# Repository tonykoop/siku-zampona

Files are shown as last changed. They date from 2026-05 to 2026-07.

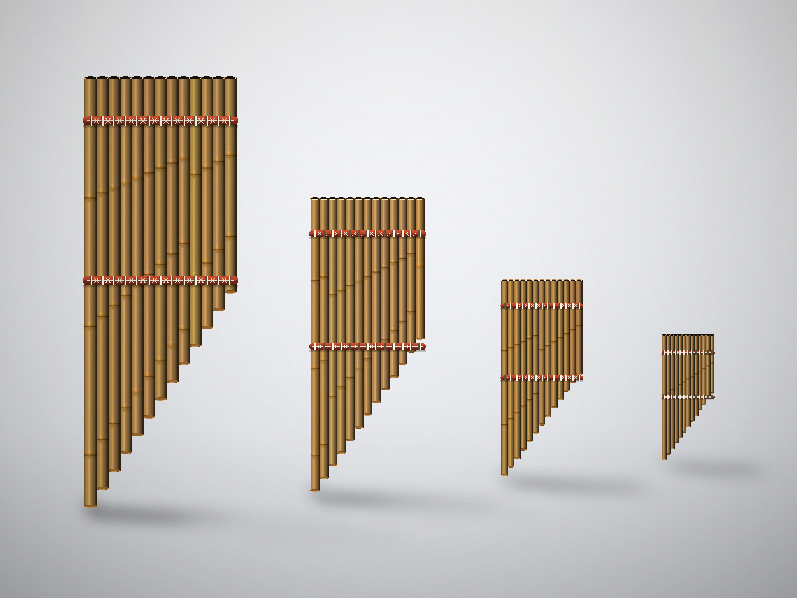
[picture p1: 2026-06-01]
images/family-group.png

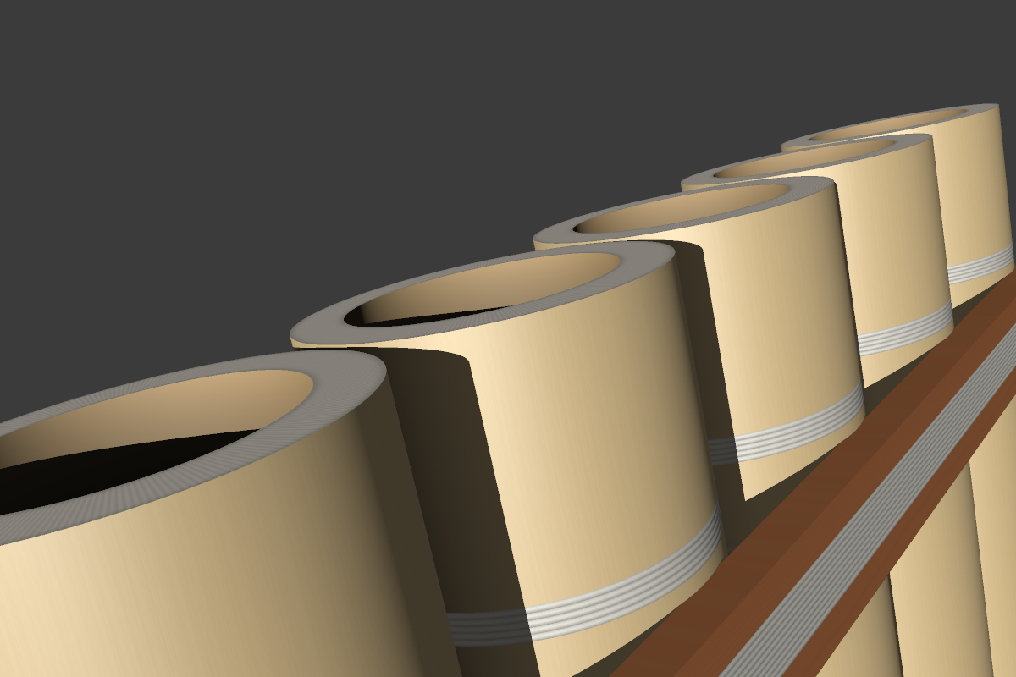
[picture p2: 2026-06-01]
images/macro/blow-edge-tube-mouths.png

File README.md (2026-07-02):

# Siku (Zampoña)

**Status:** L2 V5 build-packet candidate · Heifer Zephyr · instrument-maker-v4 · packet v4.3 · 2026-05-08

Engineering documentation for the *siku* (Aymara: *siku'*, Spanish: *zampoña*) — the Andean panpipe, built as a four-member family in a complete v4.3 root-mode packet.

The siku is played in interlocking arka/ira pairs. Neither rank alone contains the full scale — two players weave a melody together, embodying *yanantin*, the Aymara philosophy of complementary pairing.

---

## Family Overview

| Member | Key | Bore ID | OD | Tubes | Longest | Shortest | Frame Width |
|---|---|---|---|---|---|---|---|
| Toyo (bass) | G3 | 0.750" | 1.000" | 13 | 22.646" | 7.064" | 13.750" |
| **Zanka (tenor)** | **C4** | **0.625"** | **0.821"** | **13** | **16.961"** | **4.814"** | **11.423"** |
| Malta (alto) | G4 | 0.500" | 0.658" | 13 | 11.315" | 3.261" | 9.304" |
| Chili (soprano) | A4 | 0.375" | 0.493" | 13 | 7.565" | 1.982"⚠ | 7.159" |

**Primary build target: Zanka.** The Zanka is the main melodic voice in traditional Andean ensembles and the best starting point for a first build.

⚠ Chili Arka-7 (F#6, 1.982" / 50mm) is at the practical playability limit — see `risks.md` AC-04. Consider building the Chili as an 11-tube instrument.

---

## Arka / Ira Split (Zanka example)

| Rank | Tubes | Notes | Semitone offsets |
|---|---|---|---|
| Arka (leader ♀) | 7 | G3 B3 D4 F4 A4 C5 E5 | 0 4 7 10 14 17 21 |
| Ira (follower ♂) | 6 | A3 C4 E4 G4 B4 D5 | 2 5 9 12 16 19 |

Combined: G Mixolydian scale (G A B C D E F♮ G A B C D E)

---

## Tube Length Formula

```
L_calc  = 13552 / (4 × f_hz) − 0.82 × bore_ID
L_cut   = L_calc + 3/16"    (trim allowance)
```

- Speed of sound: 13,552 in/s at 68°F
- End correction: 0.82 × bore_ID (empirical; bundles embouchure effects)
- Stopped pipe: odd harmonics only (1f, 3f, 5f …)
- Tuning: A4 = 440 Hz, equal temperament

Sanity check: `L_calc(A4, bore=0.625") = 13552/(4×440) − 0.82×0.625 = 7.188"`

---

## Packet Contents

| File | Description |
|---|---|
| `design.md` | Governing model, provenance, tube length tables, arka/ira split |
| `family-spec.csv` | All 4 members with bore, wall, tube lengths, Hz values |
| `bom.csv` | Full bill of materials |
| `sourcing.csv` | Suppliers with substitute risk ratings |
| `cut-list.csv` | 52 tube cuts + 4 frame rail cuts |
| `validation.csv` | Per-tube validation targets (Hz, cents tolerance) |
| `assembly-manual.md` | 8-phase build manual |
| `risks.md` | 11 structured risks with verification tests |
| `jig-decision.md` | Fixture selection for each manufacturing operation |
| `cnc/setup-sheet.md` | Machine datums, tooling, release checks for all operations |
| `cnc/operations.csv` | Machine-readable operation list |
| `wolfram/instrument-model.wl` | Interactive tube-length explorer (Wolfram Mathematica) |
| `drawings/` | 10 dimensioned SVG drawings |
| `site/index.html` | Build-log site — open in browser |
| `resources.md` | Acoustic and ethnomusicological references |
| `photo-shotlist.md` | 36-shot photo list |
| `supplier-rfq.md` | RFQ templates for materials |
| `siku-zampona-design-table.xlsx` | Master design table (all 4 members) |
| `cad/siku-zampona.scad` | Parametric OpenSCAD master — two-rank closed-tube envelope (`pending_measurement`) |
| `evolution/` | Evolution-pipeline Stage 0 intake (manifest, design-intent, revision register) |

---

## Build in Brief

1. **Verify stock** — measure bore ID and OD of all incoming bamboo or PVC; record in `validation.csv`
2. **Cut tubes** — story stick method (bamboo) or digital stop (PVC); 52 tubes total across 4 members
3. **Seal ends** — pour beeswax plug to 3/8" depth; stand in plywood sealing fixture while curing
4. **First-pass tuning** — measure all tubes with chromatic tuner; record deviation in cents
5. **Mill frame rails** — CNC-route 13 tube pockets in cherry/walnut rail; pocket width = OD − 0.005"
6. **Bind** — seat tubes in rail pockets; wrap with waxed cord; square-knot at ends
7. **Trim-tune** — file/saw open ends to ±5 cents; update `validation.csv`
8. **Finish** — Danish oil on rails; tung oil wipe on bamboo; photograph

---

## Related Repos

- [tonykoop/instrument-maker](https://github.com/tonykoop/instrument-maker) — parent catalog and skill
- [tonykoop/transverse-flute](https://github.com/tonykoop/transverse-flute) — stopped-pipe family baseline
- [tonykoop/gemshorn](https://github.com/tonykoop/gemshorn) — vessel-flute family; reference for `family-spec.csv` format

---

## Cultural Provenance

The siku is a living cultural artifact of the Aymara and Quechua peoples of Bolivia and Peru, with a documented history extending to at least 1500 BCE (Tiwanaku, Nazca archaeological sites).

This repository documents a **contemporary workshop interpretation** built using modern CNC and PVC/bamboo materials. It makes no claim of cultural authenticity.

Before writing public-facing documentation, captions, or README text for forks, please read:
- Thomas Turino — *Moving Away from Silence* (Chicago, 1993): essential ethnography of siku in Aymara culture
- `resources.md §Provenance` — five-point guidance checklist in this packet
- Describe the instrument as "Andean Aymara/Quechua in origin" (not "Incan" or generically "South American")
- Acknowledge *yanantin* — the interlocking duet design is not decorative; it embodies a cultural philosophy

---

## License

[CC BY 4.0](LICENSE) — engineering documentation only. Attribution: Tony Koop / Heifer Zephyr.  
This license covers the build packet. It is not a claim of ownership over the siku tradition.

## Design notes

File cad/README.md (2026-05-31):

# Siku (Zampoña) — CAD

**Refs:** https://github.com/tonykoop/siku-zampona/issues/1
Generated: 2026-05-19

This folder is a placeholder. No native CAD model lives here yet.

## Current Dimensional Authority

Until reviewed native CAD lands in this folder, the authoritative dimensional
sources for the siku family — in priority order — are:

1. **`siku-zampona-design-table.xlsx`** — the parametric design table
   extracted from the master Musical Instruments workbook. Source of every
   tube length, bore, frame width, and family-member row.
2. **`wolfram/instrument-model.wl`** + **`wolfram-starter.wl`** — Manipulate
   model implementing the stopped-pipe formula
   `L_calc = 13552 / (4·f) − 0.82·bore_ID`. Source of truth for sensitivity
   sweeps and end-correction reasoning.
3. **`drawings/siku-{toyo,zanka,malta,chili}-{elevation,frame}.svg`,
   `siku-family-overview.svg`, `siku-tube-section.svg`** — dimensioned SVG
   drawings for each family member, plus the cross-section and the
   family-overview comparison sheet.
4. **`cut-list.csv`** — concrete numeric envelope per tube, derived from
   items 1–3.

## What Belongs Here Later

This folder is reserved for native CAD that an outside builder can open
and re-mesh:

- A SolidWorks design-table workbook driven from the canonical template
  documented at the instrument-maker-v4 SolidWorks reference for siku
  (`assets/solidworks/family-templates/siku-zampona-design-table.csv`).
- STEP exports of each family member's frame and tube layout.
- Optionally, F3D or Fusion 360 native, OnShape JSON exports, or
  parametric OpenSCAD source if a CAD pivot away from SolidWorks happens.

Any binary CAD file landed here must be paired with a sibling text export
(STEP, IGES, STL, or OpenSCAD source) so that the geometry is reviewable
without the proprietary tool.

## Honesty Rules

The following rules bind every future PR that adds files to this folder:

- A `.glb`, render, or screenshot is **not** CAD; it belongs in
  `images/`.
- A DXF marked "review scaffold" is not L3 CAD; mark it explicitly and
  note the residual in `build-packet-status.md`.
- A "SolidWorks model" claim requires the actual `.sldprt`/`.sldasm` file
  *and* a STEP or IGES sibling. Otherwise the row in
  `build-packet-status.md` stays `partial` or `open`.
- A generated visual (Wolfram render, AI image, or marketing illustration)
  must not be filed here. It belongs in `images/` with concept-only
  framing per `visual-bom-brief.md`.

## Cross-References

- `build-packet-status.md` — overall packet readiness; CAD row tracked
  there.
- `drawing-brief.md` — the Strat-quality drawing requirements that any
  future CAD must satisfy.
- `visual-bom-brief.md` — separates fabrication geometry from concept
  visuals.

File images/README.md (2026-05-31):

# Siku (Zampoña) — Images

**Refs:** https://github.com/tonykoop/siku-zampona/issues/1
Generated: 2026-05-19

This folder is a placeholder. No hero photo, concept render, or build photo
lives here yet.

## Photo Plan

The authoritative shot list — what to shoot, in what order, with which
neutral background and which scale reference — lives in
**`photo-shotlist.md`** at the repo root. Read that file before adding any
file to this folder.

`photo-shotlist.md` defines groups RAW, CUT, ASM, FIN, PLAY, and HERO with
explicit shot IDs (RAW-01, CUT-03, etc.). When a real image lands here, it
should be filed under the shot ID, e.g. `images/RAW-01-bamboo-culm.jpg`.

## What Belongs Here

- **Build photos** taken during a real Zanka or family-member build,
  matching shot IDs from `photo-shotlist.md`.
- **Hero photo** of a finished instrument, owned by the photographer with
  licence recorded.
- **Concept renders** clearly framed as concept-only per
  `visual-bom-brief.md`. File these alongside a sibling
  `<filename>.provenance.md` that records the generator (Wolfram, AI tool,
  hand-illustration), the prompt or notebook cell, and the licence
  posture.

## What Does Not Belong Here

- **Native CAD files** — those belong in `cad/`.
- **Dimensioned drawings** — those belong in `drawings/`.
- **Anonymous AI-generated images with no provenance record** — see
  `visual-bom-brief.md` and the v4.3 provenance convention; an image
  without a sibling provenance note must not land here.
- **Photos of historical or museum instruments** without documented
  permission or a clear public-domain trace.

## Honesty Rules

- Until a real photo lands here, `README.md` must not show a hero image
  claiming to depict a built siku from this repo.
- A render of a CAD model is a render, not a photo. Caption accordingly.
- Photos taken during another maker's build must record consent and the
  maker's name.

## Cross-References

- `photo-shotlist.md` — canonical shot list and shot IDs.
- `visual-bom-brief.md` — image-per-row BOM layout requirements.
- `build-packet-status.md` — overall packet readiness; image row tracked
  there.

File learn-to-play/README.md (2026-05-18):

# learn-to-play / Siku/Zampona (G)

Starter songbook for the G siku/zampona panpipe from the build packet. Generated by the sheet-music skill.

The siku splits notes across pipe rows and often across two players. These studies keep the hocket pattern visible and beginner-friendly.

Range: **G4 - B5 core range, with optional upper-row extensions.**

## Folder map
| Folder | Contents |
|---|---|
| `00-warmup-scales/` | Row-to-row range walk, thirds hocket, breath-reset drill |
| `01-easy/` | Three beginner melodies arranged for alternating pipe rows |
| `02-intermediate/` | Two hocket studies for paired ira/arca practice |
| `03-original/` | *Reed Rows Round* - Heifer Zephyr original |
| `fingering-charts.svg` | Pipe-row map and G pentatonic fingering chart |

## Repertoire

### 01-easy
| Tune | Tradition |
|---|---|
| Call and Answer | Original beginner exercise |
| Twinkle Twinkle Little Star | Mozart K.265 theme (1781) |
| Wayfaring Stranger | American folk hymn, public domain |

### 02-intermediate
| Tune | Tradition |
|---|---|
| Two-Row Huayno | Original Andean-style hocket study |
| Pipe Row Canon | Original paired-player study |

### 03-original
**Reed Rows Round** - 32-bar original hocket study, G pentatonic, quarter=96.

## Notes on notation
ABC files use concert pitch. Notes tagged in comments as ira/arca should be split between paired players where possible.

## L2 readiness and known gaps
This starter songbook is ready for L2 review as a playable packet draft: ABC melodies, per-tune notes, static fingering summaries, warmups, and a top-level chart are present. Known gaps: generated audio, MusicXML, LilyPond, MIDI, and printable songsheets are skipped until the shared render dependencies are available; fingering charts need builder review against the final hole layout.

## License
Arrangements MIT-licensed by Tony Koop / Heifer Zephyr. Public-domain tune provenance is listed in each `notes.md`. Original studies are MIT-licensed for performance, recording, arrangement, and adaptation.

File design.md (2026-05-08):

# Siku (Zampoña) — Design Document

**Instrument:** Siku / Zampoña (Andean Panpipe)  
**Family:** 4-member (Toyo bass · Zanka tenor · Malta alto · Chili soprano)  
**Play style:** 2-rank interlocking duet (arka ♀ + ira ♂) or single-player alternating  
**Packet version:** v4.3 root-mode  
**Date:** 2026-05-08  
**Workbook:** `siku-zampona-design-table.xlsx`

---

## 1. Cultural Provenance

The siku (Aymara: *siku'*; Spanish: *zampoña*) is the pre-Columbian panpipe of the Andean altiplano, with archaeological examples dating to at least 1500 BCE from Tiwanaku-culture sites in present-day Bolivia and Peru. The instrument is central to the Aymara philosophical concept of **yanantin** — complementarity or paired wholeness — expressed musically through the interlocking duet technique in which two players each hold one rank and together produce a continuous melody.

Traditional materials: *cañahueca* bamboo (giant Andean cane, *Guadua chacoensis*) or *suri* bamboo. Tubes sealed at the lower end with a natural node or with beeswax. Rows bound with cord (traditionally alpaca or llama fiber) and sometimes framed between two parallel wooden rails.

Contemporary builders use PVC, hardwood, or aluminium tubing where bamboo is not available. This packet covers all three substrate options, with bamboo as the default.

### Traditions and ensemble contexts

| Tradition | Region | Tuning | Notes |
|---|---|---|---|
| Siku de Pares | Bolivian altiplano | Diatonic major, slight sharp tendency | Paired arka+ira, played outdoors |
| Siku de la Costa | Peruvian coast | Pentatonic variants | Smaller size, indoor context |
| Sikuri conjunto | Bolivia, Peru | 4–6 instrument sizes | Full ensemble from Toyo to Chili |
| Contemporary workshop | Global | Equal temperament | CNC/lathe bore, reproducible |

---

## 2. Governing Physics Model

### 2.1 Stopped Pipe

Each siku tube is a **cylindrical closed pipe** — closed at one end (bottom node or wax plug), open at the other (blow end). The fundamental frequency:

```
f = c / (4 × L_eff)
```

where `L_eff` is the **effective acoustic length** = physical tube length + open-end correction:

```
L_eff = L_physical + ΔL_end
ΔL_end ≈ 0.82 × bore_diameter   (Tony's empirical convention, ≈ 0.41 × r open-end correction)
```

Solving for the physical tube length to cut:

```
L_physical = c / (4 × f) - 0.82 × bore_ID
```

**Speed of sound:** `c = 13,552 in/s` at 68°F / 20°C (Tony's shop standard).  
Temperature sensitivity: ±5°F shifts pitch by approximately ±0.9 cents. Validate in the shop at build temperature.

**Overtone series:** Stopped pipe produces only **odd harmonics** (1f, 3f, 5f, 7f…), giving the characteristic hollow, breathy tone color. This is the acoustic signature of the siku vs. open-pipe flutes that produce all harmonics.

### 2.2 Tuning Trim Allowance

All physical tube lengths in this packet include a **+3/16" (0.1875") trim allowance**. Final tuning is achieved by trimming from the open (blow) end. Tubes should never be lengthened after cutting — seal first, measure against a chromatic tuner, then trim in ≤1/32" increments.

### 2.3 Arka / Ira Split

The 13 tubes of a standard siku are divided into two ranks:

| Rank | Role | Tubes | Semitone offsets from root |
|---|---|---|---|
| **Arka** | leader (♀) | 7 tubes | 0, 4, 7, 10, 14, 17, 21 |
| **Ira** | follower (♂) | 6 tubes | 2, 5, 9, 12, 16, 19 |

Combined and sorted: `0, 2, 4, 5, 7, 9, 10, 12, 14, 16, 17, 19, 21`  
This gives **Mixolydian mode** (major scale with ♭7), spanning nearly 2 octaves. The "siku key" convention: the key letter names the **5th semitone above the root** (the 4th tube of the combined scale, which is the perfect fourth).

> Example: Root = D3 → siku key = G3 (D3 + 5 semitones).

### 2.4 Siku Key Naming Convention

```
siku_key_midi = root_midi + 5
```

| Size Class | Root Note | MIDI | Siku Key |
|---|---|---|---|
| Toyo (bass) | D3 | 38 | G3 |
| Zanka (tenor) | G3 | 43 | C4 |
| Malta (alto) | D4 | 50 | G4 |
| Chili (soprano) | A4 | 57 | D5 |

---

## 3. Family Specification

Four size classes cover the full Andean sikuri ensemble range. See `family-spec.csv` for complete per-member data.

### 3.1 Physical Dimensions

| Member | Size Class | Bore ID (in) | Wall (in) | OD (in) | Root Note | Siku Key |
|---|---|---|---|---|---|---|
| Toyo | Bass | 0.750 | 0.125 | 1.000 | D3 | G3 |
| Zanka | Tenor | 0.625 | 0.098 | 0.821 | G3 | C4 |
| Malta | Alto | 0.500 | 0.079 | 0.658 | D4 | G4 |
| Chili | Soprano | 0.375 | 0.059 | 0.493 | A4 | D5 |

### 3.2 Tube Length Tables

All lengths in inches. `L_calc` = formula result. `L_cut` = L_calc + 3/16" trim allowance.

#### Toyo (Bass) — Root D3 / Siku Key G3 / Bore 0.750"

| Tube | Note | Freq (Hz) | L_calc (in) | L_cut (in) |
|---|---|---|---|---|
| Arka 1 | D3 | 146.83 | 22.459 | 22.646 |
| Arka 2 | F#3 | 185.00 | 17.699 | 17.886 |
| Arka 3 | A3 | 220.00 | 14.785 | 14.973 |
| Arka 4 | C4 | 261.63 | 12.335 | 12.522 |
| Arka 5 | E4 | 329.63 | 9.663 | 9.851 |
| Arka 6 | G4 | 392.00 | 8.028 | 8.215 |
| Arka 7 | B4 | 493.88 | 6.245 | 6.432 |
| Ira 1 | E3 | 164.81 | 19.942 | 20.129 |
| Ira 2 | G3 | 196.00 | 16.671 | 16.858 |
| Ira 3 | B3 | 246.94 | 13.105 | 13.292 |
| Ira 4 | D4 | 293.66 | 10.922 | 11.109 |
| Ira 5 | F#4 | 369.99 | 8.542 | 8.729 |
| Ira 6 | A4 | 440.00 | 7.085 | 7.272 |

**Longest:** 22.459" (Arka 1) · **Shortest:** 6.245" (Arka 7) · **Frame width:** 13.750"

#### Zanka (Tenor) — Root G3 / Siku Key C4 / Bore 0.625"

| Tube | Note | Freq (Hz) | L_calc (in) | L_cut (in) |
|---|---|---|---|---|
| Arka 1 | G3 | 196.00 | 16.773 | 16.961 |
| Arka 2 | B3 | 246.94 | 13.207 | 13.395 |
| Arka 3 | D4 | 293.66 | 11.024 | 11.212 |
| Arka 4 | F4 | 349.23 | 9.189 | 9.376 |
| Arka 5 | A4 | 440.00 | 7.188 | 7.375 |
| Arka 6 | C5 | 523.25 | 5.962 | 6.150 |
| Arka 7 | E5 | 659.26 | 4.627 | 4.814 |
| Ira 1 | A3 | 220.00 | 14.888 | 15.075 |
| Ira 2 | C4 | 261.63 | 12.437 | 12.625 |
| Ira 3 | E4 | 329.63 | 9.766 | 9.953 |
| Ira 4 | G4 | 392.00 | 8.130 | 8.318 |
| Ira 5 | B4 | 493.88 | 6.347 | 6.535 |
| Ira 6 | D5 | 587.33 | 5.256 | 5.443 |

**Longest:** 16.773" (Arka 1) · **Shortest:** 4.627" (Arka 7) · **Frame width:** 11.423"

#### Malta (Alto) — Root D4 / Siku Key G4 / Bore 0.500"

| Tube | Note | Freq (Hz) | L_calc (in) | L_cut (in) |
|---|---|---|---|---|
| Arka 1 | D4 | 293.66 | 11.127 | 11.314 |
| Arka 2 | F#4 | 369.99 | 8.747 | 8.934 |
| Arka 3 | A4 | 440.00 | 7.290 | 7.478 |
| Arka 4 | C5 | 523.25 | 6.065 | 6.252 |
| Arka 5 | E5 | 659.26 | 4.729 | 4.917 |
| Arka 6 | G5 | 783.99 | 3.911 | 4.099 |
| Arka 7 | B5 | 987.77 | 3.020 | 3.207 |
| Ira 1 | E4 | 329.63 | 9.868 | 10.056 |
| Ira 2 | G4 | 392.00 | 8.233 | 8.420 |
| Ira 3 | B4 | 493.88 | 6.450 | 6.637 |
| Ira 4 | D5 | 587.33 | 5.358 | 5.546 |
| Ira 5 | F#5 | 739.99 | 4.168 | 4.356 |
| Ira 6 | A5 | 880.00 | 3.440 | 3.627 |

**Longest:** 11.127" (Arka 1) · **Shortest:** 3.020" (Arka 7) · **Frame width:** 9.304"

#### Chili (Soprano) — Root A4 / Siku Key D5 / Bore 0.375"

| Tube | Note | Freq (Hz) | L_calc (in) | L_cut (in) |
|---|---|---|---|---|
| Arka 1 | A4 | 440.00 | 7.393 | 7.580 |
| Arka 2 | C#5 | 554.37 | 5.804 | 5.991 |
| Arka 3 | E5 | 659.26 | 4.832 | 5.019 |
| Arka 4 | G5 | 783.99 | 4.014 | 4.201 |
| Arka 5 | B5 | 987.77 | 3.122 | 3.310 |
| Arka 6 | D6 | 1174.66 | 2.577 | 2.764 |
| Arka 7 | F#6 | 1479.98 | 1.982 | 2.169 |
| Ira 1 | B4 | 493.88 | 6.552 | 6.740 |
| Ira 2 | D5 | 587.33 | 5.461 | 5.648 |
| Ira 3 | F#5 | 739.99 | 4.271 | 4.458 |
| Ira 4 | A5 | 880.00 | 3.542 | 3.730 |
| Ira 5 | C#6 | 1108.73 | 2.748 | 2.936 |
| Ira 6 | E6 | 1318.51 | 2.262 | 2.450 |

**Longest:** 7.393" (Arka 1) · **Shortest:** 1.982" (Arka 7) · **Frame width:** 7.159"

> ⚠️ **Chili Arka 7 (F#6 = 1.982"):** This 50 mm tube is at the practical lower limit for panpipe embouchure control. Traditional ensembles often omit the highest 1–2 tubes of the Chili. Confirm playability before including in a build. See `risks.md` #AC-04.

---

## 4. Binding and Frame Layout

### 4.1 Tube Array Geometry

Tubes are arranged in descending-length order, longest at left (bass), shortest at right (treble). The two ranks (arka and ira) are bound as separate instruments; in duet play, the players hold one rank each side by side.

**Standard tube spacing:** OD + 1/16" (0.0625") gap between tube centerlines.  
Tubes align flush at the blow end (top). A stepped profile descends to the right.

**Frame cross-section:**

```
[Top rail] ────────────────────────────────────
  ○  ○  ○  ○  ○  ○  ○  ○  ○  ○  ○  ○  ○    ← 13 tubes (arka 7 + ira 6)
[Bottom rail] — stepped or cut to tube profile
```

### 4.2 Binding Methods

| Method | Description | Traditional? | Durability |
|---|---|---|---|
| Cord wrap | Waxed cotton or alpaca cord, 2–4 bands | Yes | Good |
| Frame lash | Tubes between two thin wooden rails, cord lashed | Semi-traditional | Better |
| CNC frame notch | Rails with individual tube pockets routed in | Contemporary | Best alignment |
| Epoxy + frame | Rails glued to tubes | Workshop/contemporary | Best (non-reversible) |

**Recommended for CNC build:** CNC-notched frame. Route tube pockets ≈ 1/3 OD depth into the face of each rail. Rail thickness: 3/8" to 1/2". Rail width: 1" to 1.5". Species: cherry, walnut, or maple.

### 4.3 Frame Dimensions Summary

| Member | # Tubes | OD (in) | Gap (in) | Frame Width (in) | Rail Length (in) |
|---|---|---|---|---|---|
| Toyo | 13 | 1.000 | 0.063 | 13.750 | 13.750 + 0.5 overhang each end |
| Zanka | 13 | 0.821 | 0.063 | 11.423 | 11.423 + 0.5 overhang |
| Malta | 13 | 0.658 | 0.063 | 9.304 | 9.304 + 0.5 overhang |
| Chili | 13 | 0.493 | 0.063 | 7.159 | 7.159 + 0.5 overhang |

### 4.4 Tube Sealing

Closed end (bottom): options in order of traditionality and performance:

1. **Natural bamboo node** — bamboo blank cut so a node falls at the correct closed-end position. Best tone, traditional. Requires careful blank selection.
2. **Beeswax plug** — melt beeswax into tube bottom, let harden. Used for tuning adjustment. Also used to close PVC or bamboo without a node.
3. **Wood dowel plug** — turned to press fit, glued. Good for hardwood or PVC tubes.
4. **Cork plug** — easy, reversible. Slight tone dampening at the closed end (adds small effective length → slight pitch-flat tendency). Correct by trimming 1/16" from open end if using cork.

**Wax plug acoustic note:** Beeswax has high acoustic impedance at this scale; the reflection at the wax-air boundary is nearly ideal for a stopped pipe. Cork is slightly less reflective. Cork-plugged tubes may run ~5–10 cents flat vs. wax/node — account for this in final trim.

---

## 5. CNC and Lathe Notes

See `cnc/setup-sheet.md` for the full operation plan.

### 5.1 Bamboo Blanks

- Select blanks with consistent internal bore (cañahueca splits most predictably with 3–4 mm wall thickness in the Andean species).
- Bore diameter should match the design table. Natural bamboo bore varies ±1–2 mm; oversized bore raises pitch (shorter effective length correction), undersized lowers it.
- Use headstock-driven deep-bore drilling (see `references/techniques/headstock-driven-deep-bore-drilling.md`) when boring hardwood or PVC blanks to the target bore ID from solid stock.

### 5.2 Hardwood or PVC Tubes

For a CNC-shop build without cane:

- **PVC Schedule 40 pipe:** widely available; bore IDs match close enough for Zanka (3/4" nominal ≈ 0.824" ID, use for Toyo; 1/2" nominal ≈ 0.622" ID for Zanka). Verify actual ID with calipers before computing cut lengths.
- **Hardwood bore:** bore blanks on the lathe or with headstock-driven drill; cherry, walnut, or maple all work. Seal with shellac or wax inside bore before final assembly.

### 5.3 Frame CNC Operations

1. Mill tube-pocket profile in each rail blank (1 op per rail, router table or CNC).
2. Sand pocket bottoms flat for consistent tube seating depth.
3. Pre-drill cord holes through rail ends.
4. Finish rail: 3 coats shellac or danish oil.

---

## 6. Tuning Validation

See `validation.csv` for per-tube rows.

### 6.1 Prediction Accuracy

The stopped-pipe formula is accurate to within 5–10 cents for bamboo at nominal bore diameter. Known sources of variation:

- **Bore taper:** Natural bamboo tapers slightly. A narrowing bore raises pitch slightly.
- **Temperature:** ±5°F ≈ ±0.9 cents.
- **Closed-end plug type:** Cork +5–10 cents flat vs. wax/node.
- **Embouchure gap:** Air-column effective length depends on blow angle and lip position. A trained player adjusts to ±10 cents. This is not a manufacturing defect.

### 6.2 Trim Protocol

1. Cut all tubes to L_cut (formula + 3/16" trim allowance).
2. Seal closed ends with wax or fit plugs.
3. Measure with chromatic tuner (Korg CA-1 or equivalent) at 68°F, 40–50% RH.
4. Record measured frequency and cents error in `validation.csv`.
5. Trim open end in ≤1/32" increments. Re-measure. Repeat until ≤±5 cents.

---

## 7. Open Items and Assumptions

| # | Item | Status |
|---|---|---|
| DES-01 | Bore tolerances for bamboo: actual vs. nominal | TBD — measure blanks |
| DES-02 | Cork plug acoustic correction factor | TBD — empirical, add ±1/16" to open-end trim |
| DES-03 | Rail species and thickness (CNC frame) | Assumed cherry 3/8" — confirm available stock |
| DES-04 | Arka 7 Chili (F#6, 1.98") playability | TBD — prototype test |
| DES-05 | Toyo Arka1 length 22.6" — exceeds typical hand reach | TBD — confirm acceptable for bass register |
| DES-06 | Measured K2 corrections for bamboo bore | None available; marked first-order estimates |
| DES-07 | Speed of sound at shop temperature during build | Measure shop temp; correction = c×√(T_K/293.15) |

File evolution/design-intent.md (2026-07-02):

# Design Intent — siku-zampona rev A

- Master CAD: `cad/siku-zampona.scad` (sha256: 2a5465974eeee7d500f8a04d56a068248ebea6229cdf85e638d22fdd83c4d857), driven by `siku-zampona-design-table.xlsx` (sha256: abeaa760751735b362ce462226c74f201f4b278d29879b2581cf043e53429e08) and `family-spec.csv`.
- Function: The *siku* (Aymara: *siku'*, Spanish: *zampoña*) is an Andean panpipe — a set of closed/stopped cylindrical tubes, each open at the blow end and sealed at the bottom (beeswax, bamboo node, or plug), sounding its fundamental as air is directed across the open rim. The 13-tube scale is split across two interlocking ranks — **arka** (leader, 7 tubes) and **ira** (follower, 6 tubes) — that together produce a Mixolydian scale spanning nearly two octaves; no single rank alone carries the full melody. Two players (or one player alternating) weave the tune together, embodying *yanantin*, the Aymara philosophy of complementary pairing — a "Heifer Zephyr" branding identity retained from the packet's cultural-provenance framing. Built as a 4-member family (Toyo bass, Zanka tenor — primary build target, Malta alto, Chili soprano).
- Environment: hand-held/breath-driven acoustic instrument; outdoor/altiplano use historically, indoor/workshop use for this packet. Bamboo bore and length are temperature/humidity sensitive (risks.md AC-02).
- Target qty: 1 (prototype — Zanka). Deadline: TBD. Budget/unit ceiling: TBD.

## Critical dimensions (carry tolerances)

| Feature | Nominal (Zanka) | Tolerance | Why critical | Source |
| --- | --- | --- | --- | --- |
| Bore ID | 0.625 in | measure actual bore before cutting | sets end correction, hence pitch | family-spec.csv bore_id_in; risks.md AC-01 |
| OD | 0.821 in | — | frame-pocket fit | family-spec.csv od_in (= bore + 2×wall) |
| Arka 1 (root, G3) tube length | 16.961 in (L_cut) | trim in <=1/32" increments to +/-5 cents | lowest arka pitch, sets rank scale anchor | family-spec.csv arka1_L_cut; design.md sec 2.1-2.2 |
| Arka 7 (E5) tube length | 4.814 in (L_cut) | same trim protocol | highest arka pitch | family-spec.csv arka7_L_cut |
| Ira 1 (A3) tube length | 15.075 in (L_cut) | same trim protocol | lowest ira pitch | family-spec.csv ira1_L_cut |
| Ira 6 (D5) tube length | 5.443 in (L_cut) | same trim protocol | highest ira pitch | family-spec.csv ira6_L_cut |
| Combined 13-tube frame width | 11.423 in | — | rail/pocket layout if bound as one frame | family-spec.csv frame_width_in; cad/siku-zampona.scad computed cross-check (exact match) |
| End-correction coefficient | 0.82 x bore_ID | measurement_required — see AC-05 | governs every tube length in the family | design.md sec 2.1; risks.md AC-05 (unvalidated empirical convention, ~2x physics unflanged value) |

## Incidental (free for DFM)

- Tube array visual spacing between the arka/ira rows in the CAD envelope (this master uses a 1.5 in visualization gap; not a lashing spec).
- Frame rail species/finish choice within bom.csv options (cherry/walnut, Danish oil vs. shellac).
- Binding cord color/material within bom.csv Buy options.

## Must-nots (DFM may never violate)

- Tube lengths stay equation-driven (`L = c/(4f) - 0.82*bore_ID`, design.md sec 2.1); never hand-placed or scaled from a lossy mesh export.
- Do not omit the +3/16" trim allowance — final tuning is only ever removed from the open end, never added back (design.md sec 2.2; tubes "should never be lengthened after cutting").
- Do not substitute a different end-correction coefficient without re-validating against a built/measured prototype and logging the delta (risks.md AC-05).
- Do not commit to a full Chili (soprano) build without first prototyping Arka 7 (F#6, 1.982" calc length) in isolation — it is at the practical embouchure-length limit (risks.md AC-04).
- Do not assume bamboo bore matches the nominal design-table value; measure actual bore at the blow end of each tube before finalizing cut length (risks.md AC-01).

## Material intent

- Preferred: bamboo cañahueca (traditional) per member — Toyo 1-in nominal, Zanka 3/4-in nominal, Malta 1/2-in nominal, Chili 3/8-in — per bom.csv part rows (SKZ-*-01/02).
- Acceptable subs: PVC Schedule 40 (bore+bore drilled) or hardwood bored on lathe, per design.md sec 5.2 and bom.csv make/buy notes.
- Frame rails: cherry or walnut S4S, per bom.csv (SKZ-*-04/05).
- Bottom seal: beeswax pour plug (food-grade/filtered) per bom.csv (SKZ-*-03); bamboo node preferred where available, especially for Chili.
- Forbidden: none recorded.

## Stage status

Stage 0 intake complete 2026-07-01. Gate A (Alpha shop compile) NOT yet run — no concessions logged, nothing presented as shippable.

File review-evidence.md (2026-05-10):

# Review Evidence

Refs #1.

## Round 3 Scope

- Re-validated the existing root-mode packet as part of the wind build-packet
  sweep.
- Existing packet already includes pipe-array tuning, arka/ira split, bamboo or
  PVC material path, Andean breath/interlocking technique notes, resources,
  jig decisions, CNC setup sheet, and Wolfram model source.
- This packet does not claim measured L3/build-ready status.

## Gates Before Close

- Build at least the Zanka member.
- Record every tube frequency, trim amount, plug depth, breath response, and
  final cents error in `validation.csv`.
- Confirm cultural/provenance language during human release review.

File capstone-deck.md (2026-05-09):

# Siku (Zampoña) — Capstone Deck

**Heifer Zephyr · instrument-maker-v4 · packet v4.3 · 2026-05-08**

---

# Project Intent

The siku is the Andean panpipe — one of the oldest continuously played instruments in the world, with archaeological specimens from Tiwanaku and Nazca dating to at least 1500 BCE. It is played in interlocking arka/ira pairs, embodying *yanantin*, the Aymara philosophy of complementary pairing: neither rank alone contains the full scale; two players weave a single melody together.

This project documents a contemporary workshop interpretation of the siku as a four-member family (Toyo bass / Zanka tenor / Malta alto / Chili soprano), built using parametric acoustic design, CNC-routed cherry frame rails, and bamboo or PVC tubes. The primary build target is the Zanka (key of C, tenor voice), the traditional melodic lead in Andean ensembles.

**Goal:** A fully-documented, reproducible build packet for the complete siku family, publishable as a GitHub portfolio instrument and buildable from this packet alone.

---

# Instrument Overview

The siku is a stopped cylindrical pipe instrument. Each tube is open at the top (blow end) and closed at the bottom (beeswax plug or natural bamboo node). Stopped pipes produce only odd harmonics — 1f, 3f, 5f — giving the siku its characteristic hollow, fundamental-rich timbre.

The instrument is played by blowing across the open end of each tube. Pitch is fixed at manufacture; the only playing variable is embouchure angle. A complete instrument consists of two bound ranks (arka and ira) played by two performers or by a single player alternating between ranks.

Family overview

---

# Family Specification

| Member | Key | Bore | OD | Longest Tube | Frame Width | Primary Use |
|---|---|---|---|---|---|---|
| Toyo | G3 | 0.750" | 1.000" | 22.646" | 13.750" | Bass ensemble voice |
| **Zanka** | **C4** | **0.625"** | **0.821"** | **16.961"** | **11.423"** | **Primary melodic voice** |
| Malta | G4 | 0.500" | 0.658" | 11.315" | 9.304" | Alto ensemble voice |
| Chili | A4 | 0.375" | 0.493" | 7.565" | 7.159" | Soprano ensemble voice |

All four members are acoustically designed from the same formula; only bore diameter and root pitch change.

---

# Acoustic Design

The core formula for all 52 tubes across the four-member family:

```
L_calc = 13552 / (4 × f_hz) − 0.82 × bore_ID
L_cut  = L_calc + 3/16"  (tuning trim allowance)
```

- **Speed of sound:** 13,552 in/s (68°F shop standard)
- **End correction:** 0.82 × bore_ID (empirical; bundles embouchure effects)
- **Stopped pipe:** odd harmonics only (1f, 3f, 5f…)
- **Tuning:** A4 = 440 Hz, equal temperament

Sanity check: `L_calc(A4=440Hz, bore=0.625") = 13552/(4×440) − 0.82×0.625 = 7.188"` ✓

The 0.82 end-correction coefficient is an empirical convention (vs. the theoretical 0.3×d) that bundles embouchure geometry effects and produces well-tuned tubes without per-player adjustment. Risk AC-05 in `risks.md` documents the accuracy envelope.

---

# Arka / Ira Split

The interlocking split is the defining acoustic and cultural feature of the siku:

| Rank | Role | Notes (Zanka) | Semitone offsets from root |
|---|---|---|---|
| Arka (leader ♀) | 7 tubes | G3 B3 D4 F4 A4 C5 E5 | 0 4 7 10 14 17 21 |
| Ira (follower ♂) | 6 tubes | A3 C4 E4 G4 B4 D5 | 2 5 9 12 16 19 |

Combined: G Mixolydian scale (G A B C D E F♮ G A B C D E). Neither rank alone is playable as a melody; they are designed to be played together.

This split is not an engineering choice — it is *yanantin* made physical.

---

# Tube Layout — Zanka

Zanka elevation drawing

The 13 Zanka tubes span G3 (196 Hz, 17.15") to E5 (659 Hz, 4.81") across a frame width of 11.423". Arka tubes are positioned at semitone offsets {0,4,7,10,14,17,21}; Ira at {2,5,9,12,16,19}.

---

# Cross-Section Detail

Tube cross-sections

All four family members share the same stopped-pipe acoustics. The difference is bore diameter, which scales the tube lengths by a constant factor (plus a small end-correction offset). Wall thickness is sized to maintain structural integrity at the tube spacing used in each rank.

---

# Frame and Binding

Each rank consists of 13 tubes held in two cherry or walnut frame rails. Rails are CNC-routed with pocket width = tube OD − 0.005" (light interference before glue), pocket depth = OD/3, and pitch = OD + 1/16" (one tube gap between centers).

Binding cord (waxed linen or nylon) wraps the tube array in 3+ passes per tube and is knotted at the rail ends. No hardware is used — the instrument is entirely wood, bamboo/PVC, beeswax, and cord.

---

# Build Sequence

1. **Stock verification** — measure bore ID and OD; record in `validation.csv`
2. **Tube cutting** — story stick (bamboo) or digital stop (PVC); 52 tubes across 4 members
3. **Closed-end sealing** — beeswax pour in plywood sealing fixtures; 30 min cure
4. **First-pass tuning** — measure all tubes; record cents deviation
5. **Frame rail fabrication** — CNC-route 13 pockets; dry-fit before glue
6. **Assembly and binding** — seat tubes; wrap with waxed cord; square-knot finish
7. **Trim-tuning** — file/saw to ±5 cents; update `validation.csv`
8. **Finishing** — Danish oil on rails; tung oil wipe on bamboo tubes

Full protocol: `assembly-manual.md` · CNC parameters: `cnc/setup-sheet.md`

---

# Manufacturing Notes

**Key jig decisions:**
- Toyo long tubes (22.6"): headstock-driven deep bore on lathe (prevents drill wander)
- Zanka tubes (to 17"): conventional tailstock drill on lathe
- Malta/Chili tubes (to 11"): drill press + V-block
- Frame rail pockets: CNC router preferred; router table + index stops acceptable
- Sealing stand: drilled plywood, one per family member (4 total)

See `jig-decision.md` for full rationale and `cnc/setup-sheet.md` for machine datums and tooling.

---

# Bill of Materials Summary

| Member | Tubes | Frame Rails | Cord + Plugs | Est. Total |
|---|---|---|---|---|
| Toyo | $6.50 | $12.00 | $1.55 | ~$20 |
| Zanka | $5.20 | $10.00 | $1.24 | ~$17 |
| Malta | $4.55 | $8.00 | $0.93 | ~$14 |
| Chili | $3.90 | $7.00 | $0.75 | ~$12 |
| Shared tools | — | — | $28.00 | $28 |

Material cost for a single Zanka arka+ira build: ~$17 (plus $28 shared tools, once). Full four-member family: ~$91 before finish and consumables.

Full BOM: `bom.csv` · Sourcing: `sourcing.csv`

---

# Key Risks and Mitigations

| Risk ID | Description | Severity | Mitigation |
|---|---|---|---|
| AC-04 | Chili Arka-7 (F#6, 1.982") borderline playable | H | Build as 11-tube Chili; omit top 2 tubes |
| AC-01 | Bamboo bore variance (±0.015" typical) | M | Measure all tubes before cutting; adjust L_calc per measured bore |
| AC-02 | Temperature drift (±10°F → ±0.9%) | M | Tune and play at same temperature; note shop temp in validation.csv |
| ST-01 | Rail pocket undersize causing tube cracking | M | First pocket is always a test pocket; verify fit before batch routing |
| ER-01 | Yanantin not explained in public documentation | H | See `resources.md §Provenance`; required before any public publish |

Full risk register: `risks.md` (11 risks total).

---

# Open Items / Next Actions

- [ ] **Photos:** All 36 shots in `photo-shotlist.md` pending. HERO-03 (Zanka arka beauty shot) is the README hero image.
- [ ] **Chili Arka-7 prototype:** Build and test the 1.982" F#6 tube before committing full Chili production. Empirical test resolves risk AC-04.
- [ ] **Wolfram recordings:** Record AudioGenerator output for arka and ira ranks; embed in build-log site.
- [ ] **OpenSCAD model:** `cad/siku-openscad-starter.scad` is TBD per `drawing-brief.md`.
- [ ] **Sourcing confirmation:** Verify current bamboo cañahueca availability; lead time 2–4 weeks for import suppliers.
- [ ] **Validate measured tube lengths:** Once first Zanka prototype is built, fill in `validation.csv` measured_hz column and confirm ±5 cent tolerance across all 13 tubes.

---

# Cultural Provenance

The siku is a living cultural artifact, not simply a historical instrument. Aymara and Quechua communities in Bolivia and Peru continue to build and play siku today.

**Before publishing this build:**
1. Describe as "Andean Aymara/Quechua in origin" — not "Incan" or "South American"
2. Do not claim cultural authenticity — this is a contemporary workshop interpretation
3. Explain *yanantin* — the interlocking duet is not decorative; it is cultural philosophy
4. Do not use "traditional" or "authentic" in marketing or product descriptions
5. The CC BY 4.0 license covers the engineering documentation, not the cultural tradition

Primary reference: Thomas Turino, *Moving Away from Silence* (Chicago, 1993).

---

# Packet Summary

**Repo:** `tonykoop/siku-zampona` · **License:** CC BY 4.0 · **Packet:** v4.3 root-mode

| Deliverable | Status |
|---|---|
| design.md | ✅ Complete |
| family-spec.csv (4 members, 13 tubes each) | ✅ Complete |
| bom.csv / sourcing.csv / cut-list.csv | ✅ Complete |
| validation.csv (per-tube targets) | ✅ Complete |
| assembly-manual.md (8 phases) | ✅ Complete |
| risks.md (11 risks) | ✅ Complete |
| jig-decision.md (5 decisions) | ✅ Complete |
| cnc/setup-sheet.md + operations.csv | ✅ Complete |
| wolfram/instrument-model.wl | ✅ Complete |
| drawings/ (10 SVGs) | ✅ Complete |
| site/index.html | ✅ Complete |
| resources.md + photo-shotlist.md | ✅ Complete |
| Photos | ⏳ Pending build |
| OpenSCAD model | ⏳ TBD |
| Wolfram audio recordings | ⏳ TBD |

Part of the [Heifer Zephyr](https://github.com/tonykoop/instrument-maker) instrument-maker catalog.

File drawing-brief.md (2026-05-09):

# Siku (Zampoña) — Drawing Brief

**Purpose:** Spec for technical drawings in `drawings/` — one SVG per family member per view.  
**Quality bar:** Fender Stratocaster blueprint standard (title block, datums, all critical dimensions, section views).

---

## Drawing List

| File | Member | View | Priority |
|---|---|---|---|
| `drawings/siku-toyo-elevation.svg` | Toyo (Bass) | Front elevation — full tube array, stepped profile | P1 |
| `drawings/siku-toyo-frame.svg` | Toyo (Bass) | Frame rail plan — tube pocket layout, rail dimensions | P1 |
| `drawings/siku-zanka-elevation.svg` | Zanka (Tenor) | Front elevation | P1 |
| `drawings/siku-zanka-frame.svg` | Zanka (Tenor) | Frame rail plan | P1 |
| `drawings/siku-malta-elevation.svg` | Malta (Alto) | Front elevation | P1 |
| `drawings/siku-malta-frame.svg` | Malta (Alto) | Frame rail plan | P2 |
| `drawings/siku-chili-elevation.svg` | Chili (Soprano) | Front elevation | P2 |
| `drawings/siku-tube-section.svg` | All | Tube cross-section detail | P1 |
| `drawings/siku-family-overview.svg` | All 4 | Side-by-side family comparison | P2 |

---

## Per-Drawing Content Requirements

### Front Elevation (per member)

- Full-scale (or 1:2 for Toyo) front view of the complete rank
- Tubes drawn as vertical rectangles, left=longest, right=shortest
- Each tube labeled with: note name, semitone offset from root, and L_cut length
- Overall frame width dimension
- Longest and shortest tube heights dimensioned
- Blow-end datum line (top, flush with rail)
- Title block: instrument + member name + siku key + bore ID + date + revision

### Frame Rail Plan (per member)

- Top view of one rail
- All 13 tube pockets shown with centerline spacing (OD + 1/16" gap)
- Pocket depth noted
- Rail overall dimensions
- 2× cord-lash hole positions near rail ends
- Title block

### Tube Cross-Section Detail

- Single tube cross-section: bore ID, wall thickness, OD
- Beeswax plug depth shown (3/8" for Toyo, 1/4" for small sizes)
- End correction ΔL annotation: "ΔL = 0.82 × bore ID"
- Label: "Closed end (bottom) · Open end (top)"

### Family Overview

- 4 ranks shown side by side at true relative scale
- Labels: Toyo / Zanka / Malta / Chili
- Toyo Arka 1 (22.6") and Chili Arka 7 (2.2") highlighted as range extremes
- Frame width dimension for each

---

## Title Block Template

```
+─────────────────────────────────────────────────────────────+
│ SIKU (ZAMPOÑA)  ·  [MEMBER NAME]  ·  KEY [SIKU KEY]        │
│ Part: [view name]    Scale: [1:1 or 1:2]   Units: inches   │
│ Date: 2026-05-08     Rev: A      Workbook: siku-zampona-    │
│                                   design-table.xlsx          │
│ tonykoop/siku-zampona  ·  CC BY 4.0                         │
+─────────────────────────────────────────────────────────────+
```

---

## Datum Convention

- **Y=0:** Top (blow) end of longest tube = primary datum
- **X=0:** Centerline of longest tube (Arka 1)
- Tube positions numbered left to right: Arka 1 through Arka 7, then Ira 1 through Ira 6

---

## Tolerance Callout Guide

| Feature | Tolerance | Note |
|---|---|---|
| Tube cut length | ±1/32" (0.031") | Trim to pitch; this is pre-trim tolerance |
| Bore ID | ±0.030" for bamboo | Verify with caliper; recalculate if outside tolerance |
| Pocket depth | ±0.010" | Pocket too shallow → tube proud; too deep → tube sunk |
| Pocket spacing | ±0.005" | CNC accuracy; feeds frame width |
| Rail thickness | ±0.005" | Planer accuracy |
| Cord hole dia | 1/8" ± 0.010" | Clearance for lashing needle |

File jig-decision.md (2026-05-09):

# Siku (Zampoña) — Jig Decision Matrix

**Purpose:** Choose the right fixture approach for each siku manufacturing operation before committing to tooling.  
**Packet:** v4.3 · Date: 2026-05-08

---

## Decision 1 — Tube Boring Method (Hardwood or PVC from solid stock)

**Context:** If not using pre-bored bamboo or nominal-bore PVC, you must bore the tube blank to the target bore ID. Three options:

| Option | Method | Pros | Cons | Verdict |
|---|---|---|---|---|
| **A — Drill Press + V-Block** | Mount blank in a V-block on the drill press table. Drill with a brad-point or Forstner bit. | Simple; no lathe needed | Bore wander likely on tubes > 6"; not suitable for Toyo/Zanka long tubes | ✅ Use for Malta and Chili (tubes ≤ 11") |
| **B — Lathe + Jacobs Chuck** | Chuck blank in 4-jaw chuck; bore with twist drill held in tailstock | Good concentricity; standard lathe workflow | Limits blank length to ~2× lathe capacity; requires 4-jaw setup | ✅ Use for Zanka (tubes to 17") |
| **C — Headstock-Driven Deep-Bore** | Spin drill in headstock Jacobs chuck; advance stationary blank with guided tailstock carrier | Correct technique for deep bores; minimal wander | Requires tailstock vise/carrier jig; more setup time | ✅ Use for Toyo (22.6" longest tube) |

**Decision:**
- Toyo → Option C (headstock-driven deep bore)
- Zanka → Option B (lathe) or Option C if lathe travel is insufficient
- Malta → Option A (drill press + V-block)
- Chili → Option A (drill press + V-block)

**Reference:** `references/techniques/headstock-driven-deep-bore-drilling.md`

---

## Decision 2 — Tube Length Marking Jig

**Context:** 52 tubes across 4 size classes, each with a unique length. Risk of mislabeling or incorrect cut length is high without a systematic marking fixture.

| Option | Method | Verdict |
|---|---|---|
| **A — Story Stick** | Cut a master story stick per family member with all 13 tube lengths marked. Transfer marks to each tube. | ✅ Recommended for bamboo builds — fast, tactile, no electronics needed |
| **B — Digital Stop on Miter Saw** | Set digital stop to each length, cut in sequence. | ✅ Recommended for PVC — repeatable for cylindrical stock |
| **C — Mark with Tape Measure Per Tube** | Measure each tube individually against the cut list. | ❌ Error-prone; too slow for 52 tubes |

**Decision:** Use Option A (story stick) for bamboo, Option B (digital stop) for PVC. Always double-check with a caliper after marking, before cutting.

**Story stick spec:**
- Material: 1/4" plywood or MDF, 25" long
- Mark all 13 Toyo lengths; 13 Zanka lengths (separate stick per family member)
- Label each mark with the tube ID (e.g., "T-A1 22.646") and note name
- Store with the packet

---

## Decision 3 — Frame Rail Pocket Routing Fixture

**Context:** 13 evenly-spaced tube pockets per rail; pocket spacing = OD + 1/16" gap. Options:

| Option | Method | Verdict |
|---|---|---|
| **A — CNC Router with G-code** | Generate pocket toolpath in Vectric or Fusion 360 from the frame-width and OD parameters | ✅ Best accuracy; recommended if CNC is available |
| **B — Router Table + Fence + Index Stops** | Set fence to pocket centerline. Use index pins or stop-block sequence to space pockets. | ✅ Acceptable for single builds; more setup time |
| **C — Drill Press + Forstner Bit** | Use Forstner bit equal to OD for circular pockets (vs. rectangular). | ⚠️ Circular pockets are fine for round tubes; need to verify tube OD matches bit diameter exactly |

**Decision:** Use Option A (CNC) with pocket width set to measured tube OD − 0.005". If CNC is unavailable, Option B with a test pocket first.

**CNC parameters (Zanka example):**
- Pocket width = 0.821" (Zanka OD) − 0.005" = 0.816"
- Pocket depth = 0.274" (1/3 of 0.821" OD)
- Pocket length = 1.5" (rail width)
- Spacing: 0.821" + 0.0625" = 0.884" center-to-center
- Total 13 pockets; first center at OD/2 = 0.411" from rail end

---

## Decision 4 — Closed-End Sealing Fixture

**Context:** Tubes must be held vertically and level while beeswax cures. 52 tubes across 4 sessions.

| Option | Method | Verdict |
|---|---|---|
| **A — Drilled Plywood Stand** | Drill 13 holes per stand in a scrap plywood panel matching tube ODs; stand tubes upright while wax pours. | ✅ Recommended; takes 20 minutes to build |
| **B — Sand/Rice Tray** | Stand tubes in a box of sand or rice. | ✅ Works; less repeatable; tubes may lean |
| **C — Individual Clamps** | Hold each tube in a machinist V-block or hand clamp. | ❌ Too slow for 13+ tubes |

**Decision:** Option A (drilled plywood stand). Build one per family member (4 stands, 4 hole diameters). Label each stand with the member ID.

**Stand spec:**
- 3/4" plywood, 6" × 14" (Toyo) down to 4" × 8" (Chili)
- Holes drilled at OD + 0.010" clearance, spaced at pocket-spacing interval
- Clamp stand to bench during wax pour

---

## Decision 5 — Tuning Trim Jig

**Context:** Final pitch adjustment by trimming open end. Need to hold tube perpendicular to saw blade and remove very small increments (≤1/32").

| Option | Method | Verdict |
|---|---|---|
| **A — Miter Saw with Fine-Tooth Blade** | Mark increment with tape; light scoring passes | ✅ Fastest; needs 80T blade for clean cuts |
| **B — Fine File + Sanding Block** | File end square; verify with engineer's square | ✅ Safest (no over-cut risk); slowest |
| **C — Lathe Parting Tool** | Chuck tube; face off with parting tool or facing pass | ✅ Best surface quality; requires lathe setup per tube |

**Decision:** Option A for rough adjustment (>1/16" removal), Option B for final micro-trim (<1/32"). Always sand end flat after each cut.

---

## Jig Build Priority

| Priority | Jig | When needed |
|---|---|---|
| P1 | Story stick × 4 (one per member) | Before any cutting |
| P1 | Sealing stand × 4 (one per member) | Before Phase 3 sealing |
| P2 | CNC pocket toolpath | Before Phase 5 frame fabrication |
| P3 | Tailstock carrier for deep bore (Toyo only) | Before boring hardwood Toyo blanks |

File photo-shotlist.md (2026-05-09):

# Siku (Zampoña) — Photo Shot List

**Packet:** v4.3 · Date: 2026-05-08  
**Use:** Build-log site (`site/index.html`), capstone deck, visual BOM, README hero image  
**Reference pipeline:** `instrument-maker/docs/photo-pipeline.md`

All photos should be shot on a neutral background (grey or linen). Include a ruler or known reference object in at least one shot per group for scale.

---

## Group 1 — Raw Materials (before cutting)

| Shot ID | Subject | Notes | Status |
|---|---|---|---|
| RAW-01 | Full bamboo culm or bundle | Show the natural material; include ruler for scale | ☐ |
| RAW-02 | Bamboo cross-section | Cut end showing bore ID, wall thickness, node | ☐ |
| RAW-03 | PVC pipe alternatives | Lay out all 4 nominal sizes side by side on grey background | ☐ |
| RAW-04 | Cherry/walnut frame rail blanks | S4S boards before milling; show straight grain | ☐ |
| RAW-05 | Beeswax block and cord | Materials lay-flat: beeswax, waxed cord, caliper, tuner | ☐ |

---

## Group 2 — Tube Cutting and Preparation

| Shot ID | Subject | Notes | Status |
|---|---|---|---|
| CUT-01 | Story stick alongside tubes | Story stick with all 13 lengths marked; Zanka tubes laid against it | ☐ |
| CUT-02 | Miter saw cut — bamboo | Fine-tooth blade; close-up of cut end quality | ☐ |
| CUT-03 | 13 Zanka tubes labeled and sorted | All tubes laid out in order (Arka 1 → Ira 6) with note labels visible | ☐ |
| CUT-04 | Bore verification with caliper | Caliper measuring bore ID; digital readout visible | ☐ |
| CUT-05 | Tube end sanding | Sandpaper flat on surface; tube end being squared | ☐ |

---

## Group 3 — Sealing (Closed-End Plug)

| Shot ID | Subject | Notes | Status |
|---|---|---|---|
| SEAL-01 | Sealing stand with tubes | Plywood stand with 13 tubes standing upright, ready for wax pour | ☐ |
| SEAL-02 | Beeswax double boiler setup | Melting beeswax to temperature; thermometer visible | ☐ |
| SEAL-03 | Wax pour into tube | Action shot — wax flowing into upright tube | ☐ |
| SEAL-04 | Completed sealed tube cross-section | Cured wax plug visible from cut-away view (optional) or top-lit | ☐ |
| SEAL-05 | Natural bamboo node comparison | Place wax-sealed PVC tube alongside bamboo-node tube for comparison | ☐ |

---

## Group 4 — Tuning

| Shot ID | Subject | Notes | Status |
|---|---|---|---|
| TUNE-01 | Tuner display and tube | Chromatic tuner showing a note; tube held in playing position near it | ☐ |
| TUNE-02 | Pre-trim measurement — flat lay | All 13 Zanka tubes laid flat beside validation.csv print-out; check marks visible | ☐ |
| TUNE-03 | Trim increment at miter saw | Close-up of 1/32" tape mark; tape measure visible | ☐ |
| TUNE-04 | Final tuned row | All 13 Zanka tubes arranged in play order, validated (±5 cents) | ☐ |

---

## Group 5 — Frame Fabrication

| Shot ID | Subject | Notes | Status |
|---|---|---|---|
| FRAME-01 | CNC routing tube pockets | Action shot: bit in cherry rail, pockets routing | ☐ |
| FRAME-02 | Completed rail — close-up | 13 pockets visible in the rail face; calliper against pocket width | ☐ |
| FRAME-03 | Dry-fit assembly | All 13 Zanka tubes seated in rail pockets — no glue yet | ☐ |
| FRAME-04 | Glue-up with clamps | Rails clamped to tubes; squeeze-out visible at pockets | ☐ |
| FRAME-05 | Finished rail — danish oil | Oiled cherry rail, grain visible, before tube insertion | ☐ |

---

## Group 6 — Binding / Cord Wrap

| Shot ID | Subject | Notes | Status |
|---|---|---|---|
| BIND-01 | Cord wrapping detail | Close-up of waxed cord being wrapped around tube array; needle visible | ☐ |
| BIND-02 | Finished cord lash — knot detail | Close-up of square knot at rail end; wax sheen on cord | ☐ |
| BIND-03 | Arka rank — completed | Full Zanka arka rank (7 tubes, bound, stepped profile) — beauty shot | ☐ |
| BIND-04 | Arka + Ira side by side | Both ranks assembled, displayed together on grey background | ☐ |

---

## Group 7 — Hero and Portfolio Shots

| Shot ID | Subject | Notes | Status |
|---|---|---|---|
| HERO-01 | All 4 family members — full family | Toyo/Zanka/Malta/Chili arranged by size, overhead flat-lay | ☐ |
| HERO-02 | All 4 family members — side view | Standing upright; stepped profiles visible; scale comparison obvious | ☐ |
| HERO-03 | Zanka arka — 3/4 beauty shot | Best-lit shot of the primary instrument; portfolio-grade | ☐ |
| HERO-04 | Close-up of tube ends (blow end) | 13 tube openings arranged in a circle or arc; aperture/bore visible | ☐ |
| HERO-05 | Player shot — arka in playing position | Hands holding arka at playing angle; embouchure demonstrated | ☐ |
| HERO-06 | Duet shot — two ranks in pairs | Two players (or two hand positions) holding arka + ira; interlocking gesture | ☐ |
| HERO-07 | Design table alongside instrument | Laptop showing `siku-zampona-design-table.xlsx` open next to completed Zanka arka | ☐ |

---

## Group 8 — Documentation / Workflow (for capstone deck)

| Shot ID | Subject | Notes | Status |
|---|---|---|---|
| DOC-01 | family-spec.csv open in Excel | Show the 4-row family table with tube lengths visible | ☐ |
| DOC-02 | validation.csv with data filled in | Post-build validation sheet with measured Hz and cents error filled | ☐ |
| DOC-03 | SVG drawing on screen | `drawings/siku-zanka-elevation.svg` open in browser or Illustrator | ☐ |
| DOC-04 | Wolfram notebook running | `wolfram/instrument-model.wl` Manipulate panel open with tube-length sliders | ☐ |

---

## Photography Notes

- Natural light preferred; north-facing window or overcast outdoor is ideal for the grey background shots.
- Avoid flash that washes out the bamboo grain texture.
- For the hero shots (HERO-01 through HERO-07), shoot at f/8 for depth of field; instruments should be in full focus.
- Include `.raw` or `.dng` format files in `images/raw/` if possible; JPEG exports in `images/` for the build-log site.
- All photos must be original — no stock images. See `resources.md` note on cultural sensitivity before captioning player shots.

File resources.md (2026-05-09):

# Siku (Zampoña) — Resources

**Packet:** v4.3 · Date: 2026-05-08

---

## Acoustic and Physics References

- **Fletcher & Rossing — *The Physics of Musical Instruments* (2nd ed., Springer, 1998):** Chapter 16 covers flute-family acoustics; Chapter 8 covers cylindrical-bore stopped pipes. The definitive reference for end-correction derivations and excitation threshold modeling.
- **Nederveen — *Acoustical Aspects of Woodwind Instruments* (1998):** Detailed tone-hole and bore-correction theory. Useful for understanding why the 0.82 × bore_diameter convention differs from the pure physics 0.3 × d value.
- **Benade — *Fundamentals of Musical Acoustics* (Oxford, 1976):** Chapter 22 discusses panpipes. Accessible treatment of stopped-pipe resonance.
- **Acústica de flautas de pan (Spanish, various authors):** Search "acústica zampoña cálculo longitud" for South American papers that present empirical tuning data for traditional cañahueca instruments. These provide useful cross-checks against the formula approach used in this packet.

---

## Ethnomusicological and Cultural Sources

- **Arnaud Gérard — "Acoustic research on pre-Columbian flutes" (various, 2010s):** Documents Nazca and Tiwanaku panpipes with measured bore and length data. Primary archaeological reference for siku instrument history.
- **Ellen Hickmann — *Musik des Altertums in Südamerika* (Laaber Verlag, 1990):** Covers archaeological finds from Peru/Bolivia including panpipes with dating evidence from 1500 BCE.
- **Thomas Turino — *Moving Away from Silence: Music of the Peruvian Altiplano and the Experience of Urban Migration* (University of Chicago Press, 1993):** Essential ethnography of siku playing in Aymara culture; explains yanantin (complementarity) and the interlocking duet tradition in cultural context. Read before writing any provenance copy for public build-log or README.
- **Max Peter Baumann — "Music in the Andean Highlands" (The World of Music, Vol. 21, 1979):** Overview of siku traditions, instrument families, and ensemble formats across Aymara/Quechua communities.
- **Wikipedia — Siku (instrument):** https://en.wikipedia.org/wiki/Siku — reasonable entry point; check primary references in footnotes before citing.

---

## Bamboo and Materials References

- **Londoño, X. et al. — Guadua chacoensis monograph (FAO, 2002):** Species description, distribution, and physical properties of cañahueca bamboo — the traditional siku tube material.
- **Janssen, J.J.A. — *Bamboo in Building Structures* (Eindhoven, 1981):** Wall thickness, culm taper, node spacing data across bamboo species. Useful for calculating bore variance expectations.
- **Archery supply catalogs (Easton, Gold Tip):** Arrow shaft diameter tables cover bamboo and carbon tubes in the 3/8"–5/8" OD range; a practical cross-reference for Malta and Chili size sourcing.

---

## Maker and Build References

- **tonykoop/transverse-flute** — https://github.com/tonykoop/transverse-flute — stopped-pipe family baseline; slip-cast bore workflow; reference for family-aware drawings.
- **tonykoop/gemshorn** — https://github.com/tonykoop/gemshorn — vessel-flute family; demonstrates `family-spec.csv` format and multi-member packet structure.
- **tonykoop/instrument-maker** — https://github.com/tonykoop/instrument-maker — parent skill and catalog.
- **panflutejedi.com:** English-language panflute-maker community with build logs and empirical bore correction data. Particularly useful thread: "Pan flute tube length calculations — what end correction factor actually works?"
- **Quena-Makers Forum (Spanish):** Similar community for South American flute makers. Empirical bore correction discussions often reference cañahueca bamboo specifically.

---

## CAD / CNC Tools

- **SolidWorks + design table workflow:** `references/solidworks-integration.md` (instrument-maker-v4 skill). Applicable for generating parametric siku tube array models.
- **OpenSCAD siku starter:** `cad/siku-openscad-starter.scad` (TBD — see `drawing-brief.md` for specifications). OpenSCAD is appropriate for a fully parametric tube-array model where root_midi, bore_id, and member_id drive all dimensions.
- **Wolfram siku model:** `wolfram/instrument-model.wl` — interactive tube length explorer, arka/ira split visualization, odd-harmonic spectrum.

---

## Provenance and Cultural Sensitivity Notes

The siku is a living cultural artifact, not simply a historical instrument. The Aymara and Quechua peoples of Bolivia and Peru continue to build and play siku in community contexts today. When documenting, publishing, or displaying this build:

1. **Attribute the tradition accurately.** Describe the instrument as "Andean Aymara/Quechua in origin" rather than generically "South American" or "Incan."
2. **Use the Aymara name *siku* (or *siku'*) as primary, with *zampoña* (Spanish) as a secondary common name.** The Aymara name is more specific and preferred in ethnomusicological writing.
3. **Do not claim cultural authenticity.** A CNC-built PVC or cherry siku is a contemporary workshop interpretation. State this clearly in the README and any public-facing documentation.
4. **Acknowledge yanantin.** The split arka/ira design is not arbitrary — it embodies a cultural philosophy of paired complementarity. Any write-up that explains the instrument without explaining yanantin is missing the point.
5. **Do not sell as "traditional" or "authentic."** The CC BY 4.0 license covers the engineering documentation, not a claim of cultural ownership.

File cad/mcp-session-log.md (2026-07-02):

# CAD / MCP Session Log — siku-zampona

No external MCP or creative-tool sessions have produced artifacts in this packet as of 2026-05-29.
All SVGs in `drawings/` were generated from the design-table by prior sprint agents without an
interactive OpenSCAD MCP, Blender MCP, Illustrator MCP, or image-gen session.

When an OpenSCAD MCP, Blender MCP, or image-gen session produces or modifies a repo artifact,
add a row to the table below before committing that artifact.

| session_id | tool | input_authority | outputs | role | authority_result | review_status | notes |
|---|---|---|---|---|---|---|---|
| fable-v5-refresh-2026-07-01 | claude-code (Fable 5) | siku-zampona-design-table.xlsx, family-spec.csv | family-spec.csv, bom.csv, sourcing.csv, cut-list.csv, validation.csv | packet_refresh | fabrication | self_checked | V5 refresh pass; tabular packet data reviewed against design table; no dimension changes made. Provenance rows added to satisfy V5 fabrication-artifact logging. |
| fable-v5-refresh-2026-07-01 | claude-code (Fable 5) + OpenSCAD CLI | family-spec.csv, design.md §2, siku-zampona-design-table.xlsx | cad/siku-zampona.scad | cad_authoring | pending_measurement | self_checked | New parametric master: two-rank (arka 7 + ira 6) closed-pipe tube-length envelope, equation-driven (L = c/(4f) - 0.82*bore_ID per design.md §2.1). Tube lengths and combined 13-tube frame width cross-checked at render time against family-spec.csv for all 4 variants (Toyo/Zanka/Malta/Chili) — exact match. Voicing/mouth-edge geometry and frame-rail pockets out of scope. OpenSCAD render check: pass (openscad -o STL, exit 0). |

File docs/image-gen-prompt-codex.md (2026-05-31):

# Image Generation Prompt

Concept image only; not fabrication authority. Do not include cut-ready dimensions, hole locations, or toolpaths.

## Hero Prompt

Photorealistic 3/4 studio product photograph of a contemporary workshop interpretation of the Andean Aymara/Quechua siku or zampona family, focused on the Zanka tenor build target: two complementary arka and ira ranks of bamboo tubes with closed lower ends, longest tubes at the left and shortest at the right, bound with waxed cord into clean cherry or walnut frame rails. Show the stepped tube profile, natural bamboo color, careful beeswax sealing at the bottoms, respectful simple finish, clean neutral background, soft directional studio lighting, high detail, 50mm lens look.

## In-Context Prompt

Photorealistic scene of two players holding complementary arka and ira siku ranks in a warm workshop or small rehearsal space, the instruments clearly separate but visually paired, with natural light, spare wooden benches, tuning notebook, and extra bamboo stock nearby. The image should communicate interlocking duet use and contemporary workshop respect without theatrical costume or cultural caricature.

## Detail / Macro Prompt

Macro photorealistic close-up of the siku construction: bamboo tube mouths aligned flush at the blow end, waxed cord binding over a cherry or walnut rail, a stepped row of closed tubes descending in length, and subtle beeswax plugs visible at the lower ends of adjacent tubes. Use shallow depth of field, natural bamboo fiber texture, and no printed note labels.

## Negative / Avoid

No text, no watermarks, no brand logos, no extra limbs, anatomically plausible hands if shown, no cultural costume stereotypes, no random tube counts, no dimensions, no tuning chart, no toolpaths.

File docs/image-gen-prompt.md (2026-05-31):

# Image-Gen Prompts

Concept image only; not fabrication authority. Do not include cut-ready dimensions, hole locations, or toolpaths.

## Hero Prompt

A single completed Andean siku (zampoña) panpipe — the Zanka tenor rank — photographed as a real physical object on a clean neutral light-grey studio sweep. The instrument is a flat raft of thirteen vertical cylindrical tubes bound side by side, descending in a stepped staircase from the longest tube at the left to the shortest at the right; all tube tops are flush along a single straight blow-edge while the lower closed ends fall away in a smooth diagonal step profile, the silhouette that makes a siku instantly recognizable. The tubes read as warm honey-toned bamboo cane with faint natural nodes and a soft satin tung-oil sheen, roughly thumb-width in diameter. They are sandwiched between two slender hardwood frame rails of oiled cherry running horizontally across the array, and lashed with bands of waxed linen cord wrapped in neat parallel turns near each rail. Realistic hand-held scale — the raft is about as wide as two spread hands. Soft directional studio light from upper left, gentle falloff, 3/4 product-photography angle, ~50mm lens, shallow but controlled depth of field, high detail, photorealistic, no text labels.

## In-Context Prompt

The same Zanka siku resting on a workshop bench beside a coil of waxed linen cord, a small block of beeswax, and a digital caliper, lit by soft north-facing window light. Honey bamboo tubes and oiled cherry rails catch a warm daylight glow; pale wood shavings and a story stick lie blurred in the background. Environmental maker-bench storytelling, natural light, shallow depth of field, the stepped tube array in crisp focus. Concept visualization only.

## Detail Prompt

Macro close-up raking across the blow-edge of the siku: the top openings of several bamboo tubes seen in a row, each a clean dark circular bore mouth rimmed by the pale cane wall, flush along one straight edge. Hard low side-light skims the surface to reveal cane grain, the faint ring of a natural node, the satin oil finish, and the tightly wrapped waxed-cord lashing binding the tubes to the cherry rail just below. Extreme texture and depth, high detail, no measurements.

## Negative / Avoid

No text, logos, watermarks, or fake maker marks; no dimension lines or measurement callouts; no curved/conical/recorder-style bodies or finger holes (siku tubes are straight cylinders with no side holes); no impossible mechanisms; anatomically plausible hands if a player is shown.

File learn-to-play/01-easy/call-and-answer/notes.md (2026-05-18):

# Call and Answer

**Tradition/source:** Original beginner exercise
**Public domain:** Yes - pre-1929 US or original MIT
**Arrangement:** Starter L2 arrangement for `siku-zampona`.

## Range check
G4-D5: within the beginner starter range for this packet.

## Practice tip
One player can take the first bar and the second player answers the next bar.

## Known gaps
Audio, MusicXML, LilyPond, and printable songsheet stages are intentionally skipped until the shared render toolchain is installed. Fingering SVGs are static L2 review artifacts and should be checked against the final drilled hole layout before public release.

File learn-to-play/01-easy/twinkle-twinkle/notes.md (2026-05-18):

# Twinkle Twinkle Little Star

**Tradition/source:** Mozart K.265 theme (1781)
**Public domain:** Yes - pre-1929 US or original MIT
**Arrangement:** Starter L2 arrangement for `siku-zampona`.

## Range check
G4-E5: within the beginner starter range for this packet.

## Practice tip
A steady hocket works better than trying to imitate a single flute line.

## Known gaps
Audio, MusicXML, LilyPond, and printable songsheet stages are intentionally skipped until the shared render toolchain is installed. Fingering SVGs are static L2 review artifacts and should be checked against the final drilled hole layout before public release.

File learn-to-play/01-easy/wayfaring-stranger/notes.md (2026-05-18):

# Wayfaring Stranger

**Tradition/source:** American folk hymn, public domain
**Public domain:** Yes - pre-1929 US or original MIT
**Arrangement:** Starter L2 arrangement for `siku-zampona`.

## Range check
G4-D5: within the beginner starter range for this packet.

## Practice tip
Let each pipe speak fully before the next player enters.

## Known gaps
Audio, MusicXML, LilyPond, and printable songsheet stages are intentionally skipped until the shared render toolchain is installed. Fingering SVGs are static L2 review artifacts and should be checked against the final drilled hole layout before public release.

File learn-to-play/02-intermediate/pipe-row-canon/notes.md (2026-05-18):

# Pipe Row Canon

**Tradition/source:** Original paired-player study
**Public domain:** Yes - pre-1929 US or original MIT
**Arrangement:** Starter L2 arrangement for `siku-zampona`.

## Range check
G4-A5: within the beginner starter range for this packet.

## Practice tip
Player two enters one bar later; solo players can read it as a straight melody.

## Known gaps
Audio, MusicXML, LilyPond, and printable songsheet stages are intentionally skipped until the shared render toolchain is installed. Fingering SVGs are static L2 review artifacts and should be checked against the final drilled hole layout before public release.

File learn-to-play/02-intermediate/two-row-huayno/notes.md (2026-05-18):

# Two-Row Huayno

**Tradition/source:** Original Andean-style hocket study
**Public domain:** Yes - pre-1929 US or original MIT
**Arrangement:** Starter L2 arrangement for `siku-zampona`.

## Range check
G4-G5: within the beginner starter range for this packet.

## Practice tip
Keep the row change relaxed; a late clean note is better than an early cracked one.

## Known gaps
Audio, MusicXML, LilyPond, and printable songsheet stages are intentionally skipped until the shared render toolchain is installed. Fingering SVGs are static L2 review artifacts and should be checked against the final drilled hole layout before public release.

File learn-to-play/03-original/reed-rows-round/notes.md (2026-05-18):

# Reed Rows Round

**Tradition/source:** Tony Koop / Heifer Zephyr (2026)
**Public domain:** Yes - pre-1929 US or original MIT
**Arrangement:** Starter L2 arrangement for `siku-zampona`.

## Range check
G4-G5: within the beginner starter range for this packet.

## Practice tip
Play in two-bar loops first, then chain the loops into the full round.

## Known gaps
Audio, MusicXML, LilyPond, and printable songsheet stages are intentionally skipped until the shared render toolchain is installed. Fingering SVGs are static L2 review artifacts and should be checked against the final drilled hole layout before public release.

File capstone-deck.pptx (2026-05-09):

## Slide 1

HEIFER ZEPHYR

Siku (Zampoña)

Andean Panpipe — Four-Member Family

instrument-maker-v4 · packet v4.3 · 2026-05-08

HEIFER ZEPHYR

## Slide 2

Project Intent

The siku is the Andean panpipe — one of the oldest continuously played instruments in the world, with archaeological specimens from Tiwanaku and Nazca dated to at least 1500 BCE.

The Instrument

Played in interlocking arka/ira pairs. Neither rank alone contains the full scale — two players weave a melody together, embodying yanantin: the Aymara philosophy of complementary pairing.

This Build

A four-member family (Toyo/Zanka/Malta/Chili) using parametric acoustic design, CNC-routed cherry frame rails, and bamboo or PVC tubes. Primary target: Zanka (key of C, tenor voice).

Goal: A fully-documented, reproducible build packet for the complete siku family, publishable as a GitHub portfolio instrument and buildable from this packet alone.

HEIFER ZEPHYR

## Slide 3

Yanantin

The Aymara Philosophy of Complementary Pairing

ARKA ♀ Leader

7 tubes · semitones 0 4 7 10 14 17 21

Carries the lead phrase

IRA ♂ Follower

6 tubes · semitones 2 5 9 12 16 19

Answers the lead phrase

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
Neither rank alone contains the full scale. Together: G Mixolydian.

HEIFER ZEPHYR

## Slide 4

Instrument Family

Toyo

Bass · G3

bore 0.750"

OD 1.000"

longest 22.6"

frame 13.75"

HEIFER ZEPHYR

PRIMARY BUILD

Zanka

Tenor · C4

bore 0.625"

OD 0.821"

longest 16.96"

frame 11.42"

Malta

Alto · G4

bore 0.500"

OD 0.658"

longest 11.3"

frame 9.30"

Chili

Soprano · A4

bore 0.375"

OD 0.493"

longest 7.6"

frame 7.16"

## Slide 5

Acoustic Design

L_calc = 13552 / (4 × f_hz) − 0.82 × bore_ID

L_cut = L_calc + 3/16" (tuning trim allowance)

Parameter | Value | Notes
Speed of sound | 13,552 in/s | At 68°F shop standard
End correction | 0.82 × bore_ID | Empirical — bundles embouchure effects
Pipe type | Stopped cylindrical | Odd harmonics only: 1f, 3f, 5f…
Tuning | A4 = 440 Hz | Equal temperament
Trim allowance | 3/16" (0.1875") | All L_cut values include this margin

Sanity check — Zanka A4: L_calc(440 Hz, bore=0.625") = 13552/(4×440) − 0.82×0.625 = 7.188" ✓

HEIFER ZEPHYR

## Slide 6

Zanka Tube Layout — G3 to E5

G3

A1

Arka (7 tubes, leader ♀)

A3

I1

Ira (6 tubes, follower ♂)

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
HEIFER ZEPHYR

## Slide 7

Tube Cross-Sections — All Four Members

Toyo

G3 Bass

Zanka

C4 Tenor

Malta

G4 Alto

Chili

A4 Soprano

bore 0.625"

bore 0.5"

bore 0.375"

OD 0.493" wall 0.059"

bore 0.75"

OD 1" wall 0.125"

OD 0.821" wall 0.098"

OD 0.658" wall 0.079"

End correction (open end only): ΔL = 0.82 × bore_ID | Stopped pipe: odd harmonics only (1f, 3f, 5f…)

HEIFER ZEPHYR

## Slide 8

Frame Rail & Binding

TOP RAIL

Parameter | Value
Material | Cherry or walnut S4S 3/4" × 1.5"
Pocket width | OD − 0.005" (light interference fit)
Pocket depth | OD / 3
Pocket pitch | OD + 1/16" center-to-center
Binding cord | Waxed linen or nylon, 1 mm
Wraps per tube | 3 minimum; square-knot at ends
Glue | Thin film in pockets (optional)

No hardware — only wood, bamboo/PVC, beeswax, and cord.

BOTTOM RAIL

HEIFER ZEPHYR

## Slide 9

Build Sequence — 8 Phases

Stock Verification

Measure bore ID + OD of all incoming stock; record in validation.csv

1

Tube Cutting

Story stick (bamboo) or digital stop (PVC); 52 tubes; label immediately

2

Closed-End Sealing

Beeswax pour in plywood fixture; 3/8" depth; 30 min cure

3

First Tuning Pass

Measure all tubes; record cents deviation in validation.csv

4

Frame Rail Fabrication

CNC-route 13 pockets; pocket width = OD − 0.005"; dry-fit before glue

5

Assembly & Binding

Seat tubes; waxed cord wrap; 3+ passes per tube; square-knot finish

6

Trim-Tuning

File/saw open ends to ±5 cents; update validation.csv same session

7

Finishing

Danish oil on rails; tung oil wipe on bamboo; photograph

8

HEIFER ZEPHYR

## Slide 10

Manufacturing Notes

Tube Boring Method by Member

Member | Method | Max Tube Length | Key Constraint
Toyo | Headstock-driven deep bore | 22.6" | Prevents drill wander at depth
Zanka | Lathe tailstock drill | 17.0" | 4-jaw chuck; steady rest >12"
Malta | Drill press + V-block | 11.3" | Forstner or brad-point bit
Chili | Drill press + V-block | 7.6" | Single clamp sufficient

Jig Build Priority

Priority | Jig | When Needed
P1 | Story stick × 4 (one per member) | Before any cutting
P1 | Sealing stand × 4 (one per member) | Before Phase 3 sealing
P2 | CNC pocket toolpath | Before Phase 5 frame fabrication
P3 | Tailstock carrier for deep bore (Toyo only) | Before boring hardwood Toyo blanks

HEIFER ZEPHYR

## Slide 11

Materials Summary

Member | Tubes | Frame Rails | Plugs | Cord | Est. Total
Toyo (Bass) | $6.50 | $12.00 | $1.30 | $0.25 | ~$20
Zanka (Tenor) | $5.20 | $10.00 | $1.04 | $0.20 | ~$17
Malta (Alto) | $4.55 | $8.00 | $0.78 | $0.15 | ~$14
Chili (Soprano) | $3.90 | $7.00 | $0.65 | $0.10 | ~$12

Shared Tools (once)

Chromatic tuner: $15

Beeswax block: $3

Abrasive paper: $2

Danish oil: $8

Total shared: ~$28

Single Zanka Build

~$17 materials + $28 shared tools

= ~$45 for first build

Full four-member family: ~$91
(excludes finish and consumables)

HEIFER ZEPHYR

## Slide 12

Key Risks

H

AC-04

Chili Arka-7 (F#6, 1.982") borderline playable

Build as 11-tube Chili; omit top 2 tubes

M

AC-01

Bamboo bore variance (±0.015" typical)

Measure all tubes before cutting; adjust L_calc per measured bore

M

AC-02

Temperature drift (±10°F → ±0.9% pitch)

Tune and play at same temperature; note shop temp in validation.csv

M

ST-01

Rail pocket undersize causing tube cracking

First pocket is always a test pocket; verify fit before batch routing

H

ER-01

See resources.md §Provenance; required before any public publish

Yanantin not explained in public documentation

HEIFER ZEPHYR

Full risk register: 11 risks in risks.md

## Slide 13

Packet Contents

Design doc, tube length tables, arka/ira split

design.md

4 members, 13 tubes each, all parameters

family-spec.csv

Full bill of materials (29 rows)

bom.csv

52 tube cuts + 4 rail cuts

cut-list.csv

Per-tube targets: Hz, cents tolerance

validation.csv

8-phase build manual with tool list

assembly-manual.md

11 structured risks with verification tests

risks.md

Machine datums, tooling, release checks

cnc/setup-sheet.md

Interactive tube-length explorer

wolfram/instrument-model.wl

Dimensioned drawings: elevation, cross-section, details

drawings/ (10 SVGs)

Build-log site with live tube visualiser

site/index.html

5-page printable shop reference

print-packet.pdf

HEIFER ZEPHYR

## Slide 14

Open Items

Photos: all 36 shots in photo-shotlist.md pending actual build. HERO-03 (Zanka arka beauty shot) is the README hero image.

OI-01 · H

Chili Arka-7 prototype: build and test the 1.982" F#6 tube before committing full Chili production (resolves risk AC-04).

OI-02 · M

Wolfram audio recordings: capture AudioGenerator output for arka + ira ranks; embed in build-log site.

OI-03 · M

OpenSCAD model: cad/siku-openscad-starter.scad is TBD per drawing-brief.md.

OI-04 · L

Sourcing confirmation: verify current bamboo cañahueca availability; lead time 2–4 weeks for import suppliers.

OI-05 · L

Validation.csv: fill in measured_hz column after first Zanka prototype build and confirm ±5 cent tolerance.

OI-06 · L

HEIFER ZEPHYR

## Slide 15

Cultural Provenance

Attribute accurately

Describe as "Andean Aymara/Quechua in origin" — not "Incan" or "South American"

Don't claim authenticity

This is a contemporary workshop interpretation — state this clearly in README and public docs

Explain yanantin

The interlocking duet is not decorative; it embodies a cultural philosophy of complementary pairing

Don't sell as traditional

The CC BY 4.0 license covers the engineering documentation, not the cultural tradition

Primary reference

Thomas Turino — Moving Away from Silence (Chicago, 1993)

tonykoop/siku-zampona · CC BY 4.0 · Heifer Zephyr · packet v4.3

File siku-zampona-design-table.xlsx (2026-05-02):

Siku (Zampoña) — Pan Flute CNC Design Table
Arka (7 tubes, female) + Ira (6 tubes, male) · Splittable for Duet
Root Note (lowest) |  | D 3 | Eb 3 | E 3 | F 3 | Gb 3 | G 3 | Ab 3 | A 3 | Bb 3 | B 3 | C 4 | Db 4 | D 4 | Eb 4 | E 4 | F 4 | Gb 4 | G 4 | Ab 4 | A 4
Piano Key |  | 30 | 31 | 32 | 33 | 34 | 35 | 36 | 37 | 38 | 39 | 40 | 41 | 42 | 43 | 44 | 45 | 46 | 47 | 48 | 49
Siku Key Name |  | G3 | Ab3 | A3 | Bb3 | B3 | C4 | Db4 | D4 | Eb4 | E4 | F4 | Gb4 | G4 | Ab4 | A4 | Bb4 | B4 | C5 | Db5 | D5
Size Class |  | Toyo (bass) | Toyo (bass) | Toyo (bass) | Toyo (bass) | Zanka (tenor) | Zanka (tenor) | Zanka (tenor) | Zanka (tenor) | Zanka (tenor) | Zanka (tenor) | Zanka (tenor) | Malta (alto) | Malta (alto) | Malta (alto) | Malta (alto) | Malta (alto) | Malta (alto) | Malta (alto) | Chili (soprano) | Chili (soprano)
Bore ID (in) |  | 0.750 | 0.750 | 0.750 | 0.750 | 0.625 | 0.625 | 0.625 | 0.625 | 0.625 | 0.625 | 0.625 | 0.500 | 0.500 | 0.500 | 0.500 | 0.500 | 0.500 | 0.500 | 0.375 | 0.375
Wall Thickness |  | 0.125 | 0.125 | 0.125 | 0.125 | 0.098 | 0.098 | 0.098 | 0.098 | 0.098 | 0.098 | 0.098 | 0.079 | 0.079 | 0.079 | 0.079 | 0.079 | 0.079 | 0.079 | 0.059 | 0.059
Outer Diameter
ARKA ROW — 7 Tubes (♀ Female)
Arka 1 | Note | D 3 | D# 3 | E 3 | F 3 | F# 3 | G 3 | G# 3 | A 3 | A# 3 | B 3 | C 4 | C# 4 | D 4 | D# 4 | E 4 | F 4 | F# 4 | G 4 | G# 4 | A 4
 | Tube Length (in)
Arka 2 | Note | F# 3 | G 3 | G# 3 | A 3 | A# 3 | B 3 | C 4 | C# 4 | D 4 | D# 4 | E 4 | F 4 | F# 4 | G 4 | G# 4 | A 4 | A# 4 | B 4 | C 5 | C# 5
 | Tube Length (in)
Arka 3 | Note | A 3 | A# 3 | B 3 | C 4 | C# 4 | D 4 | D# 4 | E 4 | F 4 | F# 4 | G 4 | G# 4 | A 4 | A# 4 | B 4 | C 5 | C# 5 | D 5 | D# 5 | E 5
 | Tube Length (in)
Arka 4 | Note | C 4 | C# 4 | D 4 | D# 4 | E 4 | F 4 | F# 4 | G 4 | G# 4 | A 4 | A# 4 | B 4 | C 5 | C# 5 | D 5 | D# 5 | E 5 | F 5 | F# 5 | G 5
 | Tube Length (in)
Arka 5 | Note | E 4 | F 4 | F# 4 | G 4 | G# 4 | A 4 | A# 4 | B 4 | C 5 | C# 5 | D 5 | D# 5 | E 5 | F 5 | F# 5 | G 5 | G# 5 | A 5 | A# 5 | B 5
 | Tube Length (in)
Arka 6 | Note | G 4 | G# 4 | A 4 | A# 4 | B 4 | C 5 | C# 5 | D 5 | D# 5 | E 5 | F 5 | F# 5 | G 5 | G# 5 | A 5 | A# 5 | B 5 | C 6 | C# 6 | D 6
 | Tube Length (in)
Arka 7 | Note | B 4 | C 5 | C# 5 | D 5 | D# 5 | E 5 | F 5 | F# 5 | G 5 | G# 5 | A 5 | A# 5 | B 5 | C 6 | C# 6 | D 6 | D# 6 | E 6 | F 6 | F# 6
 | Tube Length (in)
IRA ROW — 6 Tubes (♂ Male)
Ira 1 | Note | E 3 | F 3 | F# 3 | G 3 | G# 3 | A 3 | A# 3 | B 3 | C 4 | C# 4 | D 4 | D# 4 | E 4 | F 4 | F# 4 | G 4 | G# 4 | A 4 | A# 4 | B 4
 | Tube Length (in)
Ira 2 | Note | G 3 | G# 3 | A 3 | A# 3 | B 3 | C 4 | C# 4 | D 4 | D# 4 | E 4 | F 4 | F# 4 | G 4 | G# 4 | A 4 | A# 4 | B 4 | C 5 | C# 5 | D 5
 | Tube Length (in)
Ira 3 | Note | B 3 | C 4 | C# 4 | D 4 | D# 4 | E 4 | F 4 | F# 4 | G 4 | G# 4 | A 4 | A# 4 | B 4 | C 5 | C# 5 | D 5 | D# 5 | E 5 | F 5 | F# 5
 | Tube Length (in)
Ira 4 | Note | D 4 | D# 4 | E 4 | F 4 | F# 4 | G 4 | G# 4 | A 4 | A# 4 | B 4 | C 5 | C# 5 | D 5 | D# 5 | E 5 | F 5 | F# 5 | G 5 | G# 5 | A 5
 | Tube Length (in)
Ira 5 | Note | F# 4 | G 4 | G# 4 | A 4 | A# 4 | B 4 | C 5 | C# 5 | D 5 | D# 5 | E 5 | F 5 | F# 5 | G 5 | G# 5 | A 5 | A# 5 | B 5 | C 6 | C# 6
 | Tube Length (in)
Ira 6 | Note | A 4 | A# 4 | B 4 | C 5 | C# 5 | D 5 | D# 5 | E 5 | F 5 | F# 5 | G 5 | G# 5 | A 5 | A# 5 | B 5 | C 6 | C# 6 | D 6 | D# 6 | E 6
 | Tube Length (in)
CNC ASSEMBLY SPECS
Longest Tube (in)
Shortest Tube (in)
Tube Spacing
Total Frame Width
Duet Split? |  | Arka ♀ + Ira ♂ | Arka ♀ + Ira ♂ | Arka ♀ + Ira ♂ | Arka ♀ + Ira ♂ | Arka ♀ + Ira ♂ | Arka ♀ + Ira ♂ | Arka ♀ + Ira ♂ | Arka ♀ + Ira ♂ | Arka ♀ + Ira ♂ | Arka ♀ + Ira ♂ | Arka ♀ + Ira ♂ | Arka ♀ + Ira ♂ | Arka ♀ + Ira ♂ | Arka ♀ + Ira ♂ | Arka ♀ + Ira ♂ | Arka ♀ + Ira ♂ | Arka ♀ + Ira ♂ | Arka ♀ + Ira ♂ | Arka ♀ + Ira ♂ | Arka ♀ + Ira ♂
WOLFRAM CLOUD NOTEBOOK SPEC — SIKU / ZAMPOÑA
Andean panpipes — 13 closed-tube pipes split into 2 ranks (arka 7 + ira 6), played by 2 players or one alternating.
§1 — Origin & Etymology
Origin: pre-Columbian Andes (Aymara, Quechua, Tiwanaku culture). Ancient examples 1500+ BCE.
Siku' Aymara, 'Zampoña' Spanish. Two interlocking ranks force two musicians to play in dialogue (paired playing) — central to Aymara musical philosophy of complementarity (yanantin).
Wolfram items: GeoGraphics Aymara region; TimelinePlot[{−1500, Tiwanaku, Inca, present}].
§2 — Physics
Closed-pipe (closed at bottom): f = c/(4 L_eff). Each pipe = single note.
End correction: ΔL ≈ 0.82·bore (closed pipe end correction at the open end only).
13 pipes split: arka (leader) has 7 pipes (notes 0,4,7,10,14,17,21 semitones from root); ira (follower) has 6 pipes (2,5,9,12,16,19) — interleave gives complete diatonic.
Wolfram functions: NDSolve closed-pipe array; Periodogram on recorded interlocking duet.
§3 — Geometry & Materials
Pipes: bamboo cane, sealed at one end with natural node or wax plug. Tied in a row with cord.
Length per pipe: L = c/(4 f) − 0.82·bore. Use sheet's design table for actual lengths.
Wolfram items: Manipulate root key + bore → recompute all 13 pipe lengths; ParametricPlot3D pipe array.
§4 — Animations
Standing-wave Animate per pipe: pressure anti-node at top, node at bottom (closed end). Show odd-harmonic-only spectrum.
Two-rank duet visualization: highlight which player blows which pipe in turn — animate over a melody.
§5 — Executable Cells
lSiku[f_,bore_]:=343/(4 f) - 0.82 bore
arkaSemis = {0,4,7,10,14,17,21}
iraSemis = {2,5,9,12,16,19}
tuneAll[rootFreq_, semis_]:= rootFreq 2^(semis/12)
§6 — Wolfram Functions
Manipulate, NDSolve, Periodogram, GeoGraphics, TimelinePlot, CloudDeploy, FormFunction, APIFunction, Export.
WOLFRAM EXPLORATIONS — SIKU / ZAMPOÑA
Curated from the wolfram-notebooks-roadmap brainstorm — pick a row, file an issue, build the notebook.
Roadmap-inspired notebook ideas tailored to this sheet:
• Arka+Ira Interlocking Synth — Two-player hocketing pattern; AudioGenerator simulating 2 players splitting the diatonic across pipes.
• Closed-Pipe Length Optimizer — L = c/(4f) − 0.82·d; sweep bore Ø to find sweet-spot for breath response across the 13 pipes.
• Cultural Atlas: Pan-Andean Siku Traditions — GeoGraphics Bolivia/Peru altiplano; TimelinePlot from pre-Columbian to modern conjunto.
• Cane Selection (Cañahueca) — Density vs internal-node spacing; predict yield from a given cane harvest.

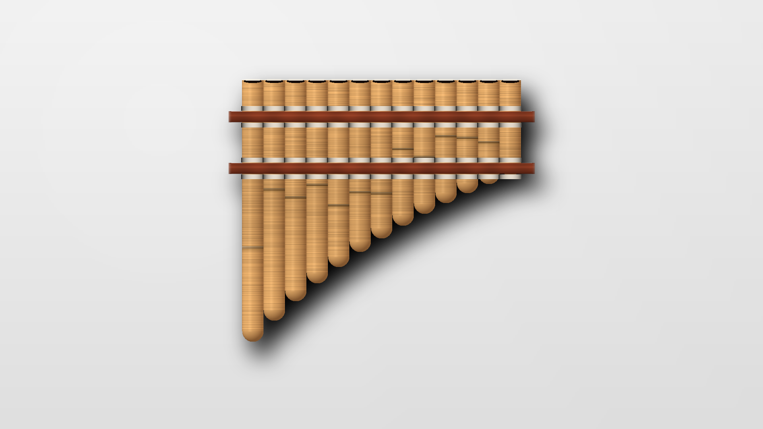
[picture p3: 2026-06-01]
images/hero-render.png

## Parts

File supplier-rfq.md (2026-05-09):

# Siku (Zampoña) — Supplier RFQ

**Project:** Siku/Zampoña Panpipe Family (Toyo · Zanka · Malta · Chili)  
**Date:** 2026-05-08  
**Contact:** Tony Koop · tonykoop@gmail.com  
**Quantity context:** Prototype build (1 of each size class = 4 instruments, 52 tubes total)

---

## RFQ A — Bamboo Cane Tube Stock

**To:** [Bamboo specialty supplier — Bamboo Craftsman / Tropical Bamboo / local Andean instrument supplier]

Subject: Bamboo Cane Tube Stock — Siku/Zampoña Panpipe Build

Hello,

I am building a prototype set of Andean siku (zampoña) panpipes in four sizes. I need bamboo cane (cañahueca or similar dense Andean bamboo species) in the following bore/OD specifications. Please quote unit price per foot, minimum order, current lead time, and whether the bore diameters can be confirmed to specification.

**Required specifications:**

| Size | Bore ID (in) | Approx OD (in) | Wall (in) | Quantity (ft) | Notes |
|---|---|---|---|---|---|
| Toyo (bass) | 0.750 ± 0.030 | ~1.000 | ~0.125 | 25 ft | Must include sections with no nodes for 23" clear spans |
| Zanka (tenor) | 0.625 ± 0.025 | ~0.821 | ~0.098 | 20 ft | Consistent bore critical |
| Malta (alto) | 0.500 ± 0.020 | ~0.658 | ~0.079 | 15 ft | |
| Chili (soprano) | 0.375 ± 0.015 | ~0.493 | ~0.059 | 10 ft | Thin-wall — confirm structural integrity |

**Additional questions:**
1. Can you confirm the bamboo species and country of origin?
2. Are the cane sections kiln-dried or air-dried? Moisture content at shipping?
3. Do you offer sections with a natural node at a selectable position (for use as closed-end plugs)?
4. What is your typical bore-diameter variance over a 10-foot section?

Substitutions are acceptable if the bore and wall dimensions match within the stated tolerances. Please provide a data sheet or sample photo if available.

Thank you,  
Tony Koop

---

## RFQ B — PVC Pipe (Prototyping Alternative)

**To:** Local plumbing supply / Home Depot / Lowes

No formal RFQ needed — confirm in-store stock of:

| Nominal Size | Schedule | Actual ID (verify with caliper) | Use for |
|---|---|---|---|
| 1" nominal | Sch 40 | ~0.824" (measure — may suit Toyo if close to 0.750") | Toyo prototype |
| 3/4" nominal | Sch 40 | ~0.622" (near-match for Zanka 0.625") | Zanka prototype |
| 1/2" nominal | Sch 40 | ~0.622" (oversized for Malta 0.500" — note difference) | Malta prototype (recalculate lengths) |
| 3/8" nominal | Sch 40 or thin-wall | ~0.493" OD variants available | Chili prototype |

> **Note:** If PVC bore deviates from bamboo design bore, recalculate all tube lengths using the actual measured bore ID in the formula: `L = 13552 / (4 × f) − 0.82 × actual_bore_ID`.

---

## RFQ C — Cherry/Walnut Frame Rail Stock

**To:** Woodcraft / Rockler / local hardwood dealer

Subject: Hardwood S4S Dimensional Stock for Instrument Frame Rails

Hello,

I need the following hardwood stock for CNC-routed frame rails on a musical instrument project. Straight grain, no defects in the rail face.

| Species | Form | Thickness | Width | Length | Qty | Notes |
|---|---|---|---|---|---|---|
| Cherry (preferred) | S4S | 3/4" (will mill to 3/8") | 4" (will rip to 1.5") | 24" | 2 boards | Straight grain; no checks, knots, or wild grain |
| Walnut (alternate) | S4S | 3/4" | 4" | 24" | 2 boards | Same spec |

**Questions:**
1. Do you carry cherry S4S 4/4 × 4" × 24" in stock today?
2. What is the current price per board foot for FAS-grade cherry?
3. Acceptable moisture content range?

---

## RFQ D — Waxed Cord / Binding Supplies

**To:** Tandy Leather / bookbinding supply / Amazon

| Item | Spec | Qty | Use |
|---|---|---|---|
| Waxed linen cord | 1/16" dia, natural or black, 50-ft spool | 1 spool | Tube binding wraps |
| Beeswax block | Food/craft grade, 2 oz minimum | 1 block | Closed-end tube plugs + cord waxing |

No formal RFQ needed — standard craft/leather supply items. Confirm availability and order.

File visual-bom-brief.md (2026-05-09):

# Siku (Zampoña) — Visual BOM Brief

**Purpose:** Art direction for a visual bill-of-materials plate suitable for the capstone deck, print packet, and build-log site.  
**Reference style:** Tony's Ashiko BOM (`ashiko-drum-workshop/images/figure-bom-v2.png`)

---

## Layout Spec

**Page size:** 11 × 8.5" landscape (letter, for print packet), or 1920 × 1080 px (for deck/site)  
**Header:**
- Assembly name: "Siku (Zampoña) — Zanka Tenor, Key C4"  
- Quote date: 2026-05-08  
- Estimated cost: ~$35–55 per instrument (prototype; bamboo material; does not include shop tooling)

**Hero image:** Full-color photograph or rendering of a complete assembled Zanka arka rank showing the stepped tube array, frame rails, and cord lashing. If no photo is available, use a clean SVG elevation (see `drawings/siku-zanka-arka.svg` — substitute placeholder note in brackets).

---

## Table Structure

Columns: **Part No. · Part Name · Description · Qty · Unit · Image · Cost Ea. · Total · Source**

| Part No. | Part Name | Description | Qty | Unit | Image status | Cost ea. | Total |
|---|---|---|---|---|---|---|---|
| SKZ-Z-01 | Arka Tube | Bamboo or PVC, bore 0.625", 7 unique lengths | 7 | pc | _[Supplier photo or bamboo cross-section photo]_ | $0.40 | $2.80 |
| SKZ-Z-02 | Ira Tube | Same bore, 6 unique lengths | 6 | pc | _[Same image as Z-01]_ | $0.40 | $2.40 |
| SKZ-Z-03 | Bottom Plug | Beeswax or 5/8" wood dowel | 13 | pc | _[Photo: beeswax block + dowel]_ | $0.08 | $1.04 |
| SKZ-Z-04 | Frame Rail — Top | Cherry, 3/8" × 1.5" × 12.4", CNC-pocketed | 1 | pc | _[Photo: routed cherry rail, tube pockets visible]_ | TBD | TBD |
| SKZ-Z-05 | Frame Rail — Bottom | Cherry, same dimensions | 1 | pc | _[Same as Z-04]_ | TBD | TBD |
| SKZ-Z-06 | Binding Cord | Waxed linen, 1/16" dia | 1 | set | _[Photo: cord spool]_ | $0.20 | $0.20 |
| SKZ-SHARED-01 | Chromatic Tuner | Korg CA-1 | 1 | pc | _[Product photo]_ | amortized | — |
| SKZ-SHARED-02 | Beeswax Block | 2 oz block | 1 | pc | _[Photo: beeswax block]_ | $3.00 | $3.00 |
| SKZ-SHARED-04 | Danish Oil | Watco, for frame rails | 1 | can | _[Product photo]_ | amortized | — |

**Bottom notes on plate:**
- "Tube lengths per `family-spec.csv` — Zanka bore 0.625 in, stopped-pipe formula c=13552 in/s"
- "Frame rail species: cherry (walnut acceptable). Tube material: bamboo cañahueca (PVC Sch40 acceptable for prototype)"
- "Cost estimate reflects single prototype. Bamboo bulk pricing reduces tube cost significantly at 10+ instruments."

---

## Image sourcing priority

1. **Real photos from this build** — replace all placeholders after shop session
2. **Supplier product photos** — acceptable for hardware items (beeswax, cord, tuner)
3. **Generated placeholder renders** — SVG elevations from `drawings/` folder acceptable for deck use; mark "(CAD render — replace with build photo)"
4. **Never** use unrelated instrument photos or generic "bamboo" stock art without a caption explaining it's illustrative

---

## For Deck Use

The visual BOM slide in the capstone deck should show the hero image and the table. Use a two-column layout: hero image left (60% width), table right (40%). Caption: "Component count: 24 parts per Zanka instrument (13 tubes + 2 rails + 13 plugs + consumables)."

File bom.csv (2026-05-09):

part_id | assembly | part_name | description | qty_per_instrument | unit | material_spec | make_buy | drawing_ref | estimated_cost_each | estimated_cost_total | notes
SKZ-T-01 | SKZ-TOYO Arka | Arka Tube (Toyo) | Bamboo or PVC closed-pipe tube — 7 unique lengths for arka | 7 | pc | Bamboo cañahueca ~1.0-in OD / 0.750-in bore OR PVC Sch40 1-in nominal | Buy (bamboo) or Buy+bore (PVC) | drawings/siku-toyo-elevation.svg | 0.50 | 3.50 | Cut to L_cut lengths from family-spec.csv; seal bottom end
SKZ-T-02 | SKZ-TOYO Ira | Ira Tube (Toyo) | Bamboo or PVC closed-pipe tube — 6 unique lengths for ira | 6 | pc | Same bore spec as T-01 | Buy (bamboo) or Buy+bore (PVC) | drawings/siku-toyo-elevation.svg | 0.50 | 3.00 | Cut to L_cut lengths from family-spec.csv; seal bottom end
SKZ-T-03 | SKZ-TOYO Shared | Bottom Plug (Toyo) | Beeswax pour plug sealing closed end of each tube | 13 | pc | Beeswax — food grade or filtered; pour depth 3/8" | Make | drawings/siku-wax-plug-detail.svg | 0.10 | 1.30 | Melt to 160°F; pour in sealing stand fixture; 30 min cure
SKZ-T-04 | SKZ-TOYO Shared | Frame Rail — Top (Toyo) | Cherry or walnut S4S rail with 13 CNC-routed tube pockets | 1 | pc | Cherry or walnut S4S 3/4" x 1.5" x 15" | Make | drawings/siku-frame-rail-detail.svg | 6.00 | 6.00 | Pocket width = 0.995"; depth = 0.333"; pitch = 1.063" C-C
SKZ-T-05 | SKZ-TOYO Shared | Frame Rail — Bottom (Toyo) | Cherry or walnut S4S rail — bottom binding rail | 1 | pc | Cherry or walnut S4S 3/4" x 1.5" x 15" | Make | drawings/siku-frame-rail-detail.svg | 6.00 | 6.00 | Same spec as top rail; Danish oil finish before tube insertion
SKZ-T-06 | SKZ-TOYO Shared | Binding Cord (Toyo) | Waxed linen or nylon cord for tube array binding | 1 | lot | Waxed linen 1mm or equivalent; ~100 ft per instrument | Buy |  | 0.25 | 0.25 | 3+ wraps per tube; square knot finish at rail ends
SKZ-T-07 | SKZ-TOYO Shared | Wood Glue / Epoxy | Adhesive for rail pocket bonding (optional) | 1 | lot | Titebond II or 5-min epoxy | Buy |  | 0.50 | 0.50 | Thin film in pockets before tube insertion; wipe squeeze-out
SKZ-Z-01 | SKZ-ZANKA Arka | Arka Tube (Zanka) | Bamboo or PVC closed-pipe tube — 7 unique lengths for arka | 7 | pc | Bamboo cañahueca ~0.821-in OD / 0.625-in bore OR PVC 1/2-in nominal Sch40 | Buy (bamboo) or Buy+bore (PVC) | drawings/siku-zanka-elevation.svg | 0.40 | 2.80 | Cut to L_cut lengths from family-spec.csv; seal bottom end
SKZ-Z-02 | SKZ-ZANKA Ira | Ira Tube (Zanka) | Bamboo or PVC closed-pipe tube — 6 unique lengths for ira | 6 | pc | Same bore spec as Z-01 | Buy (bamboo) or Buy+bore (PVC) | drawings/siku-zanka-elevation.svg | 0.40 | 2.40 | Cut to L_cut lengths from family-spec.csv; seal bottom end
SKZ-Z-03 | SKZ-ZANKA Shared | Bottom Plug (Zanka) | Beeswax pour plug sealing closed end of each tube | 13 | pc | Beeswax — pour depth 3/8" | Make | drawings/siku-wax-plug-detail.svg | 0.08 | 1.04 | See assembly-manual.md Phase 3
SKZ-Z-04 | SKZ-ZANKA Shared | Frame Rail — Top (Zanka) | Cherry or walnut S4S rail with 13 CNC-routed tube pockets | 1 | pc | Cherry or walnut S4S 3/4" x 1.5" x 12.5" | Make | drawings/siku-frame-rail-detail.svg | 5.00 | 5.00 | Pocket width = 0.816"; depth = 0.274"; pitch = 0.884" C-C
SKZ-Z-05 | SKZ-ZANKA Shared | Frame Rail — Bottom (Zanka) | Cherry or walnut S4S rail — bottom binding rail | 1 | pc | Cherry or walnut S4S 3/4" x 1.5" x 12.5" | Make | drawings/siku-frame-rail-detail.svg | 5.00 | 5.00 | Same spec as top rail; Danish oil before tube insertion
SKZ-Z-06 | SKZ-ZANKA Shared | Binding Cord (Zanka) | Waxed linen or nylon cord | 1 | lot | Waxed linen 1mm or equivalent; ~80 ft per instrument | Buy |  | 0.20 | 0.20 | 3+ wraps per tube; square knot finish
SKZ-M-01 | SKZ-MALTA Arka | Arka Tube (Malta) | Bamboo or PVC closed-pipe tube — 7 unique lengths for arka | 7 | pc | Bamboo cañahueca ~0.658-in OD / 0.500-in bore OR PVC 3/8-in nominal | Buy (bamboo) or Buy+bore (PVC) | drawings/siku-malta-elevation.svg | 0.35 | 2.45 | Cut to L_cut lengths from family-spec.csv; seal bottom end
SKZ-M-02 | SKZ-MALTA Ira | Ira Tube (Malta) | Bamboo or PVC closed-pipe tube — 6 unique lengths for ira | 6 | pc | Same bore spec as M-01 | Buy (bamboo) or Buy+bore (PVC) | drawings/siku-malta-elevation.svg | 0.35 | 2.10 | Cut to L_cut lengths from family-spec.csv; seal bottom end
SKZ-M-03 | SKZ-MALTA Shared | Bottom Plug (Malta) | Beeswax pour plug sealing closed end of each tube | 13 | pc | Beeswax — pour depth 1/4" | Make | drawings/siku-wax-plug-detail.svg | 0.06 | 0.78 | Plug depth shallower for smaller bore; see assembly-manual.md
SKZ-M-04 | SKZ-MALTA Shared | Frame Rail — Top (Malta) | Cherry or walnut S4S rail with 13 CNC-routed tube pockets | 1 | pc | Cherry or walnut S4S 3/4" x 1.5" x 10.5" | Make | drawings/siku-frame-rail-detail.svg | 4.00 | 4.00 | Pocket width = 0.653"; depth = 0.219"; pitch = 0.721" C-C
SKZ-M-05 | SKZ-MALTA Shared | Frame Rail — Bottom (Malta) | Cherry or walnut S4S rail — bottom binding rail | 1 | pc | Cherry or walnut S4S 3/4" x 1.5" x 10.5" | Make | drawings/siku-frame-rail-detail.svg | 4.00 | 4.00 | Same spec as top rail
SKZ-M-06 | SKZ-MALTA Shared | Binding Cord (Malta) | Waxed linen or nylon cord | 1 | lot | Waxed linen 1mm; ~60 ft per instrument | Buy |  | 0.15 | 0.15
SKZ-C-01 | SKZ-CHILI Arka | Arka Tube (Chili) | Bamboo or PVC closed-pipe tube — 7 unique lengths for arka | 7 | pc | Bamboo cañahueca ~0.493-in OD / 0.375-in bore OR carbon arrow shaft | Buy (bamboo) or Buy+bore (PVC) | drawings/siku-chili-elevation.svg | 0.30 | 2.10 | WARNING: Arka-7 (F#6 = 1.982") is borderline — see risks.md AC-04
SKZ-C-02 | SKZ-CHILI Ira | Ira Tube (Chili) | Bamboo or PVC closed-pipe tube — 6 unique lengths for ira | 6 | pc | Same bore spec as C-01 | Buy (bamboo) or Buy+bore (PVC) | drawings/siku-chili-elevation.svg | 0.30 | 1.80 | Cut to L_cut lengths from family-spec.csv; seal bottom end
SKZ-C-03 | SKZ-CHILI Shared | Bottom Plug (Chili) | Beeswax pour plug — natural bamboo node preferred for Chili size | 13 | pc | Beeswax or natural bamboo node; plug depth 1/4" | Make | drawings/siku-wax-plug-detail.svg | 0.05 | 0.65 | Natural bamboo node preferred for Chili size
SKZ-C-04 | SKZ-CHILI Shared | Frame Rail — Top (Chili) | Cherry or walnut S4S rail with 13 CNC-routed tube pockets | 1 | pc | Cherry or walnut S4S 3/4" x 1.5" x 8.5" | Make | drawings/siku-frame-rail-detail.svg | 3.50 | 3.50 | Pocket width = 0.488"; depth = 0.164"; pitch = 0.556" C-C
SKZ-C-05 | SKZ-CHILI Shared | Frame Rail — Bottom (Chili) | Cherry or walnut S4S rail — bottom binding rail | 1 | pc | Cherry or walnut S4S 3/4" x 1.5" x 8.5" | Make | drawings/siku-frame-rail-detail.svg | 3.50 | 3.50 | Same spec as top rail
SKZ-C-06 | SKZ-CHILI Shared | Binding Cord (Chili) | Waxed linen or nylon cord | 1 | lot | Waxed linen 0.5-1mm; ~50 ft per instrument | Buy |  | 0.10 | 0.10 | Thinner cord preferred for Chili — less bulk around narrow tubes
SKZ-SHARED-01 | All Members | Chromatic Tuner | Clip-on or phone-based chromatic tuner for pitch validation | 1 | ea | Accuracy ±1 cent or better; Snark SN-8 or GuitarTuna app | Buy |  | 15.00 | 15.00 | Shared across all 4 builds; use same tuner for all measurements
SKZ-SHARED-02 | All Members | Beeswax Block | Raw filtered beeswax for tube end plugs; shared across all members | 1 | ea | 4 oz block; food-grade or filtered | Buy |  | 3.00 | 3.00 | Melts at ~145°F; pour at 160°F
SKZ-SHARED-03 | All Members | Abrasive Paper | Sandpaper for tube end squaring and finishing | 1 | lot | 80/150/320/400 grit assortment | Buy |  | 2.00 | 2.00 | Flat on glass plate for tube end squaring
SKZ-SHARED-04 | All Members | Finish — Danish Oil | Wood finish for cherry/walnut frame rails | 1 | ea | Danish oil or tung oil — 1 pint | Buy |  | 8.00 | 8.00 | Apply before tube insertion; 2 coats; buff to satin

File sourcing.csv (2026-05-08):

part_id | part_name | spec_required | supplier_candidates | search_terms | unit_price_est | min_order | lead_time_est | date_checked | url_source | substitute_acceptable | substitute_risk | sourcing_notes
SKZ-T-01 | Arka Tube Toyo (Bamboo) | Cañahueca bamboo OD ~1.0-in bore ~0.75-in wall ~0.125-in; 10-ft blanks minimum; straight grain no cracks | Bamboo Craftsman (US); Tropical Bamboo (FL); Amazon - bamboo tube bulk | bamboo cane tube 1 inch bore panflute | TBD per ft | 5 ft min | 1-2 weeks | TBD | TBD | PVC Sch40 1-in nominal (ID ~0.824-in — measure actual) | PVC ID may be slightly oversized vs 0.75-in bore spec; recalculate lengths if actual ID differs
SKZ-T-01-ALT | Arka Tube Toyo (PVC) | PVC Schedule 40 pipe — 1-in nominal (actual ID ~0.824-in verify); length 36-in minimum per stick | Home Depot; Lowes; local plumbing supply | PVC pipe 1 inch Schedule 40 | ~$0.50/ft | 10-ft stick | In stock | TBD | TBD | Bamboo preferred | PVC adds slight weight; tone quality differs from bamboo; adequate for prototyping
SKZ-Z-01 | Arka Tube Zanka (Bamboo) | Cañahueca bamboo OD ~0.82-in bore ~0.625-in; 10-ft blanks; straight consistent bore | Same as Toyo suppliers — specify smaller bore | bamboo tube 5/8 bore panpipe zampoña | TBD per ft | 5 ft min | 1-2 weeks | TBD | TBD | PVC Sch40 3/4-in nominal (ID ~0.622-in — close match) | Minimal substitution risk if actual PVC ID verified
SKZ-Z-01-ALT | Arka Tube Zanka (PVC) | PVC Schedule 40 3/4-in nominal (actual ID ~0.622-in); verify with calipers | Home Depot; Lowes | PVC pipe 3/4 inch Schedule 40 | ~$0.40/ft | 10-ft stick | In stock | TBD | TBD | Bamboo preferred | ID match is excellent for Zanka — good prototyping option
SKZ-M-01 | Arka Tube Malta (Bamboo) | Bamboo OD ~0.66-in bore ~0.50-in; harder to source in this exact size | Bamboo specialty suppliers; try 0.5-in ID bamboo arrow shaft suppliers | bamboo arrow shaft 1/2 inch bore | TBD | 5 ft min | 2-3 weeks | TBD | TBD | PVC 1/2-in nominal (ID ~0.622-in — oversized for 0.5-in spec) | Oversized PVC bore will affect tube lengths; recalculate with actual measured ID
SKZ-C-01 | Arka Tube Chili (Bamboo) | Fine bamboo cane OD ~0.49-in bore ~0.375-in; thin-wall; arrow shaft size | Archery supply; Bamboo Craftsman small-bore section | bamboo arrow shaft 3/8 bore | TBD | 10 pc min | 1-3 weeks | TBD | TBD | Thin-wall PVC or hardwood dowel bored to 3/8-in | Hardwood dowel feasible on lathe; hardest size to source in bamboo
SKZ-PLUG | Beeswax Block | Raw beeswax food/craft grade; block or pellets; 2+ oz for full family build | Amazon; local beekeeping supply; woodworking stores | beeswax block craft raw | ~$3/2 oz | 1 block | In stock | TBD | TBD | Paraffin wax (slightly lower density) | Paraffin may leak at high temperatures — not recommended for instruments stored in cars
SKZ-CORD | Binding Cord | Waxed cotton thread or linen cord 1/16-in dia 50-ft spool | Tandy Leather; Amazon bookbinding cord; craft stores | waxed linen cord 1/16 bookbinding | ~$5/spool | 1 spool | In stock | TBD | TBD | Waxed polyester cord | Any non-stretch waxed or resin-treated cord works; avoid elastic
SKZ-RAIL | Cherry Frame Rail Stock | Cherry S4S 3/4 × 4 × 24-in minimum (mill down to 3/8 × 1.5-in); straight grain no defects | Woodcraft; Rockler; local hardwood dealer | cherry lumber S4S | ~$4-6/bf | 1 bf | In stock | TBD | TBD | Walnut or hard maple of same dimensions | Any hard dense species suitable; avoid softwood (poor pocket durability)
SKZ-GLUE | Titebond III | Frame-to-tube bond; waterproof; open time 10 min | Amazon; Home Depot; Woodcraft | Titebond III wood glue | ~$8/8 oz | 1 bottle | In stock | TBD | TBD | West System epoxy for PVC tubes (Titebond won't bond PVC) | Use epoxy for PVC tubes; Titebond for bamboo-to-wood
SKZ-FINISH | Danish Oil | Frame rail exterior finish; 3 coats; wipe-on | Home Depot; Amazon | Watco Danish Oil Natural | ~$12/pint | 1 pint | In stock | TBD | TBD | Tung oil or linseed oil | Any penetrating oil-varnish blend suitable
SKZ-TUNER | Chromatic Tuner | ±1 cent accuracy; clips to tube or microphone pickup; battery operated | Amazon; Guitar Center; Sweetwater | chromatic tuner Korg CA-1 clip | ~$15-25 | 1 | In stock | TBD | TBD | Phone app (PitchLab Pro or equivalent) | Phone microphone adequate if quiet environment; dedicated tuner more reliable in shop

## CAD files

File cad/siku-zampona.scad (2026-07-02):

// Siku (Zampoña) parametric master — two-rank closed-pipe tube envelope.
//
// Authority: pending_measurement. NOT fabrication authority until reviewed
// against a measured/built prototype (see visual-output-register.csv and
// build-packet-status.md — cad/ row is "partial").
//
// Dimension sources (do not edit values without updating the source record):
//   - member selection (bore/wall/OD/frame width/root pitch): family-spec.csv
//     columns bore_id_in, wall_in, od_in, frame_width_in, root_hz, root_note.
//   - governing model (closed/stopped cylindrical pipe, quarter-wave):
//     design.md §2.1 "Stopped Pipe":
//       f = c / (4 * L_eff)
//       L_eff = L_physical + ΔL_end,  ΔL_end ≈ 0.82 × bore_ID
//       => L_physical = c / (4f) - 0.82 × bore_ID
//     c = 13,552 in/s (68°F/20°C shop standard, design.md §2.1;
//     family-spec.csv column c_in_per_s). end_correction_coeff = 0.82 is
//     Tony's empirical convention (~2x the physics unflanged-end value
//     0.3*d — bundles embouchure effects; unvalidated per risks.md AC-05).
//     Cross-checked against siku-zampona-design-table.xlsx tube-length
//     formula cells (e.g. row 14: "=3388/(((2^(1/12))^(...))*440)-0.82*bore",
//     3388 = 13552/4) via inspect_instrument_workbook.py.
//   - trim allowance +0.1875 in (3/16"): family-spec.csv trim_allowance_in,
//     design.md §2.2.
//   - arka/ira semitone offset schedule: design.md §2.3
//     Arka (7 tubes): offsets [0, 4, 7, 10, 14, 17, 21] from root
//     Ira  (6 tubes): offsets [2, 5, 9, 12, 16, 19] from root
//   - tube center-to-center gap 0.0625 in: family-spec.csv tube_gap_in.
//
// Scope boundary: this is a TWO-RANK (arka + ira) tube-LENGTH ENVELOPE only.
// Each tube is modeled as a plain open/hollow cylinder at its computed
// closed-pipe length. Voicing/mouth-edge (embouchure) geometry, bottom-end
// plug/node/bevel detail, and frame-rail pocket geometry are explicitly
// OUT OF SCOPE here — no blow-edge chamfer or bevel is modeled. See
// assembly-manual.md and bom.csv for the physical sealing/binding process.
//
// Units: inches.

/* [Variant] */
// 0=Toyo (bass), 1=Zanka (tenor, primary build target per README), 2=Malta (alto), 3=Chili (soprano)
variant = 1;

member_names       = ["Toyo", "Zanka", "Malta", "Chili"];               // family-spec.csv member_id / size_class
root_notes         = ["D3", "G3", "D4", "A4"];                          // family-spec.csv root_note
root_hz_list       = [146.83, 196.00, 293.66, 440.00];                  // family-spec.csv root_hz
bore_id_in_list    = [0.750, 0.625, 0.500, 0.375];                      // family-spec.csv bore_id_in
wall_in_list       = [0.125, 0.098, 0.079, 0.059];                      // family-spec.csv wall_in
od_in_list         = [1.000, 0.821, 0.658, 0.493];                      // family-spec.csv od_in (== bore + 2*wall)
frame_width_in_list = [13.750, 11.423, 9.304, 7.159];                   // family-spec.csv frame_width_in (reference/echo check only)

root_hz     = root_hz_list[variant];
bore_id_in  = bore_id_in_list[variant];
od_in       = od_in_list[variant];

/* [Rank schedule — design.md §2.3] */
arka_offsets = [0, 4, 7, 10, 14, 17, 21]; // 7 tubes, leader/female rank
ira_offsets  = [2, 5, 9, 12, 16, 19];     // 6 tubes, follower/male rank

/* [Constants — family-spec.csv / design.md §2.1-2.2] */
c_in_per_s          = 13552;   // speed of sound, in/s, 68F shop standard
end_correction_coeff = 0.82;   // Tony's empirical closed-end correction convention
trim_allowance_in    = 0.1875; // 3/16" post-cut tuning trim, added to every physical length
tube_gap_in           = 0.0625; // center-gap between adjacent tube walls in a rank

// ---------------------------------------------------------------------------
// Derived geometry (formulas, not baked values)
// ---------------------------------------------------------------------------

function midi_free_hz(offset) = root_hz * pow(2, offset / 12); // equal-temperament offset from root_hz

// Closed/stopped cylindrical pipe: L_physical = c/(4f) - end_correction_coeff * bore_ID
function tube_length_calc_in(f) = c_in_per_s / (4 * f) - end_correction_coeff * bore_id_in;
function tube_length_cut_in(f)  = tube_length_calc_in(f) + trim_allowance_in;

function arka_hz(n)     = midi_free_hz(arka_offsets[n]);
function ira_hz(n)      = midi_free_hz(ira_offsets[n]);
function arka_len_in(n) = tube_length_cut_in(arka_hz(n));
function ira_len_in(n)  = tube_length_cut_in(ira_hz(n));

arka_count = len(arka_offsets);
ira_count  = len(ira_offsets);

// ---------------------------------------------------------------------------
// Modules
// ---------------------------------------------------------------------------

// Plain closed-pipe tube envelope: hollow cylinder, open both ends (bottom
// seal/plug is a physical assembly step — assembly-manual.md — not modeled).
module closed_tube(length_in, od_val_in, bore_val_in) {
  difference() {
    cylinder(h = length_in, d = od_val_in, $fn = 48);
    translate([0, 0, -0.01])
      cylinder(h = length_in + 0.02, d = bore_val_in, $fn = 48);
  }
}

// One rank: `count` tubes placed left-to-right (longest/lowest pitch first),
// tops flush at z=0 (the blow/open end), descending profile toward +x, per
// design.md §4.1 "Tubes align flush at the blow end (top)."
module rank(count, len_in_func) {
  for (i = [0 : count - 1]) {
    len_in = len_in_func(i);
    translate([i * (od_in + tube_gap_in), 0, -len_in])
      closed_tube(len_in, od_in, bore_id_in);
  }
}

module arka_rank() { rank(arka_count, function (n) arka_len_in(n)); }
module ira_rank()  { rank(ira_count,  function (n) ira_len_in(n)); }

// Visualization spacing between the arka and ira rows. The two ranks are
// traditionally bound/played as SEPARATE instruments (design.md §4.1); this
// gap is a layout convenience for viewing both ranks together, not a lashing
// or shared-frame spec (frame-rail geometry is out of scope — see cad/README.md).
rank_row_gap_in = 1.5; // assumption; not sourced from family-spec.csv

module siku_assembly() {
  arka_rank();
  translate([0, od_in + rank_row_gap_in, 0])
    ira_rank();
}

siku_assembly();

// Echo the tube-length schedule so `openscad` runs double as a numeric check
// against family-spec.csv (arkaN_L_cut / iraN_L_cut columns for this member).
echo(str("member=", member_names[variant], " root=", root_notes[variant],
         " root_hz=", root_hz, " bore_id_in=", bore_id_in, " od_in=", od_in));
for (n = [0 : arka_count - 1])
  echo(str("arka_", n + 1, "_hz=", arka_hz(n), " L_cut_in=", arka_len_in(n)));
for (n = [0 : ira_count - 1])
  echo(str("ira_", n + 1, "_hz=", ira_hz(n), " L_cut_in=", ira_len_in(n)));

// family-spec.csv frame_width_in is the FULL 13-tube (arka+ira combined)
// row width per design.md §4.3, not either rank alone.
total_tube_count = arka_count + ira_count;
computed_frame_width_in = total_tube_count * od_in + (total_tube_count - 1) * tube_gap_in;
echo(str("computed_13tube_frame_width_in=", computed_frame_width_in,
         " family_spec_frame_width_in=", frame_width_in_list[variant]));

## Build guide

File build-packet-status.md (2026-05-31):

# Siku (Zampoña) — Build-Packet Status

**Refs:** https://github.com/tonykoop/siku-zampona/issues/1
Generated: 2026-05-19

This file maps every deliverable from issue #1 to a file path in this repo
and records honest readiness. It is the single source of truth for which
issue-#1 boxes are closed, partial, or open. If `README.md`, `design.md`,
`capstone-manifest.json`, or any other file disagrees, fix the other file —
not this one.

`review-evidence.md` is the round-by-round review log; this file is the
deliverable-by-deliverable status ledger.

## Readiness

Stated level: **L2 root-mode packet (instrument-maker-v4 v4.3, 2026-05-08)**.

No L3 or L4 claims. No built instrument, no measured tube frequencies, no
measured trim deltas, no measured cents error. See **Open Gates** below for
what would have to change for L3 promotion.

## Engineering Documents

| Issue deliverable | Status | File | Note |
| --- | --- | --- | --- |
| `design.md` | closed | `design.md` | Stopped-pipe model, governing equation, end-correction convention, four-member family rationale |
| `assembly-manual.md` | closed | `assembly-manual.md` | Build sequence for tubes, plug seating, frame, wrap |
| `bom.csv` | closed | `bom.csv` | Bamboo and PVC paths, frame stock, beeswax, cord, finishing |
| `cut-list.csv` | closed | `cut-list.csv` | Tube lengths per family member with trim allowance |
| `sourcing.csv` | closed | `sourcing.csv` | Suppliers, lead time, MOQ, substitutes |
| `validation.csv` | partial | `validation.csv` | Measurement protocol present; **measured rows empty** until a build runs |
| `visual-bom-brief.md` | closed | `visual-bom-brief.md` | Image-per-row layout brief |
| `drawing-brief.md` | closed | `drawing-brief.md` | Strat-quality drawing requirements |
| `supplier-rfq.md` | closed | `supplier-rfq.md` | RFQ template |

## Wolfram and Interactive

| Issue deliverable | Status | File | Note |
| --- | --- | --- | --- |
| `wolfram-starter.wl` | closed | `wolfram-starter.wl` + `wolfram/instrument-model.wl` | Manipulate notebook source for tuning / geometry sweep; not executed in CI |

Per repo policy, `.wl` source is committed but `wolframscript -activate` is
not run from agent panes; verification belongs to the manager-queued
Wolfram pass.

## Capstone and Print Packet

| Issue deliverable | Status | File | Note |
| --- | --- | --- | --- |
| `capstone-deck.md` | closed | `capstone-deck.md` | Review-deck outline |
| `capstone-deck.pptx` | closed | `capstone-deck.pptx` | Cowork-mode deck binary |
| `capstone-manifest.json` | closed | `capstone-manifest.json` | Machine-readable artifact map |
| `print-packet.md` | closed | `print-packet.md` | Printable packet index |
| `print-packet.html` | closed | `print-packet.html` | HTML rendering |
| `print-packet.pdf` | closed | `print-packet.pdf` | PDF rendering |

## Folders and Assets

| Issue deliverable | Status | File | Note |
| --- | --- | --- | --- |
| `cad/` | partial | `cad/README.md` (this PR) | No native SolidWorks/STEP yet; dimensional authority is `siku-zampona-design-table.xlsx` + `wolfram/instrument-model.wl` + `drawings/*.svg`. See `cad/README.md` for the authority chain and what would have to land for L3 CAD |
| `cnc/` | closed | `cnc/operations.csv`, `cnc/setup-sheet.md` | Operations and setup sheet present |
| `drawings/` | closed | `drawings/siku-{toyo,zanka,malta,chili}-{elevation,frame}.svg`, `siku-family-overview.svg`, `siku-tube-section.svg` | 10 SVGs covering all four family members |
| `images/` | partial | `images/README.md` (this PR) | No hero photo, no concept render, no build photo yet. Photo plan lives in `photo-shotlist.md` and is the source of truth for what belongs here |
| `data/` | open | n/a | Deferred in the issue itself: "added once builds begin". No build has run, so no data row exists |

## README Polish

| Issue deliverable | Status | File | Note |
| --- | --- | --- | --- |
| Polished `README.md` | closed | `README.md` | Family overview table, arka/ira split, tube-length formula, cross-references; not a skeleton |

A hero-image swap is deferred until a real build photo or owned concept
render lands in `images/`.

## Open Gates

The following gates remain open and would have to close before any L3 or
"build-ready" claim is permitted:

- **Built Zanka member** — at least one full Zanka build, with every tube
  cut, trimmed, and plug-seated.
- **Measured tube frequencies** — every Zanka tube recorded in
  `validation.csv` with measured Hz, cents error, and trim history.
- **Measured breath response** — recorded for at least the Arka and Ira
  ranks of the Zanka.
- **Native CAD or STEP** — see `cad/README.md` for the authority chain and
  what counts as L3 CAD.
- **Owned hero image** — at least one shot from `photo-shotlist.md` filed
  under `images/` with attribution and licence status recorded.
- **Cultural/provenance human review** — already named as a close gate in
  `review-evidence.md`; the existing `resources.md` cites
  Turino, Baumann, and Gérard and is honest about being read-not-reviewed.

## Polish-Claim Block List

Until the gates above close, the following claims must not appear in
`README.md`, marketing copy, build-log site, capstone deck text, image
captions, or any sibling repo:

- "Measured", "tuned to ±N cents", "validated against build" — blocked
  until measured rows fill in `validation.csv`.
- "Build-ready", "L3", "release", "production-ready", "shop-tested" —
  blocked until a built Zanka exists.
- "SolidWorks model", "STEP file", "native CAD" — blocked until `cad/`
  contains real native CAD files; see `cad/README.md`.
- "Hero photo of the finished instrument" — blocked until a real photo
  lives in `images/`.
- "Authentic", "traditional Aymara reconstruction", "heritage panpipe" —
  blocked until cultural review closes per `review-evidence.md` and
  `resources.md`.

## Why Issue #1 Remains Open After This PR

This PR scaffolds status tracking and adds honest placeholders for the two
literal folder gaps (`cad/` and `images/`). It does not close issue #1.
The issue closes when at least the **Built Zanka member** + **Measured tube
frequencies** + **Owned hero image** rows above close — at which point the
packet has L3-empirical evidence rather than L2 design-only authority.

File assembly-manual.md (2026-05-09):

# Siku (Zampoña) — Assembly Manual

**Instrument:** Siku / Zampoña (Andean Panpipe Family)  
**Packet:** v4.3 · Date: 2026-05-08  
**Applies to:** SKZ-TOYO · SKZ-ZANKA · SKZ-MALTA · SKZ-CHILI

---

## Safety and Setup

- Wear eye protection when cutting tubes on the miter saw or band saw.
- Wear hearing protection when routing frame rails.
- Keep beeswax away from open flames — melt in a double boiler only.
- Work in a well-ventilated space when applying finish to frame rails.
- Do not rush the tuning trim phase — cutting too short is irreversible.

**Tools required:**

| Tool | Use |
|---|---|
| Miter saw or fine-tooth hand saw | Cutting tubes to rough length |
| Drill press or lathe | Boring hardwood/PVC blanks (if not using pre-bored stock) |
| CNC router or router table | Frame rail pocket routing |
| Calipers (0.001" resolution) | Bore ID and OD verification |
| Chromatic tuner (Korg CA-1 or equivalent) | Pitch measurement during trim |
| Double boiler + thermometer | Beeswax melting (max 185°F) |
| Sandpaper 220/320 grit + dowel caul | Tube end finishing |
| Waxed cord + blunt needle | Binding lash |

---

## Phase 1 — Stock Preparation and Bore Verification

### 1A. Measure Actual Bore ID

Before computing or trusting any cut lengths, **verify the actual bore ID** of your tube stock with calipers.

The design table assumes nominal bore IDs (0.750", 0.625", 0.500", 0.375" for Toyo through Chili). Natural bamboo can vary ±0.050" from nominal. If your actual bore differs, the tube lengths from `family-spec.csv` and `cut-list.csv` will be slightly off.

**Recalculation formula:**

```
L_physical = 13552 / (4 × f_hz) − 0.82 × actual_bore_ID_in
```

Record actual bore measurements in `validation.csv` rows `VAL-BORE-01` through `VAL-BORE-04`.

### 1B. Select and Inspect Blanks

- Bamboo: look for straight, crack-free sections. Node spacing must exceed your longest tube length (22.6" for Toyo — this may require selecting between nodes on long blanks).
- PVC: confirm Schedule 40 designation; measure actual ID with caliper before cutting. Degrease with isopropyl alcohol before sealing or bonding.
- Hardwood (if boring from solid): grain must run parallel to bore axis. Avoid knots near the bore path.

---

## Phase 2 — Tube Cutting

### 2A. Mark Lengths

Mark each tube with a fine-point marker at the **L_cut** length from `cut-list.csv`. Double-check the mark before cutting. Label the tube with its note name and member ID (e.g., "Z-A3 D4").

### 2B. Cut Tubes

- Use a fine-tooth miter saw blade (80T for PVC, 60T for bamboo) to minimize tearout at the cut end.
- For bamboo, orient the cut so the open end faces the blade — this prevents splitting the culm wall.
- Lightly sand the cut end flat and perpendicular on 220-grit paper wrapped around a flat block. The open (blow) end must be perfectly flat; a beveled end affects embouchure angle and can introduce a systematic pitch error.

### 2C. Verify Squareness

Hold each tube upright against a machinist square. The open end must be perpendicular to the bore axis within ±0.5°.

---

## Phase 3 — Closed-End Sealing

### 3A. Option A — Natural Bamboo Node (preferred)

If the blank has a natural node at the desired closed-end position (within ±1/8" of L_cut from the open end), the node forms a nearly perfect closed-end reflector.

- Clean the node interior with a bottle brush; remove any pith material.
- Seal with a thin beeswax coat for moisture protection.

### 3B. Option B — Beeswax Plug

1. Melt beeswax in a double boiler to ~160°F. Do not overheat.
2. Stand the tube upright, closed-end down. Pour molten wax to a depth of ~3/8" (Toyo/Zanka) or ~1/4" (Malta/Chili).
3. Allow to cool completely before handling (~20 minutes at room temperature).
4. Verify the plug is solid and flush with the tube wall — no voids or cracks.

> **Acoustic note:** Beeswax provides an excellent rigid boundary. The tube will be slightly sharp immediately after pouring (warm wax), then settle to pitch as it cools. Always measure at shop temperature.

### 3C. Option C — Wood Dowel Plug

- Turn a dowel to a light press fit (0.002"–0.005" undersize from bore ID).
- Apply Titebond III to the dowel, press in to 1/2" depth, allow to cure 24 hours.
- Trim flush with a chisel and sand level.

---

## Phase 4 — First Tuning Pass

### 4A. Measure Before Trimming

After sealing, measure every tube with the chromatic tuner. Blow across the open end at a consistent 45° embouchure angle. Record the measured pitch in `validation.csv`.

Expected result: tubes should measure between 0 and +15 cents sharp (due to the trim allowance). If any tube measures flat at this stage, something is wrong — check the plug length, bore ID, or re-measure the cut length.

### 4B. Trim to Pitch

- Trim only from the **open (blow) end** — never from the closed end.
- Remove material in ≤1/32" increments. Use the miter saw or a fine file; sand the end flat after each cut.
- Re-measure after each increment. Stop when the tube reads 0 to +2 cents (give the player slight room to tune sharp with breath pressure if desired).
- Record final measured frequency and cents error in `validation.csv`.

**Do not over-trim.** A tube that is more than 5 cents flat cannot be corrected without plugging the closed end with more wax (which adjusts the effective acoustic length) — messy and imprecise.

---

## Phase 5 — Frame Rail Fabrication

### 5A. Mill Rails to Dimension

For each family member, mill two cherry or walnut rails to:

| Member | Rail thickness | Rail width | Rail length |
|---|---|---|---|
| Toyo | 3/8" | 1.5" | 14.75" |
| Zanka | 3/8" | 1.5" | 12.4" |
| Malta | 3/8" | 1.5" | 10.3" |
| Chili | 3/8" | 1.5" | 8.2" |

Joint one face and one edge flat before routing pockets.

### 5B. CNC Tube Pockets

Route tube pockets on the CNC router or router table using a straight bit equal to the OD of the tubes (or slightly undersize for a press fit). See `cnc/setup-sheet.md` for the full operation plan.

Pocket depth = 1/3 × OD:

| Member | OD | Pocket depth |
|---|---|---|
| Toyo | 1.000" | 0.333" |
| Zanka | 0.821" | 0.274" |
| Malta | 0.658" | 0.219" |
| Chili | 0.493" | 0.164" |

Pocket spacing = OD + 1/16" gap, 13 pockets per rail.

> **Photo placeholder:** _[Photo: CNC routing tube pockets in cherry rail — Zanka size]_

### 5C. Finish Rails

Sand to 220 grit. Apply 3 coats of Watco Danish Oil, wiping off excess after 15 minutes per coat. Allow 24 hours cure before assembly.

---

## Phase 6 — Assembly

### 6A. Dry Fit

Before any glue, dry-fit all 13 tubes in the top rail. Verify:
- All tubes seat fully in pockets.
- Blow ends are flush with the rail face (±1/32").
- No gaps between rail and tube wall.

Correct any tight pockets with a drum sander or round file.

### 6B. Glue-Up

1. Apply a thin bead of Titebond III (bamboo/wood) or West System epoxy (PVC) into each pocket.
2. Press tubes in one at a time, working from the longest to shortest.
3. Clamp the rail against the tubes with a caul and clamps. Allow 2 hours minimum before disturbing.

### 6C. Second Rail and Binding

The bottom rail can be:

- **Flat** (all tubes extend below the rail at varying lengths — traditional stepped appearance): Glue and clamp the second rail 2–4" below the blow end.
- **Profile cut** (bottom edge follows the stepped tube profile): Mark the tube bottom ends on the rail, cut the stepped profile on the band saw, then glue and clamp.

Finish with two wraps of waxed cord: one wrap 1/4" from the top rail, one wrap at the bottom rail. Lash with a square knot; wax the knot.

> **Photo placeholder:** _[Photo: Completed Zanka arka rank — cord lashing detail]_

---

## Phase 7 — Final Tuning and Validation

### 7A. Post-Assembly Pitch Check

After the glue has fully cured (24 hours), measure every tube again with the tuner. The assembly process should not have shifted pitch significantly. If any tube has moved more than ±3 cents from Phase 4 readings, check the plug for cracking or that no glue entered the bore.

### 7B. Validate Against Spec

Complete all rows in `validation.csv`. Sign off with temperature, RH, and date.

Target: all tubes within ±5 cents of target (±10 cents for Toyo bass tubes where breath embouchure variance is higher).

### 7C. Duet Setup

Once both arka and ira ranks are complete, hold them side by side with arka on the left (longest tube at player's left). Play a diatonic scale by alternating between arka and ira (arka provides notes 1, 3, 5, ♭7, 9, 11, 13; ira provides 2, 4, 6, 8, 10, 12 of the combined scale).

Confirm all 13 notes are playable and the combined scale is in tune.

---

## Phase 8 — Finishing Touches

### 8A. Decorative Cord Wrap (Optional)

Traditional siku may have colored yarn or patterned cord wrapping in addition to the structural cord. Alpaca or wool yarns in traditional Andean patterns (red/black/yellow) are appropriate; any non-elastic yarn works.

### 8B. Maintenance

- Store in a dry case or wrapped in cloth; avoid extreme temperature changes.
- Beeswax plugs may soften slightly in hot vehicles — store away from direct sunlight.
- Re-tune after significant humidity change — bamboo responds more than PVC.
- Inspect cord wraps annually; re-wax if the cord feels dry or shows fraying.

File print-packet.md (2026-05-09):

# Siku (Zampoña) — Print Packet

**Heifer Zephyr · instrument-maker-v4 · packet v4.3 · 2026-05-08**  
**Instrument:** Siku (Zampoña) — Andean Panpipe, Four-Member Family  
**Primary build target:** Zanka (key of C, tenor, bore ⌀0.625")

---

## Quick Reference

| Parameter | Value |
|---|---|
| Tube length formula | `L_calc = 13552 / (4 × f_hz) − 0.82 × bore_ID` |
| Trim allowance | `L_cut = L_calc + 3/16"` |
| Speed of sound | 13,552 in/s at 68°F |
| Tuning standard | A4 = 440 Hz, equal temperament |
| End correction | 0.82 × bore_ID (empirical) |
| Pipe type | Stopped cylindrical; odd harmonics only (1f, 3f, 5f…) |

---

## Family Tube Dimensions

### Toyo (Bass · G3 root · bore 0.750" · OD 1.000")

| Tube ID | Rank | Note | Hz | L_calc (in) | L_cut (in) |
|---|---|---|---|---|---|
| T-A1 | Arka | G3 | 196.00 | 22.459 | 22.646 |
| T-I1 | Ira | A3 | 220.00 | 19.958 | 20.146 |
| T-A2 | Arka | B3 | 246.94 | 17.742 | 17.929 |
| T-I2 | Ira | C4 | 261.63 | 16.709 | 16.896 |
| T-A3 | Arka | D4 | 293.66 | 14.820 | 15.007 |
| T-I3 | Ira | E4 | 329.63 | 13.139 | 13.327 |
| T-A4 | Arka | F4 | 349.23 | 12.378 | 12.565 |
| T-I4 | Ira | G4 | 392.00 | 10.979 | 11.166 |
| T-A5 | Arka | A4 | 440.00 | 9.629 | 9.817 |
| T-I5 | Ira | B4 | 493.88 | 8.546 | 8.733 |
| T-A6 | Arka | C5 | 523.25 | 8.054 | 8.242 |
| T-I6 | Ira | D5 | 587.33 | 7.128 | 7.315 |
| T-A7 | Arka | E5 | 659.26 | 6.267 | 6.455 |

Frame width (Toyo): **13.750"** · Pocket pitch: 1.063" C-C · Pocket width: 0.995"

---

### Zanka (Tenor · C4 root · bore 0.625" · OD 0.821") ← Primary Build

| Tube ID | Rank | Note | Hz | L_calc (in) | L_cut (in) |
|---|---|---|---|---|---|
| Z-A1 | Arka | G3 | 196.00 | 16.961 | 17.148 |
| Z-I1 | Ira | A3 | 220.00 | 15.076 | 15.264 |
| Z-A2 | Arka | B3 | 246.94 | 13.395 | 13.582 |
| Z-I2 | Ira | C4 | 261.63 | 12.620 | 12.807 |
| Z-A3 | Arka | D4 | 293.66 | 11.157 | 11.344 |
| Z-I3 | Ira | E4 | 329.63 | 9.878 | 10.065 |
| Z-A4 | Arka | F4 | 349.23 | 9.292 | 9.479 |
| Z-I4 | Ira | G4 | 392.00 | 8.231 | 8.418 |
| Z-A5 | Arka | A4 | 440.00 | 7.188 | 7.375 |
| Z-I5 | Ira | B4 | 493.88 | 6.447 | 6.635 |
| Z-A6 | Arka | C5 | 523.25 | 6.060 | 6.247 |
| Z-I6 | Ira | D5 | 587.33 | 5.328 | 5.516 |
| Z-A7 | Arka | E5 | 659.26 | 4.627 | 4.814 |

Frame width (Zanka): **11.423"** · Pocket pitch: 0.884" C-C · Pocket width: 0.816"

---

### Malta (Alto · G4 root · bore 0.500" · OD 0.658")

| Tube ID | Rank | Note | Hz | L_calc (in) | L_cut (in) |
|---|---|---|---|---|---|
| M-A1 | Arka | G4 | 392.00 | 7.565 | 7.752 |
| M-I1 | Ira | A4 | 440.00 | 6.728 | 6.915 |
| M-A2 | Arka | B4 | 493.88 | 5.971 | 6.158 |
| M-I2 | Ira | C5 | 523.25 | 5.638 | 5.826 |
| M-A3 | Arka | D5 | 587.33 | 4.978 | 5.165 |
| M-I3 | Ira | E5 | 659.26 | 4.389 | 4.576 |
| M-A4 | Arka | F5 | 698.46 | 4.144 | 4.332 |
| M-I4 | Ira | G5 | 783.99 | 3.624 | 3.811 |
| M-A5 | Arka | A5 | 880.00 | 3.214 | 3.401 |
| M-I5 | Ira | B5 | 987.77 | 2.823 | 3.010 |
| M-A6 | Arka | C6 | 1046.50 | 2.669 | 2.857 |
| M-I6 | Ira | D6 | 1174.66 | 2.339 | 2.526 |
| M-A7 | Arka | E6 | 1318.51 | 2.074 | 2.261 |

Frame width (Malta): **9.304"** · Pocket pitch: 0.721" C-C · Pocket width: 0.653"

---

### Chili (Soprano · A4 root · bore 0.375" · OD 0.493")

| Tube ID | Rank | Note | Hz | L_calc (in) | L_cut (in) |
|---|---|---|---|---|---|
| C-A1 | Arka | A4 | 440.00 | 7.565 | 7.752 |
| C-I1 | Ira | B4 | 493.88 | 6.728 | 6.915 |
| C-A2 | Arka | C#5 | 554.37 | 5.971 | 6.158 |
| C-I2 | Ira | D5 | 587.33 | 5.638 | 5.826 |
| C-A3 | Arka | E5 | 659.26 | 4.978 | 5.165 |
| C-I3 | Ira | F#5 | 739.99 | 4.389 | 4.576 |
| C-A4 | Arka | G5 | 783.99 | 4.144 | 4.332 |
| C-I4 | Ira | A5 | 880.00 | 3.624 | 3.811 |
| C-A5 | Arka | B5 | 987.77 | 3.214 | 3.401 |
| C-I5 | Ira | C#6 | 1108.73 | 2.823 | 3.010 |
| C-A6 | Arka | D6 | 1174.66 | 2.669 | 2.857 |
| C-I6 | Ira | E6 | 1318.51 | 2.339 | 2.526 |
| C-A7 | Arka | F#6 | 1479.98 | 1.982 | 2.170 |

Frame width (Chili): **7.159"** · Pocket pitch: 0.556" C-C · Pocket width: 0.488"

**⚠ C-A7 (F#6, L_cut = 2.170") is at the practical playability limit. Prototype this tube first before committing production stock. Consider building Chili as 11 tubes (omit C-A7 and C-I6).**

---

## CNC Rail Parameters (All Members)

| Member | OD | Pocket Width | Pocket Depth | Pocket Pitch | First Center |
|---|---|---|---|---|---|
| Toyo | 1.000" | 0.995" | 0.333" | 1.063" | 0.500" |
| Zanka | 0.821" | 0.816" | 0.274" | 0.884" | 0.411" |
| Malta | 0.658" | 0.653" | 0.219" | 0.721" | 0.329" |
| Chili | 0.493" | 0.488" | 0.164" | 0.556" | 0.247" |

Pocket depth = OD/3 · Pocket pitch = OD + 1/16" · Z0 = top of stock

---

## Tube Sealing — Beeswax Plug Depths

| Member | Plug Depth | Stand Hole ⌀ |
|---|---|---|
| Toyo | 3/8" | 1.010" |
| Zanka | 3/8" | 0.831" |
| Malta | 1/4" | 0.668" |
| Chili | 1/4" | 0.503" |

Pour beeswax at 160°F. Allow 30 min cure before handling.

---

## Tuning Acceptance Criteria

| Metric | Criterion |
|---|---|
| Pitch tolerance | ±5 cents of target frequency |
| Maximum trim | ≤ 3/16" below L_calc (scrap if exceeded) |
| Environment | Measure and trim at same temperature |
| Reference | A4 = 440 Hz on calibrated chromatic tuner |

---

## Material Shortlist (Zanka Build Only)

| Item | Spec | Qty | Notes |
|---|---|---|---|
| Bamboo tube stock | ~0.821" OD / 0.625" bore; 18" sticks | 16 sticks | Cañahueca preferred; sort by bore before cutting |
| Cherry S4S | 3/4" × 1.5" × 12.5" | 4 pcs (2 rails × 2 ranks) | Can also use walnut |
| Beeswax | 4 oz block | 1 | Shared with other members |
| Waxed linen cord | 1mm, ~80 ft | 1 spool | Nylon acceptable |
| Danish oil | 1 pint | 1 | For cherry rails |

---

## Assembly Checklist

- [ ] Bore ID verified within +0.000" / −0.010" of target for all tubes
- [ ] All 13 tubes cut to L_cut lengths from this table; labeled with tube ID
- [ ] Sealing stand built (Zanka: 13 holes at 0.831" ⌀, spaced 0.884" C-C)
- [ ] Beeswax plugs poured and cured
- [ ] First-pass tuning complete; all deviations recorded in validation.csv
- [ ] Frame rails milled; pocket width verified with first pocket before batch
- [ ] Dry-fit assembly confirmed; all 13 tubes seat in pockets
- [ ] Cord binding complete; square-knot finish at both rail ends
- [ ] Final tuning: all 13 tubes ±5 cents; validation.csv updated
- [ ] Rails finished with Danish oil; tubes wiped with tung oil

---

## Notes

- This print packet covers Zanka as primary build. Use family-spec.csv for all 4 members.
- Tube lengths in this table are L_cut (include 3/16" trim allowance). Never cut shorter than L_calc.
- Story stick: mark all 13 tube lengths on a 1/4" × 1" × 18" MDF strip before cutting.
- Keep validation.csv open during the entire build and fill in measured_hz after each tuning pass.
- See resources.md §Provenance before writing any public-facing documentation.

---

*Packet v4.3 · tonykoop/siku-zampona · CC BY 4.0 · Heifer Zephyr*

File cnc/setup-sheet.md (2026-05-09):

# Siku (Zampoña) — CNC & Machining Setup Sheet

**Packet:** v4.3 · Date: 2026-05-08  
**Repo:** `siku-zampona`  
**Reference:** `jig-decision.md` (for fixture selection rationale), `cut-list.csv` (for tube lengths), `family-spec.csv` (for bore/OD parameters)

---

## Machine Assignments by Operation

| Op ID | Operation | Machine | Member(s) | Setup File |
|---|---|---|---|---|
| OP-01 | Frame rail pocket routing | CNC Router | All 4 | See §1 |
| OP-02 | Tube boring — shallow | Drill Press | Malta, Chili | See §2 |
| OP-03 | Tube boring — deep | Lathe | Zanka | See §3 |
| OP-04 | Tube boring — deep-bore | Headstock-driven | Toyo | See §4 |
| OP-05 | Sealing stand fabrication | Drill Press | All 4 | See §5 |
| OP-06 | Tube length marking | Story stick / Digital stop | All 4 | See §6 |
| OP-07 | Tuning trim | Miter Saw + File | All 4 | See §7 |

---

## §1 — CNC Router: Frame Rail Pocket Routing

### Purpose
Mill 13 semi-circular or rectangular tube pockets into each cherry/walnut frame rail. Two rails per instrument (top and bottom). Pockets hold tubes at correct spacing for binding.

### Machine Setup
- **Machine:** CNC router (router table with fence acceptable as fallback — see `jig-decision.md` Decision 3)
- **Spindle speed:** 18,000–22,000 RPM (up-cut spiral for cherry/walnut)
- **Feed rate:** 80–100 IPM (cherry), 60–80 IPM (walnut)
- **Plunge rate:** 20 IPM
- **Coolant:** Air blast only (no coolant on wood)

### Tooling

| Member | Pocket Width | Bit Type | Bit Diameter | Notes |
|---|---|---|---|---|
| Toyo | 0.995" | Up-cut spiral end mill | 1/2" | Two passes: rough + finish |
| Zanka | 0.816" | Up-cut spiral end mill | 3/8" or 1/2" | Pocket width = OD − 0.005" |
| Malta | 0.653" | Up-cut spiral end mill | 5/16" or 3/8" | |
| Chili | 0.488" | Up-cut spiral end mill | 1/4" | Minimum recommended bit for this depth |

**Pocket width formula:** `pocket_width = OD − 0.005"` (light interference fit before glue)

### Datum and Workholding
- **X datum:** Left end of rail, first pocket center at `OD/2` from end
- **Y datum:** Rail centerline (rail face up, pockets through the face)
- **Z datum (Z0):** Top surface of rail stock (use touch-off)
- **Workholding:** Double-sided tape + MDF spoilboard, or clamp tabs at rail ends

### Pocket Parameters by Member

| Member | OD (in) | Pocket Width (in) | Pocket Depth (in) | Pocket Length (in) | Pitch C-C (in) | First Center (in) | # Pockets |
|---|---|---|---|---|---|---|---|
| Toyo | 1.000 | 0.995 | 0.333 | 1.5 | 1.063 | 0.500 | 13 |
| Zanka | 0.821 | 0.816 | 0.274 | 1.5 | 0.884 | 0.411 | 13 |
| Malta | 0.658 | 0.653 | 0.219 | 1.5 | 0.721 | 0.329 | 13 |
| Chili | 0.493 | 0.488 | 0.164 | 1.5 | 0.556 | 0.247 | 13 |

**Pocket depth formula:** `pocket_depth = OD / 3` (tube sits 1/3 deep in rail)  
**Pocket pitch formula:** `pitch = OD + 1/16"` (1/16" clearance gap between tubes)

### G-code Notes (Vectric / Fusion 360)
- Use "Pocket" toolpath strategy, not Profile
- Set stock-to-leave = 0.005" on first pass for all members except Chili (cut to final in one pass due to small feature size)
- Climb milling preferred for final pass in cherry/walnut
- Post-process: Mach3 or equivalent; check safe Z height ≥ 1.5" above stock

### Release Checks (Before Running)
- [ ] Touch-off Z0 on fresh stock surface (not previous part)
- [ ] Verify pocket width against first pocket with calipers before continuing
- [ ] Confirm tube drops in with light resistance (not loose, not requiring force)
- [ ] Measure pitch on first two pockets; confirm C-C matches spec ±0.005"

---

## §2 — Drill Press: Tube Boring (Malta, Chili)

### Applicable Members
- Malta: bore ID 0.500", OD 0.658", wall 0.079"
- Chili: bore ID 0.375", OD 0.493", wall 0.059"

### Context
Only needed when sourcing hardwood blanks (maple, boxwood, bamboo without natural bore). Pre-bored PVC or bamboo tubes skip this operation entirely. Confirm bore before ordering.

### Setup
- **Machine:** Drill press with V-block fixture clamped to table
- **Bit type:** Brad-point or Forstner, matched to bore ID
- **Bit diameter:** 1/2" (Malta), 3/8" (Chili)
- **Speed:** 1,200–1,500 RPM (brad-point in hardwood); 800–1,000 RPM (Forstner)
- **Depth stop:** Set to tube length + 1/16" through clearance

### V-Block Fixture
- Commercial steel V-block or CNC-routed plywood V-block
- V-angle: 90° (centers round stock automatically)
- Clamp blank firmly; check alignment with a reference rod before drilling
- For tubes ≤ 6": single clamp mid-point. For tubes 6–11": two clamps, 1/4 and 3/4 positions

### Bore Sequence (per tube)
1. Center-punch both ends on lathe or drill press to mark bore centerline
2. Pilot drill: 1/8" through full length first (minimizes wander)
3. Step up in two stages: 1/4" → target bore diameter
4. Blow chips; verify bore with go/no-go gauge or caliper at 3 depths (entry, mid, exit)

### Release Checks
- [ ] Bore ID measures within +0.000" / −0.010" of target
- [ ] No taper (entry vs. exit within 0.005")
- [ ] No surface cracks at bore entry

---

## §3 — Lathe: Deep Bore Drilling (Zanka)

### Applicable Member
- Zanka: bore ID 0.625", OD 0.821", wall 0.098", tubes to 16.961" long

### Setup
- **Machine:** Metal or wood lathe with 4-jaw independent chuck
- **Chuck:** 4-jaw independent (required for repeatability)
- **Tailstock:** Drill chuck in tailstock
- **Bit:** 5/8" brad-point or reduced-shank twist drill (HSS)
- **Speed:** 600–800 RPM
- **Feed:** Hand-advance; pecking cycle every 1/2" travel to clear chips

### 4-Jaw Chuck Setup
1. Mount blank between centers first to check runout (≤0.003" acceptable)
2. Transfer to 4-jaw chuck; indicate bore centerline mark
3. Adjust until center-punch mark runs within 0.005" TIR

### Bore Sequence
1. Face both ends square on lathe
2. Center-drill tailstock end (A1 drill or combination drill)
3. Pilot drill: 1/4" × full depth
4. Step: 1/2" × full depth (two passes if tube > 12")
5. Final bore: 5/8" × full depth (use steady rest if available for tubes > 12")
6. De-burr both ends; verify bore with caliper at 3 points

### Release Checks
- [ ] Chuck alignment verified before each tube size change
- [ ] Bore ID: 0.615"–0.625" (tolerance −0.010"/+0.000")
- [ ] OD concentric with bore: check wall thickness at 4 compass points, variance ≤ 0.010"

---

## §4 — Headstock-Driven Deep Bore (Toyo)

### Applicable Member
- Toyo: bore ID 0.750", OD 1.000", wall 0.125", tubes to 22.646" long

### Context
At 22.6" depth with 3/4" bore, the drill wanders significantly if advanced from the tailstock in the conventional direction. The headstock-driven technique reverses the setup: the drill bit spins in the headstock Jacobs chuck, and the blank is advanced toward it by a carrier jig mounted in the tailstock. This eliminates drill flex entirely on long bores.

### Setup
- **Machine:** Lathe, 24"+ between-centers capacity
- **Headstock:** 3/4" bit in Jacobs chuck mounted to headstock spindle (run in forward)
- **Tailstock carrier:** Custom wooden or metal V-block carrier that accepts the tube blank; slides along ways
- **Bit:** 3/4" brad-point (HSS), shank ground to fit Jacobs chuck
- **Speed:** 400–600 RPM (lower than tailstock-advance due to blank length vibration risk)

### Carrier Jig Specification
- Material: 1-1/4" aluminum or hardwood block
- V-groove: 90°, depth = OD/2 (captures tube blank)
- Length: 4" (provides stable bearing surface)
- Clamping: Thumb screw + soft jaw (nylon or brass) to not mar tube
- Register: Index pin at tailstock quill → carrier centers on lathe axis

### Bore Sequence
1. Square both tube ends on lathe
2. Mark bore centerline on tailstock end with center punch
3. Mount bit in headstock chuck; set speed to 400 RPM
4. Load blank in carrier; align center punch to bit tip
5. Advance carrier 1/2" per peck; retract to clear chips after each peck
6. Watch for heat build-up (smoke → stop, cool, add paste wax to bit flutes)
7. Final 1" of advance: reduce speed to 300 RPM
8. Full retract; verify bore with 3/4" dowel gauge

### Release Checks
- [ ] Carrier jig alignment confirmed with 12" test rod before boring
- [ ] First tube bored is a sacrificial blank (knot-free scrap, same OD)
- [ ] Bore ID: 0.740"–0.750" (tolerance −0.010"/+0.000")
- [ ] Wall thickness check at 4 points, variance ≤ 0.015"
- [ ] No breakthrough (check by illuminating with flashlight at entry end)

---

## §5 — Drill Press: Sealing Stand Fabrication

### Purpose
Build 4 plywood stands (one per family member) to hold tubes vertically during beeswax plug curing.

### Stand Specifications

| Member | Stand Size | Hole Diam. | # Holes | Hole Spacing | Material |
|---|---|---|---|---|---|
| Toyo | 6" × 14" | 1.010" | 13 | 1.063" C-C | 3/4" plywood |
| Zanka | 5" × 12" | 0.831" | 13 | 0.884" C-C | 3/4" plywood |
| Malta | 4" × 10" | 0.668" | 13 | 0.721" C-C | 1/2" plywood |
| Chili | 3" × 8" | 0.503" | 13 | 0.556" C-C | 1/2" plywood |

**Hole diameter** = tube OD + 0.010" (light clearance, tube must stand plumb without tipping)

### Drill Press Setup
- Layout holes with marking gauge; verify first spacing before drilling all 13
- Forstner bits preferred (flat-bottom hole is not necessary but prevents tube wobble)
- Back with sacrificial scrap to prevent tearout on exit
- Label each stand with member ID and hole diameter in permanent marker

### Release Checks
- [ ] Test tube stands plumb in first hole (leaning > 2° → enlarge hole 0.005")
- [ ] All 13 tubes fit without binding

---

## §6 — Tube Length Marking

### Bamboo Builds (Story Stick Method)
- **Story stick material:** 1/4" × 1" MDF strip, 25" long
- **Per family member:** one stick (do not combine members on one stick)
- Mark tube positions from the closed (bottom) end
- Label each mark: e.g., "Z-A1 16.961" G3" (member-rankTube length note)
- Score marks with marking knife; over-mark with fine Sharpie
- Store sticks with the packet (laminate if possible)

### PVC Builds (Digital Stop Method)
- Set miter saw digital stop or digital caliper fence to target L_cut value
- Sequence: longest → shortest (one fence re-set per tube rather than re-set per cut)
- Call out each measurement before cutting; second operator confirms
- After each cut: measure with calipers; record actual in validation.csv

### Common Release Checks (Both Methods)
- [ ] Verify story stick / stop against independent tape measure before first cut
- [ ] First tube of each member cut 1/32" long; measure, then bring to final length
- [ ] No cuts made without label visible on tube

---

## §7 — Miter Saw + File: Tuning Trim

### Context
After first-pass tuning, tubes that measure flat need material removed from the open (top) end to raise pitch. This is the only irreversible operation in the build — cut less than you think you need.

### Protocol
1. Play tube into chromatic tuner; record cents error in validation.csv
2. Compute trim length: `ΔL ≈ cents_flat × (L_tube / 1200)` (approximate; empirical trim is more accurate)
3. For trim > 1/16": mark with blue tape on tube; cut at miter saw (80T fine-tooth blade)
4. For trim ≤ 1/16": use fine file + engineer's square; remove material in 2–3 passes
5. After each pass: sand end flat on 320-grit paper on glass; re-measure tuning
6. Re-record in validation.csv; circle measurements to distinguish retrim entries

### Miter Saw Setup
- Fence set square; verify with engineer's square before first cut
- 80-tooth ATB blade (or higher); clean teeth before use
- Light downfeed pressure; let the blade do the work
- For bamboo: back-cut method (score from two sides) to prevent node splitting

### Release Checks
- [ ] Each trimmed tube: final measurement within ±5 cents of target
- [ ] No tube trimmed more than 3/16" below L_calc (over-trimmed → scrap or Chili-prototype downgrade)
- [ ] validation.csv updated same session as trim

---

## Datum Reference Summary

| Machine | X0 | Y0 | Z0 |
|---|---|---|---|
| CNC Router (rails) | Left rail end | Rail centerline | Top surface of stock |
| Drill Press (V-block) | V-block center | Table surface | Drill tip at touch-off |
| Lathe (Zanka) | Chuck face | Spindle centerline | — |
| Lathe (Toyo headstock) | Headstock chuck face | Spindle centerline | — |
| Miter Saw | Fence face | Blade centerline | Table surface |

---

## Pre-Run Checklist (All Operations)

- [ ] Verify `family-spec.csv` is open and correct member row is active
- [ ] Tube OD measured with calipers within 24 hours of operation (bamboo varies with humidity)
- [ ] Appropriate PPE: dust mask (wood routing/drilling), safety glasses (all operations)
- [ ] Chip/dust clearance: air blast available; not just shop vac (chips pack in deep bores)
- [ ] First piece is always a test piece — measure before committing production stock

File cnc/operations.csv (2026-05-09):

op_id | op_name | machine | member | setup_ref | sequence | tool | tool_diameter_in | rpm_min | rpm_max | feed_ipm | plunge_ipm | depth_of_cut_in | pocket_width_in | pocket_depth_in | pocket_pitch_in | num_features | datum_x | datum_y | datum_z | release_check_1 | release_check_2 | release_check_3 | notes
OP-01-TY | Frame rail pocket routing — Toyo | CNC Router | Toyo | cnc/setup-sheet.md §1 | 1 | Up-cut spiral end mill | 0.500 | 18000 | 22000 | 80 | 20 | 0.333 | 0.995 | 0.333 | 1.063 | 13 | Left rail end | Rail centerline | Top of stock | Pocket width ±0.003" on first pocket | Pitch C-C ±0.005" first two pockets | Tube drops in light fit | Two-pass: rough 0.005" stock-to-leave then finish
OP-01-ZK | Frame rail pocket routing — Zanka | CNC Router | Zanka | cnc/setup-sheet.md §1 | 1 | Up-cut spiral end mill | 0.375 | 18000 | 22000 | 80 | 20 | 0.274 | 0.816 | 0.274 | 0.884 | 13 | Left rail end | Rail centerline | Top of stock | Pocket width ±0.003" on first pocket | Pitch C-C ±0.005" first two pockets | Tube drops in light fit | Two-pass preferred; one-pass acceptable on sharp bit
OP-01-MT | Frame rail pocket routing — Malta | CNC Router | Malta | cnc/setup-sheet.md §1 | 1 | Up-cut spiral end mill | 0.375 | 18000 | 22000 | 80 | 20 | 0.219 | 0.653 | 0.219 | 0.721 | 13 | Left rail end | Rail centerline | Top of stock | Pocket width ±0.003" on first pocket | Pitch C-C ±0.005" first two pockets | Tube drops in light fit | 3/8" bit leaves small flat at pocket corners — acceptable
OP-01-CH | Frame rail pocket routing — Chili | CNC Router | Chili | cnc/setup-sheet.md §1 | 1 | Up-cut spiral end mill | 0.250 | 18000 | 22000 | 60 | 15 | 0.164 | 0.488 | 0.164 | 0.556 | 13 | Left rail end | Rail centerline | Top of stock | Pocket width ±0.003" on first pocket | Pitch C-C ±0.005" first two pockets | Tube drops in light fit | Single pass; 1/4" bit at minimum recommended diameter — use sharp bit only
OP-02-MT | Tube boring — Malta | Drill Press + V-block | Malta | cnc/setup-sheet.md §2 | 2 | Brad-point or Forstner | 0.500 | 1200 | 1500 |  |  | 0.500 |  |  |  |  | V-block center | Table surface | Drill tip touch-off | Bore ID 0.490–0.500" at 3 depths | No taper > 0.005" entry-to-exit | No surface cracks at entry | Pilot at 1/8" then 1/4" then 1/2"; skip if PVC pre-bored
OP-02-CH | Tube boring — Chili | Drill Press + V-block | Chili | cnc/setup-sheet.md §2 | 2 | Brad-point or Forstner | 0.375 | 1200 | 1500 |  |  | 0.375 |  |  |  |  | V-block center | Table surface | Drill tip touch-off | Bore ID 0.365–0.375" at 3 depths | No taper > 0.005" entry-to-exit | No surface cracks at entry | Pilot at 1/8" then 1/4" then 3/8"; skip if PVC pre-bored
OP-03-ZK | Tube boring — Zanka (lathe) | Lathe 4-jaw | Zanka | cnc/setup-sheet.md §3 | 2 | 5/8" brad-point or twist drill HSS | 0.625 | 600 | 800 |  |  | 0.625 |  |  |  |  | Chuck face | Spindle centerline |  | Bore ID 0.615–0.625" at 3 points | Wall thickness variance ≤ 0.010" at 4 compass points | OD runout ≤ 0.003" TIR before boring | Peck cycle every 1/2"; steady rest for tubes > 12"; skip if PVC pre-bored
OP-04-TY | Tube boring — Toyo (headstock deep bore) | Lathe headstock-driven | Toyo | cnc/setup-sheet.md §4 | 2 | 3/4" brad-point HSS in headstock chuck | 0.750 | 400 | 600 |  |  | 0.750 |  |  |  |  | Headstock chuck face | Spindle centerline |  | First piece is sacrificial blank | Bore ID 0.740–0.750" at 3 points | Wall thickness variance ≤ 0.015" at 4 compass points | Tailstock carrier jig required; smoke → stop and cool; skip if PVC pre-bored
OP-05-TY | Sealing stand drilling — Toyo | Drill Press | Toyo | cnc/setup-sheet.md §5 | 3 | Forstner or spade | 1.010 | 800 | 1000 |  |  | 0.750 |  |  | 1.063 | 13 | Layout from end | Table surface | Drill tip touch-off | First hole: tube stands plumb (≤2° lean) | All 13 holes: tube fits without binding | Stand labeled with member ID | 3/4" plywood 6"×14"; back with sacrificial scrap
OP-05-ZK | Sealing stand drilling — Zanka | Drill Press | Zanka | cnc/setup-sheet.md §5 | 3 | Forstner or spade | 0.831 | 800 | 1000 |  |  | 0.750 |  |  | 0.884 | 13 | Layout from end | Table surface | Drill tip touch-off | First hole: tube stands plumb (≤2° lean) | All 13 holes: tube fits without binding | Stand labeled with member ID | 3/4" plywood 5"×12"
OP-05-MT | Sealing stand drilling — Malta | Drill Press | Malta | cnc/setup-sheet.md §5 | 3 | Forstner or spade | 0.668 | 1000 | 1200 |  |  | 0.500 |  |  | 0.721 | 13 | Layout from end | Table surface | Drill tip touch-off | First hole: tube stands plumb (≤2° lean) | All 13 holes: tube fits without binding | Stand labeled with member ID | 1/2" plywood 4"×10"
OP-05-CH | Sealing stand drilling — Chili | Drill Press | Chili | cnc/setup-sheet.md §5 | 3 | Brad-point or spade | 0.503 | 1200 | 1500 |  |  | 0.375 |  |  | 0.556 | 13 | Layout from end | Table surface | Drill tip touch-off | First hole: tube stands plumb (≤2° lean) | All 13 holes: tube fits without binding | Stand labeled with member ID | 1/2" plywood 3"×8"
OP-06-TY | Tube length marking — Toyo | Story stick / miter saw | Toyo | cnc/setup-sheet.md §6 | 4 | Story stick (MDF 1/4"×1"×25") |  |  |  |  |  |  |  |  |  |  |  |  | Story stick matches cut-list.csv before marking | All 13 marks labeled with tube ID and note name | First tube cut 1/32" long and measured before batch cut | Bamboo: story stick method; PVC: digital stop
OP-06-ZK | Tube length marking — Zanka | Story stick / miter saw | Zanka | cnc/setup-sheet.md §6 | 4 | Story stick (MDF 1/4"×1"×25") |  |  |  |  |  |  |  |  |  |  |  |  | Story stick matches cut-list.csv before marking | All 13 marks labeled with tube ID and note name | First tube cut 1/32" long and measured before batch cut | Bamboo: story stick method; PVC: digital stop
OP-06-MT | Tube length marking — Malta | Story stick / miter saw | Malta | cnc/setup-sheet.md §6 | 4 | Story stick (MDF 1/4"×1"×13") |  |  |  |  |  |  |  |  |  |  |  |  | Story stick matches cut-list.csv before marking | All 13 marks labeled with tube ID and note name | First tube cut 1/32" long and measured before batch cut
OP-06-CH | Tube length marking — Chili | Story stick / miter saw | Chili | cnc/setup-sheet.md §6 | 4 | Story stick (MDF 1/4"×1"×9") |  |  |  |  |  |  |  |  |  |  |  |  | Story stick matches cut-list.csv before marking | All 13 marks labeled with tube ID and note name | First tube cut 1/32" long and measured before batch cut | Chili Arka-7 (F#6) is borderline — see risks.md AC-04; consider omitting
OP-07-TY | Tuning trim — Toyo | Miter saw + file | Toyo | cnc/setup-sheet.md §7 | 5 | 80T ATB blade (rough) + fine mill file (final) |  |  |  |  |  |  |  |  |  |  |  |  | All trims recorded in validation.csv same session | No tube trimmed > 3/16" below L_calc | Final measurement ±5 cents of target | Compute trim from cents_flat before cutting; empirical trim is more accurate than formula
OP-07-ZK | Tuning trim — Zanka | Miter saw + file | Zanka | cnc/setup-sheet.md §7 | 5 | 80T ATB blade (rough) + fine mill file (final) |  |  |  |  |  |  |  |  |  |  |  |  | All trims recorded in validation.csv same session | No tube trimmed > 3/16" below L_calc | Final measurement ±5 cents of target | Primary melodic voice — tune Zanka first
OP-07-MT | Tuning trim — Malta | Miter saw + file | Malta | cnc/setup-sheet.md §7 | 5 | 80T ATB blade (rough) + fine mill file (final) |  |  |  |  |  |  |  |  |  |  |  |  | All trims recorded in validation.csv same session | No tube trimmed > 3/16" below L_calc | Final measurement ±5 cents of target
OP-07-CH | Tuning trim — Chili | Miter saw + file | Chili | cnc/setup-sheet.md §7 | 5 | 80T ATB blade (rough) + fine mill file (final) |  |  |  |  |  |  |  |  |  |  |  |  | All trims recorded in validation.csv same session | No tube trimmed > 3/16" below L_calc | Final measurement ±5 cents of target | Chili tubes short — use file-only method; miter saw overkill and higher over-cut risk

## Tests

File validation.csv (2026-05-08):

check_id | member | tube | note | target_hz | predicted_L_calc_in | predicted_L_cut_in | bore_id_in | plug_type | measured_L_in | measured_hz | cents_error | tolerance_cents | environment_temp_F | environment_RH_pct | result | action | date_measured | notes
VAL-T-A1 | SKZ-TOYO | Arka 1 | D3 | 146.83 | 22.459 | 22.646 | 0.750 | TBD |  |  |  | ±10 | 68 | 45 |  | TBD |  | Longest tube — verify straight grain and consistent bore before cutting
VAL-T-A2 | SKZ-TOYO | Arka 2 | F#3 | 185.00 | 17.699 | 17.886 | 0.750 | TBD |  |  |  | ±10 | 68 | 45 |  | TBD
VAL-T-A3 | SKZ-TOYO | Arka 3 | A3 | 220.00 | 14.785 | 14.973 | 0.750 | TBD |  |  |  | ±10 | 68 | 45 |  | TBD
VAL-T-A4 | SKZ-TOYO | Arka 4 | C4 | 261.63 | 12.335 | 12.522 | 0.750 | TBD |  |  |  | ±10 | 68 | 45 |  | TBD
VAL-T-A5 | SKZ-TOYO | Arka 5 | E4 | 329.63 | 9.663 | 9.851 | 0.750 | TBD |  |  |  | ±5 | 68 | 45 |  | TBD
VAL-T-A6 | SKZ-TOYO | Arka 6 | G4 | 392.00 | 8.028 | 8.215 | 0.750 | TBD |  |  |  | ±5 | 68 | 45 |  | TBD
VAL-T-A7 | SKZ-TOYO | Arka 7 | B4 | 493.88 | 6.245 | 6.432 | 0.750 | TBD |  |  |  | ±5 | 68 | 45 |  | TBD
VAL-T-I1 | SKZ-TOYO | Ira 1 | E3 | 164.81 | 19.942 | 20.129 | 0.750 | TBD |  |  |  | ±10 | 68 | 45 |  | TBD
VAL-T-I2 | SKZ-TOYO | Ira 2 | G3 | 196.00 | 16.671 | 16.858 | 0.750 | TBD |  |  |  | ±10 | 68 | 45 |  | TBD
VAL-T-I3 | SKZ-TOYO | Ira 3 | B3 | 246.94 | 13.105 | 13.292 | 0.750 | TBD |  |  |  | ±10 | 68 | 45 |  | TBD
VAL-T-I4 | SKZ-TOYO | Ira 4 | D4 | 293.66 | 10.922 | 11.109 | 0.750 | TBD |  |  |  | ±10 | 68 | 45 |  | TBD
VAL-T-I5 | SKZ-TOYO | Ira 5 | F#4 | 369.99 | 8.542 | 8.729 | 0.750 | TBD |  |  |  | ±5 | 68 | 45 |  | TBD
VAL-T-I6 | SKZ-TOYO | Ira 6 | A4 | 440.00 | 7.085 | 7.272 | 0.750 | TBD |  |  |  | ±5 | 68 | 45 |  | TBD
VAL-Z-A1 | SKZ-ZANKA | Arka 1 | G3 | 196.00 | 16.773 | 16.961 | 0.625 | TBD |  |  |  | ±10 | 68 | 45 |  | TBD |  | Primary Zanka melodic tube
VAL-Z-A2 | SKZ-ZANKA | Arka 2 | B3 | 246.94 | 13.207 | 13.395 | 0.625 | TBD |  |  |  | ±10 | 68 | 45 |  | TBD
VAL-Z-A3 | SKZ-ZANKA | Arka 3 | D4 | 293.66 | 11.024 | 11.212 | 0.625 | TBD |  |  |  | ±10 | 68 | 45 |  | TBD
VAL-Z-A4 | SKZ-ZANKA | Arka 4 | F4 | 349.23 | 9.189 | 9.376 | 0.625 | TBD |  |  |  | ±5 | 68 | 45 |  | TBD
VAL-Z-A5 | SKZ-ZANKA | Arka 5 | A4 | 440.00 | 7.188 | 7.375 | 0.625 | TBD |  |  |  | ±5 | 68 | 45 |  | TBD |  | Primary reference — A4=440 Hz sanity check
VAL-Z-A6 | SKZ-ZANKA | Arka 6 | C5 | 523.25 | 5.962 | 6.150 | 0.625 | TBD |  |  |  | ±5 | 68 | 45 |  | TBD
VAL-Z-A7 | SKZ-ZANKA | Arka 7 | E5 | 659.26 | 4.627 | 4.814 | 0.625 | TBD |  |  |  | ±5 | 68 | 45 |  | TBD
VAL-Z-I1 | SKZ-ZANKA | Ira 1 | A3 | 220.00 | 14.888 | 15.075 | 0.625 | TBD |  |  |  | ±10 | 68 | 45 |  | TBD
VAL-Z-I2 | SKZ-ZANKA | Ira 2 | C4 | 261.63 | 12.437 | 12.625 | 0.625 | TBD |  |  |  | ±10 | 68 | 45 |  | TBD
VAL-Z-I3 | SKZ-ZANKA | Ira 3 | E4 | 329.63 | 9.766 | 9.953 | 0.625 | TBD |  |  |  | ±10 | 68 | 45 |  | TBD
VAL-Z-I4 | SKZ-ZANKA | Ira 4 | G4 | 392.00 | 8.130 | 8.318 | 0.625 | TBD |  |  |  | ±5 | 68 | 45 |  | TBD
VAL-Z-I5 | SKZ-ZANKA | Ira 5 | B4 | 493.88 | 6.347 | 6.535 | 0.625 | TBD |  |  |  | ±5 | 68 | 45 |  | TBD
VAL-Z-I6 | SKZ-ZANKA | Ira 6 | D5 | 587.33 | 5.256 | 5.443 | 0.625 | TBD |  |  |  | ±5 | 68 | 45 |  | TBD
VAL-M-A1 | SKZ-MALTA | Arka 1 | D4 | 293.66 | 11.127 | 11.314 | 0.500 | TBD |  |  |  | ±10 | 68 | 45 |  | TBD
VAL-M-A2 | SKZ-MALTA | Arka 2 | F#4 | 369.99 | 8.747 | 8.934 | 0.500 | TBD |  |  |  | ±5 | 68 | 45 |  | TBD
VAL-M-A3 | SKZ-MALTA | Arka 3 | A4 | 440.00 | 7.290 | 7.478 | 0.500 | TBD |  |  |  | ±5 | 68 | 45 |  | TBD |  | A4 sanity check
VAL-M-A4 | SKZ-MALTA | Arka 4 | C5 | 523.25 | 6.065 | 6.252 | 0.500 | TBD |  |  |  | ±5 | 68 | 45 |  | TBD
VAL-M-A5 | SKZ-MALTA | Arka 5 | E5 | 659.26 | 4.729 | 4.917 | 0.500 | TBD |  |  |  | ±5 | 68 | 45 |  | TBD
VAL-M-A6 | SKZ-MALTA | Arka 6 | G5 | 783.99 | 3.911 | 4.099 | 0.500 | TBD |  |  |  | ±5 | 68 | 45 |  | TBD
VAL-M-A7 | SKZ-MALTA | Arka 7 | B5 | 987.77 | 3.020 | 3.207 | 0.500 | TBD |  |  |  | ±5 | 68 | 45 |  | TBD |  | Shortest Malta tube — careful trim
VAL-M-I1 | SKZ-MALTA | Ira 1 | E4 | 329.63 | 9.868 | 10.056 | 0.500 | TBD |  |  |  | ±10 | 68 | 45 |  | TBD
VAL-M-I2 | SKZ-MALTA | Ira 2 | G4 | 392.00 | 8.233 | 8.420 | 0.500 | TBD |  |  |  | ±5 | 68 | 45 |  | TBD
VAL-M-I3 | SKZ-MALTA | Ira 3 | B4 | 493.88 | 6.450 | 6.637 | 0.500 | TBD |  |  |  | ±5 | 68 | 45 |  | TBD
VAL-M-I4 | SKZ-MALTA | Ira 4 | D5 | 587.33 | 5.358 | 5.546 | 0.500 | TBD |  |  |  | ±5 | 68 | 45 |  | TBD
VAL-M-I5 | SKZ-MALTA | Ira 5 | F#5 | 739.99 | 4.168 | 4.356 | 0.500 | TBD |  |  |  | ±5 | 68 | 45 |  | TBD
VAL-M-I6 | SKZ-MALTA | Ira 6 | A5 | 880.00 | 3.440 | 3.627 | 0.500 | TBD |  |  |  | ±5 | 68 | 45 |  | TBD
VAL-C-A1 | SKZ-CHILI | Arka 1 | A4 | 440.00 | 7.393 | 7.580 | 0.375 | TBD |  |  |  | ±5 | 68 | 45 |  | TBD |  | A4 sanity check for Chili
VAL-C-A2 | SKZ-CHILI | Arka 2 | C#5 | 554.37 | 5.804 | 5.991 | 0.375 | TBD |  |  |  | ±5 | 68 | 45 |  | TBD
VAL-C-A3 | SKZ-CHILI | Arka 3 | E5 | 659.26 | 4.832 | 5.019 | 0.375 | TBD |  |  |  | ±5 | 68 | 45 |  | TBD
VAL-C-A4 | SKZ-CHILI | Arka 4 | G5 | 783.99 | 4.014 | 4.201 | 0.375 | TBD |  |  |  | ±5 | 68 | 45 |  | TBD
VAL-C-A5 | SKZ-CHILI | Arka 5 | B5 | 987.77 | 3.122 | 3.310 | 0.375 | TBD |  |  |  | ±5 | 68 | 45 |  | TBD
VAL-C-A6 | SKZ-CHILI | Arka 6 | D6 | 1174.66 | 2.577 | 2.764 | 0.375 | TBD |  |  |  | ±5 | 68 | 45 |  | TBD |  | Short — check carefully
VAL-C-A7 | SKZ-CHILI | Arka 7 | F#6 | 1479.98 | 1.982 | 2.169 | 0.375 | TBD |  |  |  | ±10 | 68 | 45 |  | TBD |  | ⚠ Prototype FIRST — 50mm limit for playability (see risks.md AC-04)
VAL-C-I1 | SKZ-CHILI | Ira 1 | B4 | 493.88 | 6.552 | 6.740 | 0.375 | TBD |  |  |  | ±5 | 68 | 45 |  | TBD
VAL-C-I2 | SKZ-CHILI | Ira 2 | D5 | 587.33 | 5.461 | 5.648 | 0.375 | TBD |  |  |  | ±5 | 68 | 45 |  | TBD
VAL-C-I3 | SKZ-CHILI | Ira 3 | F#5 | 739.99 | 4.271 | 4.458 | 0.375 | TBD |  |  |  | ±5 | 68 | 45 |  | TBD
VAL-C-I4 | SKZ-CHILI | Ira 4 | A5 | 880.00 | 3.542 | 3.730 | 0.375 | TBD |  |  |  | ±5 | 68 | 45 |  | TBD
VAL-C-I5 | SKZ-CHILI | Ira 5 | C#6 | 1108.73 | 2.748 | 2.936 | 0.375 | TBD |  |  |  | ±5 | 68 | 45 |  | TBD
VAL-C-I6 | SKZ-CHILI | Ira 6 | E6 | 1318.51 | 2.262 | 2.450 | 0.375 | TBD |  |  |  | ±5 | 68 | 45 |  | TBD
VAL-DIM-01 | All | Frame width check — Toyo |  |  |  |  |  |  |  |  |  |  |  |  | TBD |  | Measure actual assembled frame width vs 13.750-in spec
VAL-DIM-02 | All | Frame width check — Zanka |  |  |  |  |  |  |  |  |  |  |  |  | TBD |  | Measure actual assembled vs 11.423-in spec
VAL-DIM-03 | All | Frame width check — Malta |  |  |  |  |  |  |  |  |  |  |  |  | TBD |  | Measure actual assembled vs 9.304-in spec
VAL-DIM-04 | All | Frame width check — Chili |  |  |  |  |  |  |  |  |  |  |  |  | TBD |  | Measure actual assembled vs 7.159-in spec
VAL-BORE-01 | All | Bore ID check — Toyo sample |  |  | 0.750 |  |  |  |  |  |  |  |  |  | TBD |  | Caliper-verify bore ID on 3 random Toyo tubes before computing lengths
VAL-BORE-02 | All | Bore ID check — Zanka sample |  |  | 0.625 |  |  |  |  |  |  |  |  |  | TBD
VAL-BORE-03 | All | Bore ID check — Malta sample |  |  | 0.500 |  |  |  |  |  |  |  |  |  | TBD
VAL-BORE-04 | All | Bore ID check — Chili sample |  |  | 0.375 |  |  |  |  |  |  |  |  |  | TBD
VAL-PHYS-01 | All | A4 = 440 Hz sanity check — Zanka Arka5 | SKZ-ZANKA | 440.00 | 7.188 | 7.375 | 0.625 |  |  |  |  | ±2 | 68 | 45 |  | TBD |  | Primary physics sanity check — use Korg CA-1

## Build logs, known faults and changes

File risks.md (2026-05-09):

# Siku (Zampoña) — Risks

**Instrument:** Siku / Zampoña (Andean Panpipe Family)  
**Packet:** v4.3 · Date: 2026-05-08  
**Format:** Risk ID · Category · Description · Severity (H/M/L) · Likelihood (H/M/L) · Verification test

---

## Acoustic Risks

### AC-01 — Bore Diameter Variance in Bamboo

**Risk:** Natural bamboo bore varies ±0.030"–0.050" along the tube length. If the bore near the open end differs from the bore used in length calculation, the effective end correction shifts and the tube plays out of tune.  
**Severity:** H · **Likelihood:** H (bamboo is always variable)  
**Mitigation:** Measure bore ID at the blow end of each tube with calipers. Recalculate L_physical with the actual measured bore before cutting. Record in `validation.csv` `VAL-BORE-01` through `VAL-BORE-04`.  
**Test:** Measure 3 random tubes per size class before cutting any tube. If variance > ±0.020", recalculate all cut lengths with the measured bore.

---

### AC-02 — Temperature / Humidity Tuning Drift

**Risk:** Speed of sound changes with temperature. A 10°F shift ≈ 1.8 cents. A bamboo instrument stored outdoors in Andean conditions can shift by 15–20 cents from indoor calibration.  
**Severity:** M · **Likelihood:** M  
**Mitigation:** Final tuning trim should be performed at the intended playing temperature. Note shop temperature and RH in every `validation.csv` row.  
**Test:** Re-measure a reference tube (Zanka Arka 5, A4) at two temperatures: shop temp and 55°F. If difference > 5 cents, add a note to the README about re-tuning before performance.

---

### AC-03 — Cork Plug Acoustic Penalty

**Risk:** If cork plugs are used instead of beeswax or bamboo nodes, the less-reflective closed end shifts pitch flat by 5–10 cents (estimated). This affects all tubes equally but means the design table lengths will not be accurate for cork-plugged instruments.  
**Severity:** M · **Likelihood:** L (if builder follows beeswax recommendation)  
**Mitigation:** Use beeswax or bamboo node for closed end. If cork is used, add ~1/16" to each tube length and re-verify with tuner.  
**Test:** Build one Zanka Arka 5 (A4) with a cork plug and measure. Compare to beeswax plug version. Document the delta and add it to `design.md` Section 4.4 if significant.

---

### AC-04 — Chili Arka 7 (F#6) Below Practical Embouchure Length

**Risk:** The Chili Arka 7 (F#6 at 1479 Hz) calculates to 1.982" physical length (50 mm). Traditional panpipe makers consider ~50 mm the practical minimum; many builder references suggest the lowest limit for reliable tone production is 45–60 mm. Tubes this short require very precise embouchure angle and produce thin, breathy tone with embouchure sensitivity 2× higher than longer tubes.  
**Severity:** H · **Likelihood:** M  
**Mitigation:** Build and prototype this tube alone before committing to a full Chili build. If unplayable, omit Arka 7 (11-tube Chili) or substitute a half-step flat at a playable length.  
**Test:** Cut and seal a single F#6 Chili tube at 2.169" (L_cut). Attempt to produce a clear tone. If consistent tone requires extreme embouchure control or is unreliable, flag as "omit" and update `family-spec.csv` notes.

---

### AC-05 — End Correction Model Accuracy

**Risk:** The end correction `ΔL = 0.82 × bore_ID` is a dimensional approximation (empirically derived). The standard physics value is `ΔL = 0.6 × r` (unflanged) = `0.3 × d`, or `0.85 × r` (flanged) = `0.425 × d`. Tony's convention uses `0.82 × d` (diameter), which is ~2× the physics value. This likely bundles empirical embouchure effects; its accuracy for this instrument family has not been validated.  
**Severity:** M · **Likelihood:** M  
**Mitigation:** The 3/16" trim allowance covers this uncertainty. After first prototype, measure the actual trim removed from each tube and compute the actual effective end correction. Add to `design.md` as an empirical correction once ≥7 data points are available.  
**Test:** For the first Zanka build, record `L_cut` (before trim) and `L_final` (after trim) for all 13 tubes. Compute actual `ΔL_actual = L_calc - L_final` and compare to `0.82 × bore = 0.5125"`. If mean deviation > 0.100", update the end-correction coefficient in the design table.

---

## Structural Risks

### ST-01 — Frame Rail Pocket Splitting Under Cord Tension

**Risk:** CNC tube pockets reduce the rail cross-section between pockets to `gap / 2 = 1/32"` of solid wood. Under cord binding tension, inter-pocket walls in cherry may split along the grain.  
**Severity:** H · **Likelihood:** L (cherry is tough; cord tension is low)  
**Mitigation:** Ensure pocket depth ≤ 1/3 OD (not 1/2). Keep cord tension moderate — decorative binding, not structural clamp. If pocket walls are undersized, add a 1/8" solid wood strip glued between every 3rd pocket.  
**Test:** After glue-up, inspect rail under 10× magnification at each inter-pocket wall. No hairline cracks acceptable. If present, apply thin CA glue as stabilizer before cord wrapping.

---

### ST-02 — Toyo Arka 1 (22.6") Long-Tube Sag

**Risk:** A 22.6" bamboo tube with 1.0" OD and 0.125" wall is relatively slender. If the tube is not fully supported along its length, the weight of the tube itself can deflect it out of the pocket under playing tension. This can cause a buzzing rattle.  
**Severity:** M · **Likelihood:** L  
**Mitigation:** Use full-depth glue-bond at both rails for Toyo Arka 1 specifically. Add a third intermediate cord wrap at the midpoint of the longest 3 tubes.  
**Test:** Gently tap the assembled Toyo arka along each tube. No buzzing or rattle should be heard. Confirm tube is firmly seated in both rail pockets.

---

### ST-03 — Beeswax Plug Creep at Elevated Temperature

**Risk:** Beeswax melts at ~145°F. In direct sunlight inside a car, instrument temperature can exceed 120°F. Wax may soften, allowing the plug to migrate toward the open end under gravity, effectively lengthening the air column and flattening pitch.  
**Severity:** M · **Likelihood:** M (depends on storage habits)  
**Mitigation:** Store instrument in a case; never in direct sunlight. Alternatively, use wood dowel plugs for instruments intended for outdoor/travel use.  
**Test:** Place a wax-plugged tube in a 130°F oven for 30 minutes. Measure plug position before and after. If plug has migrated more than 1/16", switch to wood dowel plugs.

---

## Ergonomic Risks

### ER-01 — Toyo Bass Arm Span at 13.75" Frame Width

**Risk:** The Toyo frame is 13.75" wide with all 13 tubes. In traditional Andean play, one player holds only 7 tubes (the arka rank) = 7 × 1.000" + 6 × 0.063" = 7.375" + 0.375" = 7.75" wide arka rank. That is fine. But if someone attempts to hold the full 13-tube Toyo as a single instrument, 13.75" exceeds comfortable one-hand span for most adults.  
**Severity:** L (by design, split into arka + ira)  
**Likelihood:** L  
**Mitigation:** Document clearly in README and assembly manual that this is a split instrument — arka and ira are separate ranks. Do not bind all 13 Toyo tubes into one frame unless intentionally making a "concert" single-player Toyo.  
**Test:** Build arka (7-tube) and ira (6-tube) as separate bound ranks. Confirm each fits comfortably in one hand.

---

### ER-02 — Chili High-Register Breath Pressure Requirements

**Risk:** Very short soprano tubes (Ira 6, E6 = 2.262") require significantly higher breath velocity than bass tubes to excite a tone. A player switching rapidly between Toyo and Chili in an ensemble may struggle with breath pressure transitions.  
**Severity:** L · **Likelihood:** M (pedagogical concern, not build failure)  
**Mitigation:** Document in README that the 4-size ensemble is intended as distinct instruments for different players, not typically played simultaneously by one person. Provide an embouchure guide in the learn-to-play notes.  
**Test:** Play all 13 tubes of the Chili from Arka 1 to Ira 6 in a single breath sequence. All tubes should produce a clear tone with consistent embouchure pressure adjustment. If Ira 6 or Arka 7 cannot be reliably played, flag for omission.

---

## Supply Chain Risks

### SC-01 — Andean Bamboo Cañahueca Difficult to Source Outside South America

**Risk:** Traditional cañahueca bamboo (*Guadua chacoensis*) may not be available from US suppliers in the specified bore diameters. Most US bamboo suppliers stock Asian bamboo species (Moso, Tonkin) which have different wall-to-bore ratios.  
**Severity:** M · **Likelihood:** H  
**Mitigation:** PVC Schedule 40 is an adequate substitute for all size classes. Tonkin arrow shaft bamboo is acceptable for Malta and Chili. See `sourcing.csv` for verified alternatives. Note the bore diameter difference if substituting PVC and recalculate cut lengths.  
**Test:** Verify at least one alternative supplier can ship within 2 weeks before starting build. If no bamboo available in spec, proceed with PVC prototype and note in README.

---

### SC-02 — Cherry Frame Stock Grain Quality

**Risk:** Cheap cherry lumber may have wavy grain or short grain that crosses the tube pocket walls, causing split-out during pocket routing.  
**Severity:** M · **Likelihood:** L  
**Mitigation:** Inspect cherry stock for straight grain running parallel to rail length. Use FAS-grade lumber.  
**Test:** Pre-route a test pocket in the leftover cherry cutoff before routing the actual rail. Inspect for tearout. If tearout is severe, switch to walnut (tighter grain) or increase bit sharpness/reduce feed rate.

---

## Fit and Finish Risks

### FF-01 — PVC / Bamboo OD Inconsistency Causing Loose Pockets

**Risk:** If the tube OD is smaller than the CNC pocket width, the tube will be loose in the pocket and may rattle or rotate.  
**Severity:** M · **Likelihood:** M (especially if mixing tube sources)  
**Mitigation:** Measure actual OD of every tube with calipers. Set CNC pocket width to the measured mean OD − 0.005" for a light press fit.  
**Test:** Dry-fit all tubes before gluing. Each tube should require light finger pressure to seat, and should not fall out when the rail is inverted.

---

### FF-02 — Beeswax Plug Flush with Tube End

**Risk:** If the wax plug is not flush with the tube bottom end, the instrument appears unfinished and the tube will not sit level in the frame pocket.  
**Severity:** L · **Likelihood:** M  
**Mitigation:** After wax cures, trim any overpour flush with a sharp chisel. Sand level.  
**Test:** Visual inspection — no wax should protrude below the tube end. Place tube on a flat surface — it should not rock.

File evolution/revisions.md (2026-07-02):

# Revision Register — siku-zampona

| Rev | Date | Parent | Delta | Downstream artifacts invalidated |
| --- | --- | --- | --- | --- |
| A | 2026-07-01 | — | Stage 0 intake of current masters (cad/siku-zampona.scad + siku-zampona-design-table.xlsx + family-spec.csv). | none (no alpha/beta/production artifacts exist yet) |

Stage 0 only. Gate A has not been run; no Alpha compiles, vendor quotes, or production lock exist for this product.

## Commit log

2026-05-02 Initial scaffold: Siku (Zampoña)
    [siku-zampona-design-table.xlsx]
2026-05-18 Add generated studio explorer (#4)
    * Add generated studio explorer
    * Tighten explorer overview scope
    ---------
2026-05-20 Add build-packet-status, cad/ and images/ placeholders (#5)
    Land a conservative slice against issue #1 ("Generate full build packet").
    The repo is already materially complete via merged PRs #2-#4: design.md,
    assembly-manual.md, BOM, cut-list, sourcing, validation (protocol),
    visual-bom-brief, drawing-brief, supplier-rfq, wolfram-starter +
    wolfram/instrument-model, capstone-deck (md/pptx), capstone-manifest,
    print-packet (md/html/pdf), cnc/, drawings/ (10 SVGs), polished README,
    resources.md, review-evidence.md, learn-to-play/, and explorer.html all
    live in origin/main.
    The only literal gaps against the issue's checklist are cad/ and images/
    folders. data/ is deferred in the issue itself ("a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
2026-05-29 [siku-zampona] V5 uplift: visual-output-register, mcp-session-log, L2 status (Refs #1) (#6)
    Add visual-output-register.csv registering 10 drawings/ SVGs as derived_preview and
    wolfram/ sources as pending_measurement. Add cad/mcp-session-log.md (no external tool
    sessions). Update README header to V5 status line "Status: L2 V5 build-packet candidate".
    Refs #1
    [visual-output-register.csv]
2026-05-31 Add image-gen concept prompt; wire explorer images
2026-06-21 Wire 3 rendered concept image(s) into explorer gallery
2026-07-02 V5 packet refresh: status line, provenance, parametric OpenSCAD master, evolution intake
    - README.md: fixed broken-bold Status line (colon now outside bold markers);
    kept approved L2 V5 build-packet candidate level and Heifer Zephyr branding.
    - New cad/siku-zampona.scad: parametric two-rank (arka 7 + ira 6) closed-pipe
    tube-length envelope, equation-driven (L = c/(4f) - 0.82*bore_ID per
    design.md sec 2.1), variant-aware across Toyo/Zanka/Malta/Chili. Computed
    tube lengths and combined 13-tube frame width match family-spec.csv exactly
    for all 4 variants. Render check: openscad -o STL exit 0. Authority:
    pending_measurement (not fabrication authority).
    - cad/mcp-session-log.md + vis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
    [siku-zampona.scad, visual-output-register.csv]
